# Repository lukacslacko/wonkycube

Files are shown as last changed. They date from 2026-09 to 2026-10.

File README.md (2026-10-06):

# Wonkycube

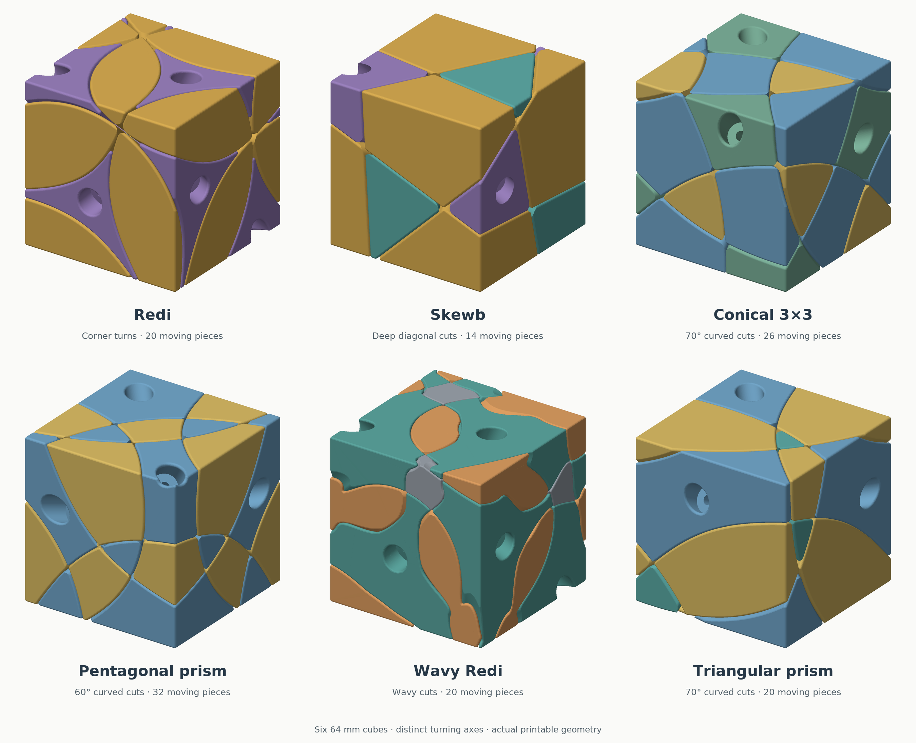
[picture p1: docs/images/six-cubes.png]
Redi, Skewb, conical 3×3, pentagonal prism, Wavy Redi and triangular prism: six 64 mm cube shape mods rendered from the printable models


Six 3D-printable twisty puzzles with **64 mm cube exteriors**, rotated away from their turning axes. Redi, Skewb, conical 3×3, pentagonal-prism, Wavy Redi and triangular-prism designs produce different patterns of cuts and change shape when scrambled. Solve the shape; no stickers are needed.

## Cube shape mods

| Puzzle | What makes it different | Download | Build guide |
|---|---|---|---|
| **Redi** | Eight corner axes; twelve movable edges with distinct outside shapes | [STLs, plates and source](https://github.com/lukacslacko/wonkycube/releases/tag/v4.3) | [Printing and assembly](designs/redi-v4.3/ASSEMBLY.md) · [Piece map](designs/redi-v4.3/NEIGHBORS.md) |
| **Skewb** | Deep planar cuts and diagonal turns; fourteen moving pieces | [STLs, plates and source](https://github.com/lukacslacko/wonkycube/releases/tag/skewb-v1.1) | [Printing and assembly](designs/skewb-v1.1/ASSEMBLY.md) · [Piece map](designs/skewb-v1.1/NEIGHBORS.md) |
| **Conical 3×3** | Six face axes and 70° conical cuts; curved edges and twenty-six moving pieces | [STLs, plates and source](https://github.com/lukacslacko/wonkycube/releases/tag/conical-3x3-v1.1) | [Printing and assembly](designs/conical-3x3-v1.1/README.md) · [Piece map](designs/conical-3x3-v1.1/NEIGHBORS.md) |
| **Pentagonal prism** | Seven axes and 60° conical cuts; 180° side turns, 72° polar turns and thirty-two moving pieces | [STLs, plates and source](https://github.com/lukacslacko/wonkycube/releases/tag/pentagonal-prism-v1) | [Printing and assembly](designs/pentagonal-prism-v1/README.md) · [Piece map](designs/pentagonal-prism-v1/NEIGHBORS.md) |
| **Wavy Redi** | Eight corner axes, twelve broad petals and six exposed patches of the fixed core | [STLs, plates and source](https://github.com/lukacslacko/wonkycube/releases/tag/wavy-redi-v1.1) | [Printing](designs/wavy-redi-v1.1/README.md) · [Assembly and piece map](designs/wavy-redi-v1.1/ASSEMBLY.md) |
| **Triangular prism** | Five axes and 70° conical cuts; 180° side turns, 120° polar turns and twenty moving pieces | [STLs, plates and source](https://github.com/lukacslacko/wonkycube/releases/tag/triangular-prism-v1) | [Printing and assembly](designs/triangular-prism-v1/README.md) · [Piece map](designs/triangular-prism-v1/NEIGHBORS.md) |

All six cube shape mods have been printed by the designer. The 64 mm non-wavy triangular prism printed, assembled and turns well. The Wavy Redi built very well and turns great; its published v1.1 makes two small refinements to nut fit and four exterior tips, checked in CAD and awaiting a reprint. Colors in the render distinguish piece families for illustration; the files can be printed in any colors.

## Vertex-turning rhombic dodecahedron

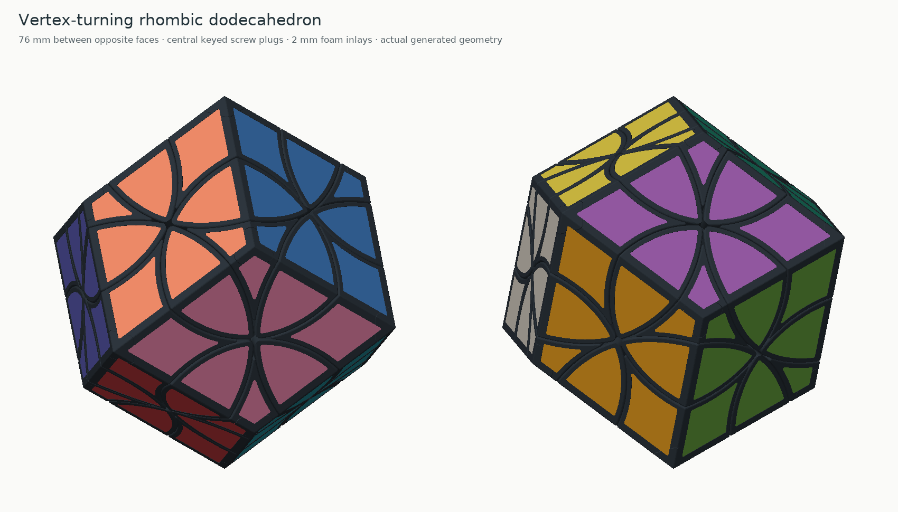
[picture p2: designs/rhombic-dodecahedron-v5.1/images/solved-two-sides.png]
Vertex-turning rhombic dodecahedron with colored inlays, rendered from the printable models


A naturally aligned **rhombic dodecahedron, 76 mm between opposite faces**, with eight threefold centers, six fourfold centers and twenty-four interchangeable petals. The projecting vertices give a grip around every turn axis: 120° at threefold vertices and 90° at fourfold vertices. Concentric spherical-shell shoulders retain the petals.

**Printed, built very well and turns smoothly.** Its twelve rhombic faces take **96 flat 2 mm inlays**, either cut from foam or printed in plastic. Small keyed plugs cover the screws and complete the face dividers. The rigid inlays use exact pocket contours for the snug nominal-size fit demonstrated by the owner; print with **0.00 mm XY contour compensation**.

[Download the complete puzzle](https://github.com/lukacslacko/wonkycube/releases/tag/rhombic-dodecahedron-v5.1) · [Build guide](designs/rhombic-dodecahedron-v5.1/README.md) · [Printable inlays](designs/rhombic-dodecahedron-v5.1/inlays/printable/README.md) · [Piece map](designs/rhombic-dodecahedron-v5.1/NEIGHBORS.md) · [Build feedback](designs/rhombic-dodecahedron-v5.1/physical-feedback.json)

## Curvy Copter cuboctahedron

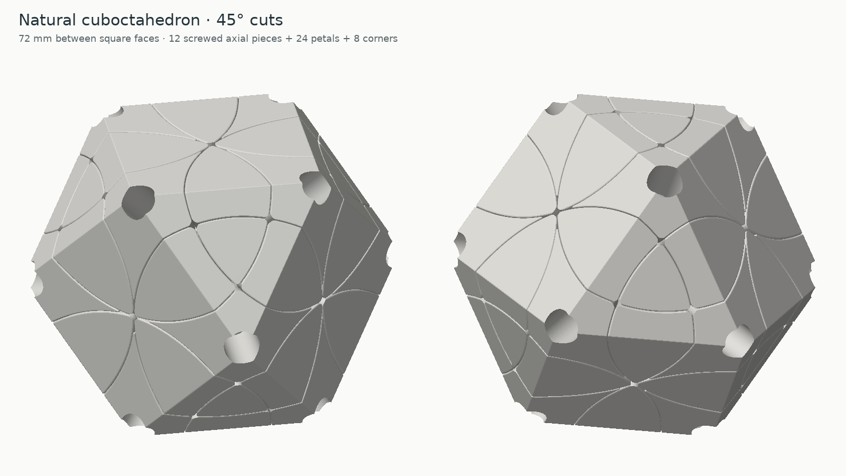
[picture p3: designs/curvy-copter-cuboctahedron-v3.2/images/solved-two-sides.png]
Natural vertex-turning cuboctahedron with Curvy Copter cuts


A naturally aligned **72 mm vertex-turning cuboctahedron** with twelve screwed centers, twenty-four petals and eight floating corners. It has 45° conical cuts, ordinary 180° turns and jumbling moves at suitable partial alignments. Paint the exterior faces with colors or symbols for solving.

**Printed and built very well.** Spherical-shell shoulders retain petals under the screwed centers and corners under the petals. The published v3.2 includes wider petal grooves, tip rounding through the exterior surface and R1.2 rounding of the center-flange outline while preserving its bearing faces. The original vertex-turning cuboctahedron core can be reused.

[Download STLs, plates and source](https://github.com/lukacslacko/wonkycube/releases/tag/curvy-copter-cuboctahedron-v3.2) · [Build guide](designs/curvy-copter-cuboctahedron-v3.2/README.md) · [Piece map](designs/curvy-copter-cuboctahedron-v3.2/NEIGHBORS.md) · [Build feedback](designs/curvy-copter-cuboctahedron-v3.2/physical-feedback.json)

## Double Ivy

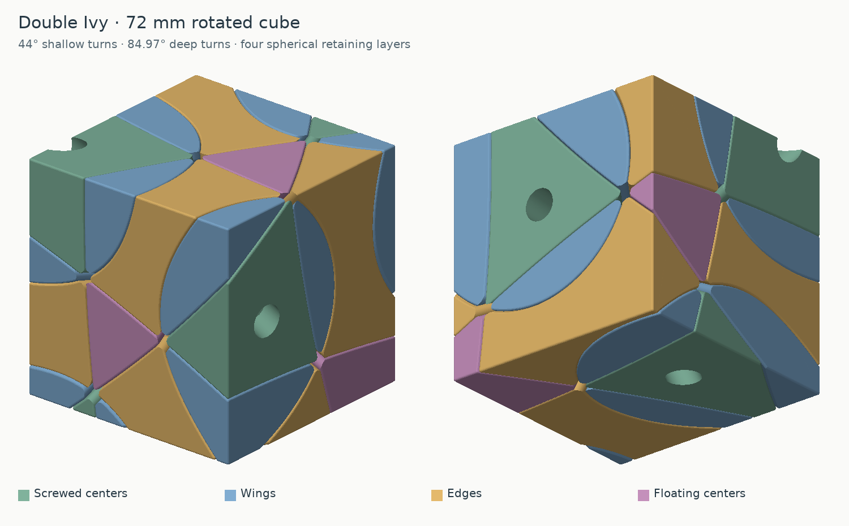
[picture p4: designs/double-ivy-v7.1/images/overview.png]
Double Ivy: a rotated cube with shallow and deep corner turns


A **72 mm rotated cube** with four tetrahedral axes, shallow 44° and deep 84.97° cuts, and twenty-six moving pieces. Four spherical retaining layers hold floating centers under edges, edges under wings, and wings under screwed centers.

**Printed, assembled and turns quite well after working it in.** Two deep turns initially bound and improved with repeated turning. The supplied v7.1 adds a checked outer-ridge rounding correction, which has not yet been reprinted. It includes the compatible tighter nut-seat core for new builds.

[Download STLs, plates and source](https://github.com/lukacslacko/wonkycube/releases/tag/double-ivy-v7.1) · [Build guide](designs/double-ivy-v7.1/README.md) · [Assembly and neighbors](designs/double-ivy-v7.1/ASSEMBLY.md) · [Build feedback](designs/double-ivy-v7.1/physical-feedback.json)

## Make one

Each puzzle uses a printed core, integral retaining feet, **DIN912 M3 × 20 screws** and **DIN985 M3 locknuts**. The six 64 mm cube shape mods, Double Ivy and Curvy Copter cuboctahedron use **9 × 1 mm washers**; the rhombic dodecahedron uses **7 × 0.5 mm washers**, all with M3 clearance holes. The turning mechanisms need no glue or separate hidden printed carriers. Glue is optional for the rhombic dodecahedron’s decorative inlays.

| Puzzle | Printed puzzle parts, including core | Screws / washers / nuts |
|---|---:|---:|
| Redi | 21 | 8 of each |
| Skewb | 15 | 4 of each |
| Conical 3×3 | 27 | 6 of each |
| Pentagonal prism | 33 | 7 of each |
| Wavy Redi | 21 | 8 of each |
| Triangular prism | 21 | 5 of each |
| Rhombic dodecahedron | 53, plus 96 optional printed inlays | 14 of each; **7 × 0.5 mm washers** |
| Curvy Copter cuboctahedron | 45 | 12 of each; **9 × 1 mm washers** |
| Double Ivy | 27 | 4 of each; **9 × 1 mm washers** |

Development used a **Bambu Lab P1S, 0.4 mm nozzle and PLA**. Print at **100% scale** in millimetres. Each build guide covers orientations, supports, nut-fit coupons and assembly guidance. The 3MF plates contain geometry, not a printer profile or G-code. Parts belong to their own mechanism and are not interchangeable between the puzzles.

**Captive nut design:** use the self-contained [DIN985 M3 nut-slot specification](docs/design.md#captive-din985-m3-nut-slot-specification) when designing a part: **5.25 mm terminal seat / 5.85 mm entrance**. The guide defines the taper, axial capture, print orientation and installation-torque fit check. The supplied Redi v4.3 core can let some nuts spin during installation; consult its fit dimensions before printing it.

## Design and modify

Concentric spherical-shell retaining shoulders are the default for new designs: their broad holding faces oppose radial withdrawal. Wider tracks and continuous rounded ridges help pieces pass one another. Screw adjustment controls bearing pressure separately from track clearance.

The [mechanism design guide](docs/mechanism-principles.md) explains these choices, including nut retention, printable flange tips, assembly paths and strong connections around washer wells.

| Design | Mechanism | CAD and regeneration | Checks |
|---|---|---|---|
| Redi | [Design](docs/design.md) | [Source](designs/redi-v4.3/source/README.md) | [Validation](designs/redi-v4.3/VALIDATION.md) |
| Skewb | [Design](designs/skewb-v1.1/DESIGN.md) | [Source](designs/skewb-v1.1/source/README.md) | [Validation](designs/skewb-v1.1/VALIDATION.md) |
| Conical 3×3 | [Design](designs/conical-3x3-v1.1/DESIGN.md) | [Source](designs/conical-3x3-v1.1/source/README.md) | [Validation](designs/conical-3x3-v1.1/VALIDATION.md) |
| Pentagonal prism | [Design](designs/pentagonal-prism-v1/README.md#mechanism) | [Source](designs/pentagonal-prism-v1/source/BUILD.md) | [Validation](designs/pentagonal-prism-v1/VALIDATION.md) |
| Wavy Redi | [Design](designs/wavy-redi-v1.1/README.md#mechanism-choices) | [Source](designs/wavy-redi-v1.1/source/README.md) | [Validation](designs/wavy-redi-v1.1/VALIDATION.md) |
| Triangular prism | [Design](designs/triangular-prism-v1/README.md#retention-and-fit) | [Source](designs/triangular-prism-v1/source/BUILD.md) | [Validation](designs/triangular-prism-v1/VALIDATION.md) |
| Rhombic dodecahedron | [Design](designs/rhombic-dodecahedron-v5.1/README.md#mechanism-and-validation) | [Source](designs/rhombic-dodecahedron-v5.1/source/BUILD.md) | [Validation and build feedback](designs/rhombic-dodecahedron-v5.1/VALIDATION.md) |
| Curvy Copter cuboctahedron | [Design](designs/curvy-copter-cuboctahedron-v3.2/README.md#mechanism) | [Source](designs/curvy-copter-cuboctahedron-v3.2/source/BUILD.md) | [Validation and build feedback](designs/curvy-copter-cuboctahedron-v3.2/VALIDATION.md) |
| Double Ivy | [Design](designs/double-ivy-v7.1/DESIGN-NOTES.md) | [Source](designs/double-ivy-v7.1/BUILD.md) | [Validation and feedback](designs/double-ivy-v7.1/VALIDATION.md) |

Designed and physically iterated by **László Lukács**, with CAD, optimization and documentation developed with **OpenAI Codex**. Source, documentation and original generated models are available under the [MIT license](LICENSE).

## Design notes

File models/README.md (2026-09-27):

# Model versions

Downloads and build guides for all six 64 mm cube designs are listed in the [project overview](../README.md#choose-a-cube), including the [non-wavy triangular prism](../designs/triangular-prism-v1). These are separate mechanisms; their parts do not interchange.

The directory named `current` is retained from the first publication and contains
the **80 mm v4.2.1** files. It is kept intact so earlier hashes and reproduction
scripts remain valid. It is not the latest compact set, and its parts and hardware
do not interchange with v4.3.

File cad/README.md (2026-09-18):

# CAD and reproduction — 80 mm v4.2.1

This directory and the root `scripts/reproduce.py` reproduce the older 80 mm
version. For compact v4.3 use [its source and build instructions](../designs/redi-v4.3/source/README.md).
For the trimmed Skewb v1.1 use [the Skewb source and build instructions](../designs/skewb-v1.1/source/README.md).

Python 3.11 was used for the publication export. Dependencies are pinned in [requirements.txt](../requirements.txt). No OpenSCAD or proprietary CAD runtime is required.

From the repository root:

```sh
python3.11 -m venv .venv
.venv/bin/python -m pip install -r requirements.txt
.venv/bin/python scripts/reproduce.py --out build/reproduced
```

On Windows, use `.venv\Scripts\python.exe`. The reproduction script builds into a new directory and runs the mechanism, revision, radius and shape checks. It stops on any failure and will not overwrite an existing output directory. Computation can take several minutes. Exact STL byte ordering can depend on library/platform details; the geometric checks are the acceptance criteria. Released file hashes identify the specific checked export.

## Source map

| File | Role |
|---|---|
| `mechanism.py` | Shared geometry, axes, transforms and original prototype primitives |
| `poc_mechanism.py` | Direct-to-plastic screw core and early flat-foot prototype |
| `mechanism_v3.py` | 80 mm stepped-rail geometry, proper feet, exterior rounding and hardware envelopes |
| `exact_assembly_sweep.py` | Nonconvex axial insertion envelope |
| `mechanism_v4.py` | Unrounded flange sweep, wider tracks and internal rounding |
| `mechanism_v4p1.py` | Earlier 2 mm ridge fillets with an inner blend |
| `mechanism_v4p2.py` | Constant 3 mm transverse ridge fillets following the inner track |
| `build_v4p2.py` | Current export, using the fixed v4.1 baseline |
| `v3_io.py` | Closed STL export and geometry-only 3MF writer |
| `verify_v3.py` | General saved-mesh, motion, hardware and assembly verifier (name retained) |
| `verify_v4p2.py` | Revision locality, mixed old/new motion, retention and misalignment probe |
| `verify_radii_v4p2.py` | Section fits on the actual print STLs |
| `check_edge_shapes_v3.py` | All 66 edge-exterior pair comparisons |
| `optimize_rotation.py` | Original exterior-orientation search |
| `draw_v4p2.py`, `mesh_render.py` | Actual mesh-section diagrams and software-rendered previews |

## Changing the design

The fast current build starts from [baseline](baseline), not from a single fully parametric solid. That is intentional: the latest revision removes only ridge material while preserving printed interfaces. Adjust `RADIAL_RIDGE_ROUND` in `mechanism_v4p2.py` to experiment with that cut, then update the radius verifier's explicit target and rerun all relevant checks. A bigger radius can remove retention material and is not automatically safe.

To change the exterior, hardware, core or original rail, rebuild the chain from its source. Run these from the repository root, using fresh output paths:

```sh
.venv/bin/python cad/build_v3.py --out build/v3p1
.venv/bin/python cad/build_v4.py --base build/v3p1 --out build/v4
.venv/bin/python cad/build_v4p1.py --base build/v4 --out build/v4p1
.venv/bin/python cad/build_v4p2.py --base build/v4p1 --out build/new-design
```

These earlier generators are preserved for design work. The publication check starts at the supplied baseline; a complete fresh upstream rebuild is not claimed byte-identical to historical archives. Rounding is expensive, and parameter changes can produce thin/disconnected geometry that requires redesign rather than export repair. Validate each stage before relying on the next. Any source constants used by verification must agree with the generated geometry.

The original optimization uses a 100 mm cube for scoring. Uniform exterior size changes scale those scores, not the selected orientation. Its `rotation.json` output is an exploration result; the retained `chosen_rotation.json` also includes an equivalent symmetry relabeling. Do not automatically replace the chosen rotation when reproducing the released shape.

For individual current checks:

```sh
.venv/bin/python cad/verify_v3.py --out models/current
.venv/bin/python cad/verify_v4p2.py --base cad/baseline --out models/current
.venv/bin/python cad/verify_radii_v4p2.py --out models/current
.venv/bin/python cad/check_edge_shapes_v3.py --out models/current
```

These commands rewrite their JSON reports. Use a copied output folder when preserving a published checksum manifest.

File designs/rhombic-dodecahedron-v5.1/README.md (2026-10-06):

# Vertex-turning rhombic dodecahedron — spherical retention and 2 mm inlays

The generated puzzle, with example foam colors

A fourteen-axis puzzle with **8 threefold centers, 6 fourfold centers and 24 floating petals**. Threefold vertices turn 120°; fourfold vertices turn 90°. Each turning axis has a projecting vertex to grasp. Its twelve rhombic faces carry **96 flat 2 mm inlays**, either cut from foam or printed in plastic.

**76 mm between opposite faces, 107.48 mm between the longest opposing vertices, and 93.08 mm between opposite threefold vertices.** Print at 100% scale: the hardware, clearances and foam thickness are fixed dimensions.

Each screwed center keeps its **complete outer rim, most of the foam-pocket floors and the divider walls away from the screw**. A small central plug closes the screw well and completes the inner three- or four-way divider pattern. Its rounded triangular or square section locates it at the appropriate 120° or 90° orientations.

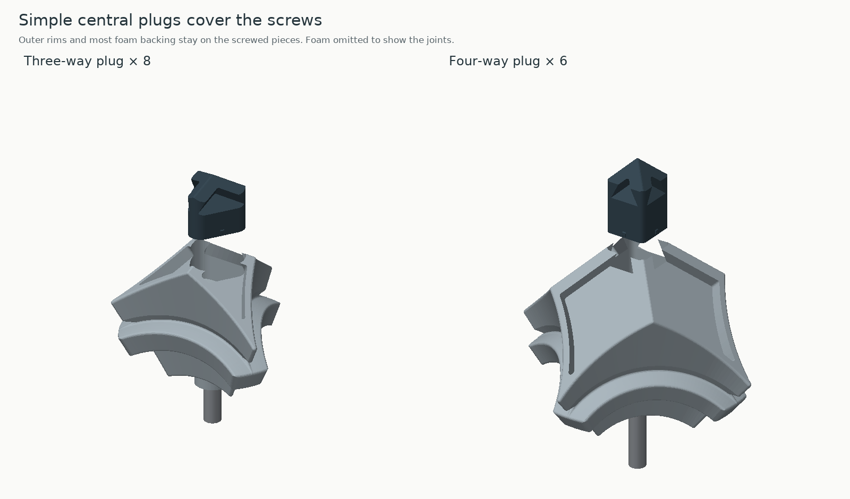
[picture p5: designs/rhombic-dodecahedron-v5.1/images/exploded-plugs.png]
Central plugs lifted from the screwed pieces


The **foam spans the joint between the main piece and the plug**. Fit and adjust the puzzle first, then glue the foam over both as desired. To service a screw later, remove the affected center's foam, pull the plug, and replace the foam after adjustment. The cutting sheets are provided for that purpose; the design does not depend on preserving the foam during disassembly.

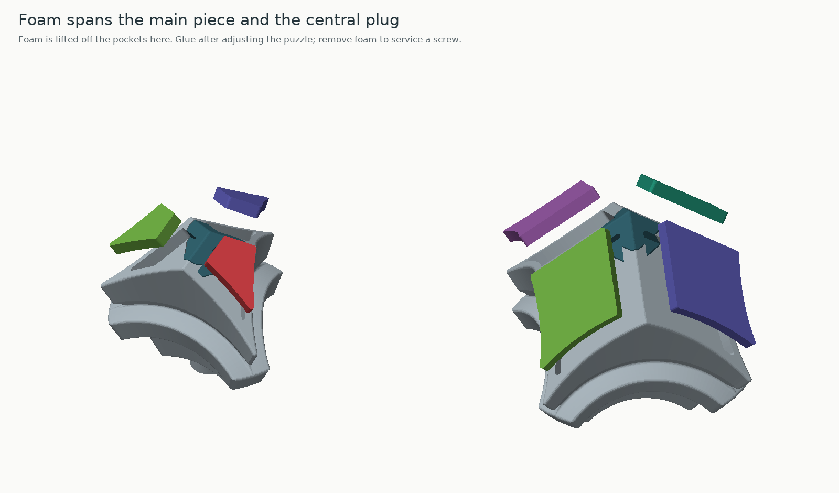
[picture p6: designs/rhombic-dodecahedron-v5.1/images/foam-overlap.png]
Foam lifted to show the shared pocket floors


Threefold-center inlay panels are approximately **54.49 mm² each**, and fourfold-center panels **194.49 mm² each**. Use the complete set of screwed bases, petals, plugs and cutting sheets together. The retaining interfaces and foam recesses match this set; do not mix surface pieces from the stepped-retention or 3 mm-foam sets. Only the central screw region is split; the outer rim has no cap joint or pry notches.

The **face-turning cuboctahedron v1 core is directly reusable**, with its nuts left in place. The supplied core has the identical SHA-256 `2424250181e27338f25ef90b7bbe66e7d5ba9beca6b5c5e347a9555a172ab8cc`. This means the fourteen-axis face-turning puzzle's core. The twelve-axis curvy-copter core does not fit. All surface parts and cutting sheets in this package match the 76 mm exterior and should be used together.

**Printed and built very well, and turns smoothly**, as reported by the owner. The nominal-size rigid inlays fit nicely snugly. See [physical feedback](physical-feedback.json) and the [validation summary](VALIDATION.md) for the supplied geometry, exact inlay fit evidence and scope of the CAD checks.

## Print list

| File in `stl/puzzle/` | Copies | Role |
|---|---:|---|
| `threefold-center-print-8.stl` | 8 | T01–T08 screwed bases |
| `threefold-plug-print-8.stl` | 8 | Central threefold plugs for T01–T08 |
| `fourfold-center-print-6.stl` | 6 | S01–S06 screwed bases |
| `fourfold-plug-print-6.stl` | 6 | Central fourfold plugs for S01–S06 |
| `petal-print-24.stl` | 24 | P01–P24 floating petals |
| `core.stl` | 1, or reuse | Fourteen captive nuts |

There are **53 printed puzzle parts including the core**, forming 38 moving units. Every copy within a family is identical. The three geometry-only 3MF plates in `plates/` contain the required quantities, with SVG placement maps. The center/core plate includes a core: delete it in the slicer if reusing yours. Use either the plates or the STL quantities, not both. Files under `reference/` show the assembled puzzle and are not print plates.

Additional files:

- `stl/fit-coupons/cap-key-fit-tests.3mf`: two socket/peg pairs; also supplied as four separate STLs.
- `stl/fit-coupons/foam-pocket-test.stl`: tests actual foam thickness and cutting fit.
- `stl/fit-coupons/nut-fit-5.25.stl`: useful if printing a new core.
- `stl/optional/assembly-stand.stl`: optional temporary assembly tool.

Suggested P1S / PLA / 0.4 mm nozzle settings: 0.16 mm layers, five walls, five top/bottom layers, and 25–30% infill for the moving parts. Use six walls and 40% infill for a new core. For the main pieces and petals, start with automatic tree supports on the build plate only and a 5–6 mm brim. Inspect support under the retaining shoulders. The compact plugs stand on flat key bottoms and can be printed without supports; use five top/bottom layers and inspect the small friction ribs in the slicer. The key fit samples also print without support.

The STL orientations put the inward radial direction down and the foam pockets upward. Avoid shaving the small key ribs during cleanup. Remove any elephant's foot at a key's entry. Plate spacing allows the suggested brims; the 3MF files contain geometry rather than printer/material presets. Layer-connectivity checks pass at both 0.16 and 0.20 mm layers; these are geometric extrusion-width checks, not actual Bambu toolpaths.

## Plug fit and removal

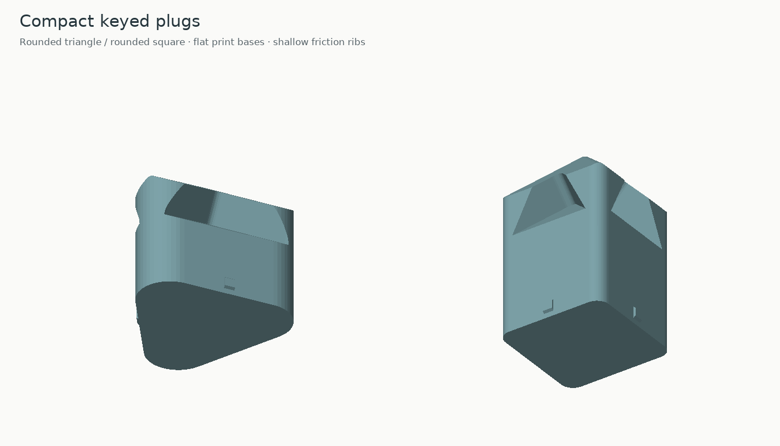
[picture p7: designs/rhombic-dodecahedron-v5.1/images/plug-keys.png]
Compact plugs and their locating keys


The whole plug is a rounded triangular or rounded square key; there is no large removable foam carrier. It has a flat bottom, a pocketed top matching the exterior, and small tapered ribs on its sides for light friction. The main piece retains the surrounding divider walls and pocket floors.

| Feature | Dimension |
|---|---:|
| Female key across flats | 8.00 mm |
| Socket corner rounding, triangular / square | R2.25 / R1.00 mm |
| Rigid male-key clearance | 0.12 mm per side |
| Small tapered friction ribs | 0.04 mm beyond the socket flat |
| Threefold plug clearance above seated screw head | 1.10 mm |
| Fourfold plug clearance above seated screw head | 9.20 mm |

The ribs provide localized friction while the rest of the key has clearance. Print the key samples at the final layer height. Push the ribbed end of each tall peg into its matching shallow socket. It should seat with modest hand pressure, stay in when inverted and remain removable. If tight, scrape only the ribs lightly. If loose, adjust the rib fit rather than scaling the entire part. A full pair is the final fit test.

Test the plugs before fitting any foam. Press them down until their outer surfaces and divider walls align with the main piece. To remove a plug, first remove that center's foam, then grip the central divider with fingers or protected pliers, or lift gently at the exposed plug joint. Pull along the screw axis; the key prevents free twisting. Do not glue the key into its socket. Gluing the foam across the top joint is intentional and acceptable.

## Hardware

- 14 × DIN912 M3×20 socket-head screws.
- 14 × M3 washers, **7 mm outside diameter × 0.5 mm thick**.
- 14 × DIN985 M3 nylon locknuts.
- A 2.5 mm hex key; a blunt metal rod for seating nuts in a new core.

No extra screws, magnets or fasteners are required for the plugs. The wells are Ø7.6 mm and the rotating screw bores Ø3.6 mm. Washer seats lie 32.0 mm along T axes and 27.3 mm along S axes. The plug sockets pass the washers and driver when the plugs are removed.

The nut pocket has a **5.25 mm terminal across-flats size**, a 5.85 mm entrance, a 3 mm tapered transition and a 3 mm tight run to the seated nut. Pocket height is 4.25 mm, with a 1.95 mm roof. Press each nut firmly home with its metal entry face outward and nylon ring inward. Confirm resistance to the nylon ring's installation torque before building around the core.

## Assembly

1. Seat and torque-check the nuts if using a new core. Leave the plugs and foam off.
2. Assemble a **loose, interlocked shell** around the core, keeping all fourteen centers unscrewed. Add petals between their T and S neighbors, engaging their inner feet beneath the spherical flanges. Use `NEIGHBORS.md` and temporary masking tape to support the loose pieces. Keep the whole shell somewhat expanded while adding parts; do not fasten one side tightly first.
3. If using the optional stand to support the core initially, remove it **while the shell is still loose**, then add S01. It is not intended to reserve a final straight-in slot after tightening the rest.
4. Gradually close the shell, easing neighboring centers and petals inward together. Fit washers and start screws once the pieces are seated. Tighten all fourteen progressively and evenly. The full shoulders mean a final center cannot simply be pushed straight into already fixed petals.
5. Adjust until the petals are supported without binding. M3 coarse pitch is 0.5 mm per revolution; one fifth of a turn changes head position by 0.10 mm. Judge tension by movement, separately from the nut's nylon-ring resistance.
6. Test all turns with the plugs seated and without glued foam. Remove plugs for any further screw adjustment.
7. Once satisfied, fit and glue the foam one numbered face at a time. Center foam may be glued over both the main piece and its plug. Petal foam is glued to its petal. Keep glue out of moving seams and allow it to cure before turning.

The CAD assembly check constructs a loose state with centers 12 mm outward and petals 11.4 mm outward from their seated positions. Each part has a clear radial entry into that state. A coordinated contraction, with petals moving 0.95 mm per 1 mm of center travel, then reaches the seated shell without collision. These are coordinates of a verified construction, not distances you need to measure by hand. Several pieces must remain movable together; this is not a last-piece snap-fit. The owner has also successfully assembled the complete physical puzzle; the CAD path is one construction, not a measurement of the exact hand assembly sequence used.

## Foam and cutting files

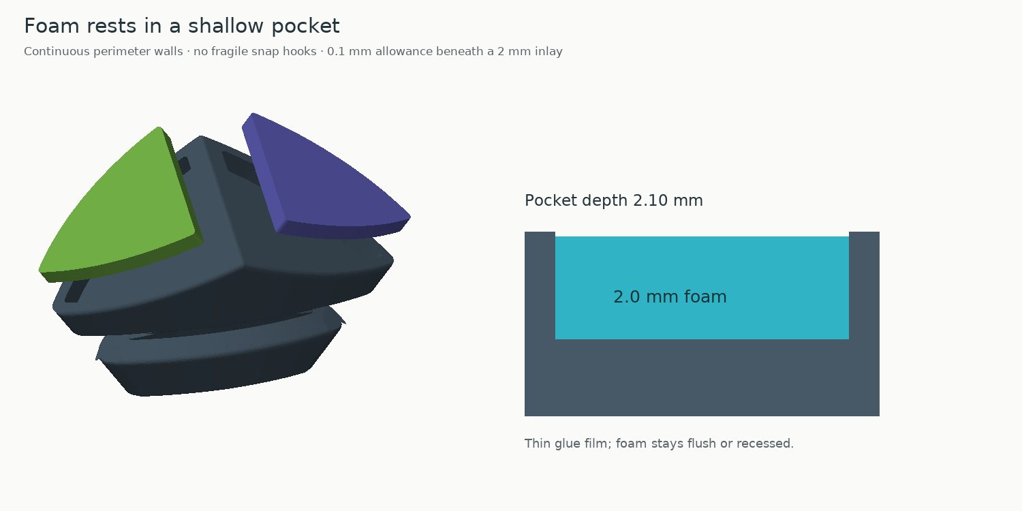
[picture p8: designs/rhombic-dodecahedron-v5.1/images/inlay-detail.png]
Foam pocket relationship


There are **96 inlays: eight per rhombic face**. Each assembled T center has three, each S center four, and each petal two. Recesses are **2.10 mm deep for 2.00 mm foam**. Without glue the foam lies 0.10 mm below the plastic; a thin glue film can bring it flush. Do not allow foam or adhesive to protrude into the moving seams.

Continuous pocket walls grip the foam by slight compression; there is no overhanging snap hook. The nominal outer border is 1.0 mm, widened where needed. Adjacent-face recesses leave at least **1.6 mm of plastic between their full-depth voids**. The generated pockets preserve a 1.2 mm underlying floor envelope and 0.775 mm lateral web before the central plug is separated. The assembled pocket floor is checked to remain supported everywhere except the narrow plug-fit joint. Foam bridges that joint.

The Cameo files contain **closed outline cuts only**, without text, borders, registration marks or duplicate outlines. Each F01–F12 file contains the eight inlays for one face. Cut each face once, one color per face; with fewer colors, add markings to distinguish the faces. No mirroring is needed with the foam's colored side upward.

Use the **DXF** files for Silhouette Studio Basic. SVG import requires Designer Edition or above. Genuine DWG is supplied as the requested CAD format, but Silhouette's listed import formats do not include DWG. See the official [file-format guide](https://silhouetteamerica.freshdesk.com/support/solutions/articles/35000282776-file-types-and-features) and [DXF guidance](https://silhouetteamerica.freshdesk.com/support/solutions/articles/35000276938-importing-and-exporting-troubleshooting).

DXFs are R13 ASCII with closed 2D POLYLINEs. SVGs have explicit millimetre dimensions. DWGs are AutoCAD 2000 / AC1015, encoded with ODA and independently read back with LibreDWG; each resulting contour is compared with its source. Curve simplification tolerance is 0.008 mm.

### Select the foam fit before cutting the full set

1. Import `inlays/fit-test/calibration-20mm.dxf`. Verify a **20.00 × 20.00 mm** selection and measure the cut sample. DXF import settings can affect scale.
2. Print the pocket sample and cut `inlays/fit-test/foam-size-options.dxf` in the actual foam. Left to right: easy, standard, firm. Choose the smallest that stays flat and grips as desired.
3. Use **one complete cutting set** below. Select blade/pass settings for your Cameo model and actual foam; no untested machine preset is supplied.

| Set | Folder | Offset from pocket outline |
|---|---|---|
| Easy | `inlays/fit-variants/easy/` | −0.04 mm per side |
| Standard | `inlays/faces/` | +0.04 mm per side |
| Firm | `inlays/fit-variants/firm/` | +0.12 mm per side |

These are contour offsets, not uniform scale factors. All variants match the same printed pockets. Check the selected outlines rather than the 82 mm SVG page. Exact selection bounds for each face and fit variant are in `reports/cutting-files.json`; use the supplied 20 mm calibration square to confirm import scale.

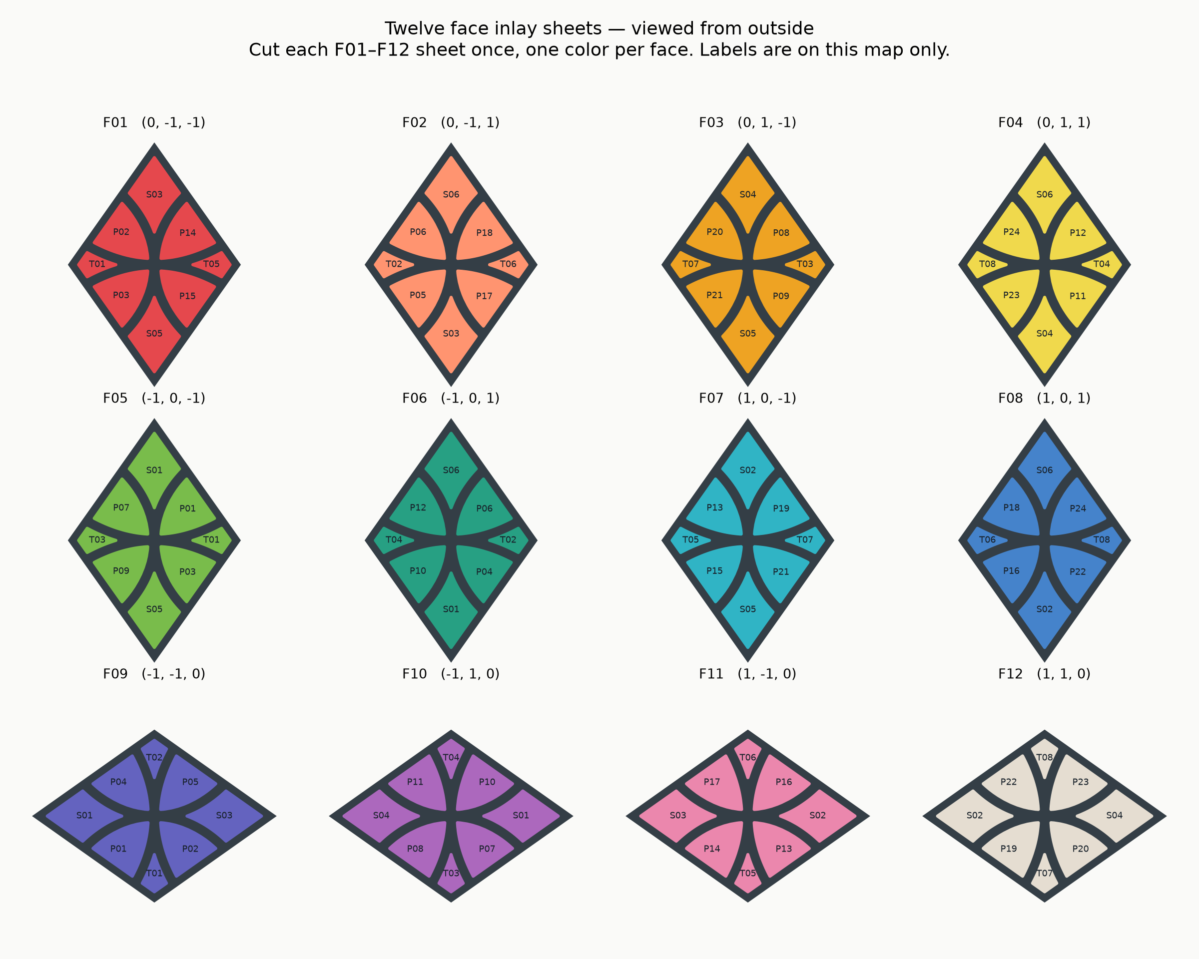
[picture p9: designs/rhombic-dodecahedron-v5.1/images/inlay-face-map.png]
Face-by-face cutting and placement map


The map is viewed from outside in the same orientation as each cutting sheet. Keep a face's eight cut pieces together. The T and S labels identify the assembled screwed centers; P labels identify petals. Use only the cutting sheets supplied with these 76 mm parts.

## 3D-printed inlays

You can mix **2 mm printed plastic inlays** with foam on any faces. The existing puzzle parts and 2.1 mm pockets accommodate both. Use `inlays/printable/faces/F01.3mf` through `F12.3mf`, or their matching STLs, to print the eight separate inserts for a selected color/face. Individual replacements are under `inlays/printable/individual/Fxx/`. Print each selected face once, using either its STL or its 3MF.

The rigid inserts **exactly match the pocket contours**, with **zero designed clearance**. Use **0.00 mm XY contour compensation**: do not apply an additional +0.15 mm correction. Nominal-size inlays were reported to fit nicely snugly; a thin glue layer is optional. Keep their tops flush or slightly recessed. Print flat as supplied, visible side upward, at 100% scale; 0.20 mm layers, at least five top/bottom layers, no supports or brim. Print one face first to check physical fit. The face plate contains eight disconnected pieces, with no backing sheet joining moving puzzle parts.

See `inlays/printable/README.md` and its placement map. On screwed centers these inserts still bridge the base/plug joint; finish adjustment before gluing and expect to remove the affected inlays for screw access. The original SVG/DXF/DWG files remain the foam cutting options.

## Mechanism and validation

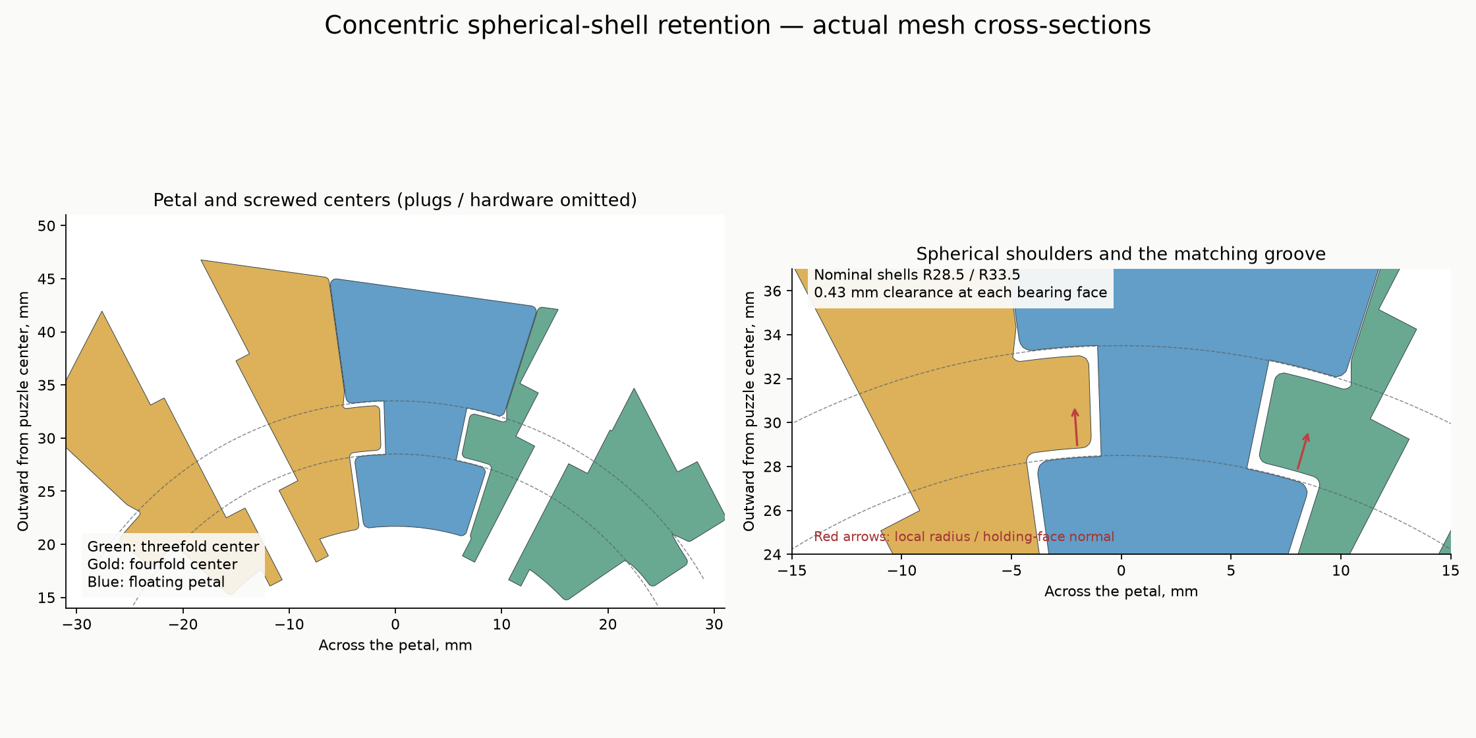
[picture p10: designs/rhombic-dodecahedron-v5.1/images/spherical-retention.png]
Actual spherical retaining shoulders in section


The core anchors the fourteen adjustable centers. The floating petals have inner feet captured below **concentric spherical-shell flanges** on both center families. The nominal shell radii are 28.5 and 33.5 mm, centered at the puzzle origin. Their broad holding faces have normals along the local radius; the small edge transitions are rounded. The center flanges are approximately 4.20 mm thick radially and run in 5.06 mm radial grooves, leaving **0.43 mm at each spherical bearing face**. The inner feet are checked against the screwed centers alone, without crediting contact with neighboring floating bodies. Threefold centers have continuous screw stems; petal tracks clear the stems' full sweep. Exterior cone half-angles are 35.264389683° at the threefold axes and 45° at the fourfold axes.

| Feature | Dimension |
|---|---:|
| Main conical-face gap, total | 0.06 mm |
| Additional track-cutter expansion | 0.37 mm |
| Spherical shoulder / outer return radii, nominal | R28.5 / R33.5 mm |
| Spherical bearing gap, per face / total groove slack | 0.43 / 0.86 mm |
| Hidden neck half-angle, threefold / fourfold | 29.2644° / 39° |
| Center flange-end outline rounding, radial sweep | R1.2 mm |
| Petal radial-ridge rounding, through the tracks | R2 mm |
| Other edge rounding, petal / center | R0.55 / R0.45 mm |
| Core sphere / moving inner cavity | R21.2 / R21.7 mm |
| Core bearing pad / center foot plane | 19.6 / 19.7 mm along axis |
| Foot / rotating bore diameter | 6.2 / 3.6 mm |

Validation reloads the delivered STLs and checks connected watertight parts, washer-root and bore walls, ordinary turns about all fourteen axes at 3° intervals with hardware present, destination fit, sampled petal retention and rocking, inner-foot capture by centers alone with 0.15 mm center lift, coordinated assembly, nut insertion, stand removal, and layer connectivity at 0.16 and 0.20 mm layers. Spherical bearing faces are measured on the exported meshes. Installed foam is checked at flush height during turns and assembly. Plug checks cover extraction after foam removal, screw clearance, shared foam backing, correct key symmetry, unintended rotation and bounded intentional rib interference.

These finite rigid-geometry checks do not establish real press-fit force, fatigue, support quality, foam grip or every possible elastic escape path. Inspect slicer previews and test a pair before committing to all copies. Source and generated design are MIT licensed. `source/BUILD.md` explains regeneration; `reference/design-parameters.json` records dimensions and key profiles; `manifest.json` records quantities, transforms and STL hashes.

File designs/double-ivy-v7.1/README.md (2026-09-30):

# Double Ivy · 72 mm · spherical retainers

Double Ivy rotated cube

A rotated-cube shape mod with **four tetrahedral axes and two 120° turns per axis**: shallow 44° cones and deep 84.96955° cones. It has four screwed centers, twelve wings, six edges and four floating centers. Solve it by restoring the cube shape; the illustration colors identify piece families.

**Printed, assembled and now turns quite well after working it in**, reported by the owner on 2026-09-30. The shallow turns were smooth immediately; two deep turns initially bound strongly and improved with repeated movement. The exact cause was not established. The published v7.1 includes a small **outer-ridge rounding correction that has been checked in CAD but not yet reprinted**. [Physical feedback](physical-feedback.json) · [Validation](VALIDATION.md).

The spherical retaining layers run outward as **floating-center feet → edge feet → wing feet → screwed-center flanges**. A compatible one-piece nut core supports the assembly, with integral E/W bearing webs limiting inward rocking.

## Size and layers

The solved cube measures **72 mm**. Its exterior room keeps assembly clearances beneath the skin while preserving usable retaining shoulders.

| Part family | Hidden layer begins at radius | Nominal retaining-foot limit / collar end | Held by |
|---|---:|---:|---|
| F01–F04 floating centers | 19.5 mm | 22.4 mm | Edges |
| E01–E06 edges | 22.6 mm | 25.55 mm | Wings |
| W01–W12 wings | 25.6 mm | 28.8 mm | Screwed centers |
| C01–C04 screwed centers | 29.0 mm | 31.2 mm | Screws into the old core |

Radii are measured from the puzzle center. The table describes the hidden feet/collars, not the entire visible piece; every part also has a stem/body reaching the outer cube. Profile offsets and rounding move local boundaries slightly. The C bearing stems reach inward to the unchanged core pads; their flanges remain at the outermost retaining level. Integral bearing webs under E and W also reach inward to the spherical core. These webs provide inward support, without adding retaining lips or changing the four flange levels.

The nominal internal profiles are: low deep-cut band R22.4–25.3 at 78°; middle shallow-cut band R25.55–28.45 at 49°; high deep-cut band R28.8–31.2 at 81°. The outer surfaces return to the original 44° / 84.96955° cones.

## What to print

Print **27 puzzle pieces**: C01–C04, W01–W12, E01–E06, F01–F04 and one core, from `stl/puzzle`. The five full-set geometry-only 3MF plates in `plates/` contain exactly these parts. Print in millimetres at **100% scale**. Keep the IDs for [assembly and the complete neighbor map](ASSEMBLY.md).

Use **four DIN912 M3×20 screws, four DIN985 M3 nuts and four 9 mm OD × 1 mm washers**, with M3 clearance. No glue, magnets, split core or separate hidden carriers are needed.

The default core has **5.25 mm final nut seats and 5.85 mm loading entrances**. A 5.20 mm alternative and fit coupons are included; see [CORE.md](CORE.md). The original compatible one-piece double-Ivy core can also be reused, keeping its nuts installed. The grooved/split cores are not substitutes. `reference/reused-core/core.stl` is the archived 5.40 mm-seat core, not the new-build default.

For an existing v7 build, only the eight C/F pieces have changed; the wings and edges are unchanged. The core update is optional for a core whose nuts already hold securely.

## Clearances, rounding and hardware

- 0.30 mm nominal track gap, measured surface-to-surface in the meridian profile; not 0.30 mm removed from each side.
- 0.05 mm main exterior conical-face gap.
- R19.5 floating-center cavity around the original R19.2 core.
- E/W bearing webs have an R19.4 spherical inner surface: 0.20 mm nominal radial clearance to the old core. The webs are clipped to the legal turn cells, with 0.25 mm edge rounding. They need no grooves or changes to the core.
- 2 mm radial-ridge rounding. The C/F exterior correction completes both sides of the arc, blending from ridge station 32.2 to 33.4 mm while preserving the retaining region. About 0.30 mm small internal rounding and 0.60 mm exposed-edge softening remain.
- Original washer seat at 27.3 mm along each screw axis, 9.6 mm access well and 3.6 mm screw bore.
- The higher C flange connects through a thicker, integral stem. Its upper outside diameter is 12.8 mm, giving a nominal 1.6 mm wall around the access well above the washer seat. It tapers back to the original bearing foot.

The broad retaining faces are spherical, centered on the puzzle center. They directly oppose outward lift. Higher grooves in E and F are **passage clearances for other turning flanges**, not extra load-bearing layers. Removing the unused upper E shoulder keeps the intended F–E–W–C order.

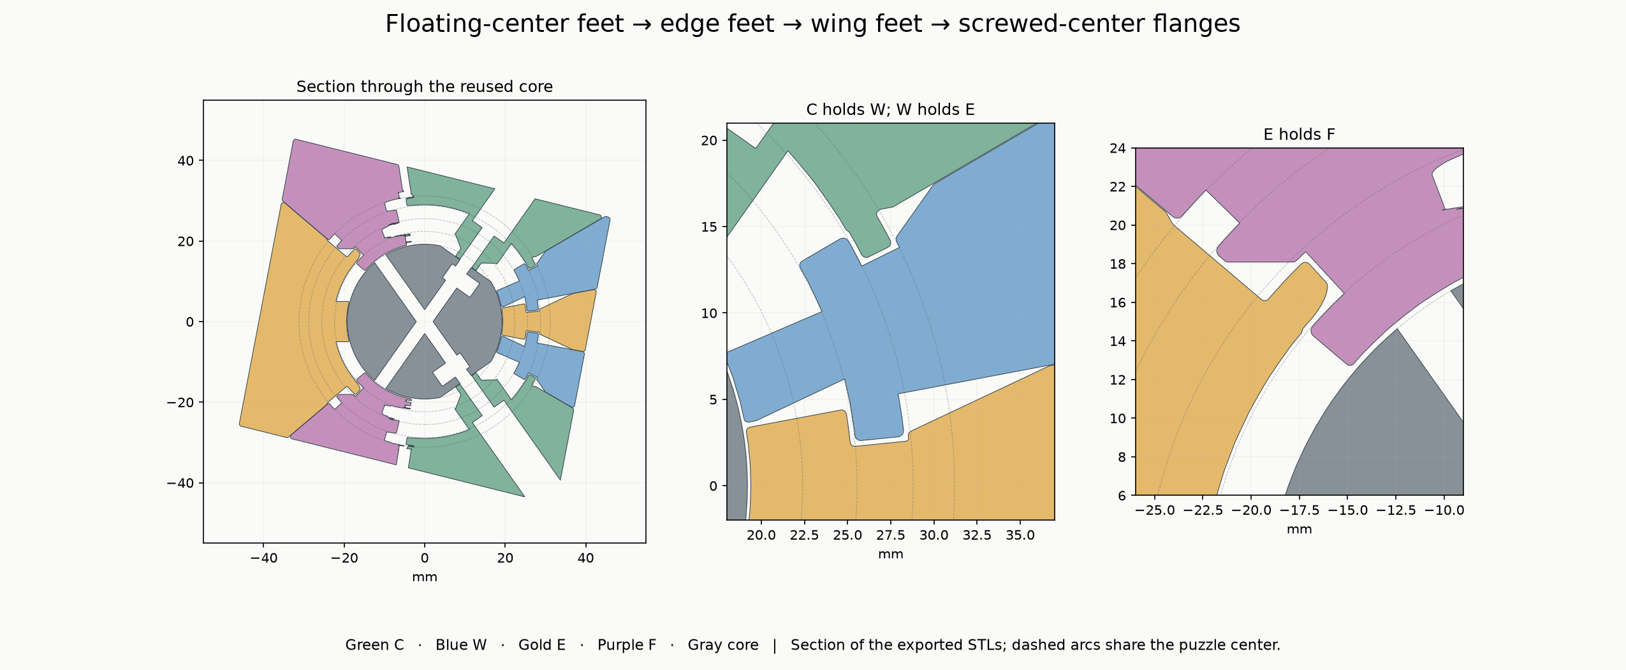
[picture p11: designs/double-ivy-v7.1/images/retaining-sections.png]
Retaining sections


## Printing

Use the proven P1S / 0.4 mm nozzle / PLA process. A starting point is 0.20 mm layers, 4 walls and 15–20% infill. Auto tree supports on the build plate are suitable for an initial slice; inspect the undersides of the collars and add a local support if needed. These geometry-only 3MFs contain names and placements, not filament or support presets.

C pieces rest on a large exterior flat face. W/E/F are oriented with the vector toward the puzzle center pointing down. A brim is helpful on the smaller inward contact patches; inspect the slice to ensure the E/W bearing webs have support where needed. Remove support residue carefully from the sliding surfaces, without shaving away the broad spherical shoulders. Mark the full ID inside each piece before removing it from its plate. The image colors distinguish families only; the puzzle can be printed in one color and solved by shape.

[Assembly sequence and complete neighbor list](ASSEMBLY.md) · [Validation and limits](VALIDATION.md) · [Design notes](DESIGN-NOTES.md) · [Plate maps](plate-maps.html)

Parameterized source, reports and exact print transforms are included under the MIT license.

## Rounding correction

Some symmetric C/F ridges retained a sharp half-rounded shoulder because the tangent detection selected only one side. v7.1 completes the R2 outer arc without changing the internal holding geometry. This removes a confirmed defect; it is not claimed to be the proven cause or cure of the initial binding.

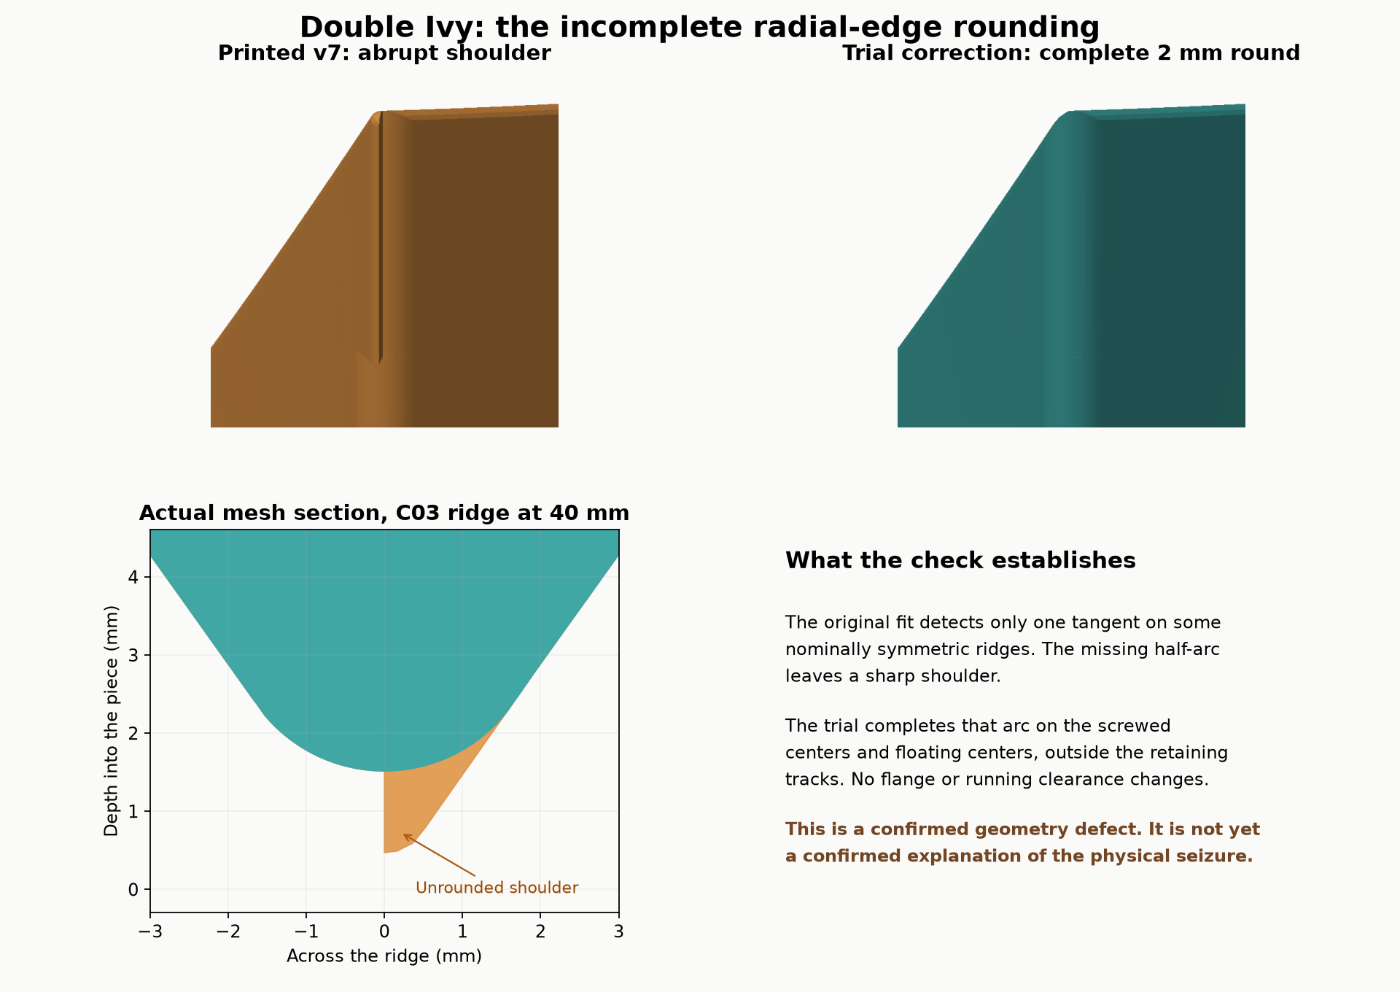
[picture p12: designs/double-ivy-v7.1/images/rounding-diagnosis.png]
Rounding correction


[Source and rebuilding](BUILD.md) · [Design notes](DESIGN-NOTES.md). MIT licensed.

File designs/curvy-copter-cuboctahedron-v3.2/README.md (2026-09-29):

# Curvy Copter cuboctahedron · spherical v3.2

Natural cuboctahedron with 45° conical cuts

A **vertex-turning cuboctahedron** with Curvy Copter mechanics: twelve screwed axial pieces, twenty-four petals, eight floating corners and a one-piece core. It measures **72 mm between opposite square faces**, uses 45° exterior conical cuts, and permits ordinary 180° turns plus jumbling moves at suitable partial alignments. Paint the exterior faces with colors or symbols; the natural alignment does not distinguish every piece by shape alone.

**Printed and built very well**, reported by the owner on 2026-09-29. The supplied spherical-v3.2 print geometry is unchanged. [Build feedback](physical-feedback.json) · [Validation](VALIDATION.md).

## Print the puzzle

| File in `stl/puzzle/` | Quantity |
|---|---:|
| `axial-center-print-12.stl` | 12 |
| `petal-print-24.stl` | 24 |
| `corner-print-8.stl` | 8 |
| `core.stl` | 1 |

There are **45 printed puzzle parts**. Alternatively use the three full-set 3MF plates in `plates/`; together they contain the entire puzzle, including the core. Every copy in one family is identical. Geometry-only 3MF files include positions and names, without printer/material/support presets. Files marked `DO-NOT-PRINT` are reference assemblies.

Hardware: **12 DIN912 M3×20 screws, 12 DIN985 M3 locknuts and 12 washers with 9 mm outside diameter and 1 mm thickness**, with M3 clearance holes. Fit coupons and optional core nut-seat widths are supplied.

The original **64 mm vertex-turning cuboctahedron core is compatible**: its mounting geometry was preserved as the exterior grew to 72 mm. Existing embedded nuts can stay installed. The face-turning cuboctahedron is a separate mechanism with different hardware; its core is not the intended substitute. Do not mix floating pieces from the earlier cylindrical-retention version.

Use the supplied orientations at **100% scale in millimetres**. Development used a P1S, 0.4 mm nozzle, PLA and 0.20 mm layers. Four walls and about 25% infill are starting settings, not a record of the final successful slice. Petals point inward toward the bed; centers and corners rest on an exterior face. Inspect support coverage under retaining shoulders. Build-plate-only tree support works where it reaches the ledges; add support where it otherwise leaves an unsupported surface. Remove support nubs carefully from the tracks.

## Mechanism

The retaining shoulders are cut from **concentric spherical shells**, with nominal radii **28.5 and 33.5 mm**. The bearing faces directly oppose radial withdrawal. Screwed centers retain the petals; petals retain the floating corners. The shell profile transitions through a 40° internal neck to the 45° exterior cuts.

The center flange ends have **R1.2 rounding in their outline viewed radially**, extending through the flange thickness. This preserves the broad spherical bearing lands. Petal R2 radial fillets continue all the way through the exterior face, including the two tips beside each floating corner.

| Working dimension | Value |
|---|---:|
| Nominal center flange radial thickness | 4.42 mm |
| Nominal petal groove radial width | 5.28 mm |
| Gap at each center–petal spherical face | 0.43 mm |
| Total radial groove/flange clearance | 0.86 mm |
| Corner–petal bearing gap | 0.33 mm |
| Main conical body gap | 0.08 mm |
| Radial body/petal fillets | R2 mm |
| Center flange outline corners | R1.2 mm |

The petal groove has 0.20 mm more total width than the original spherical version, split equally between its two bearing walls, to accommodate supported-surface roughness. Keep body clearance separate from this track allowance. Extra clearance cannot compensate for an attached support nub.

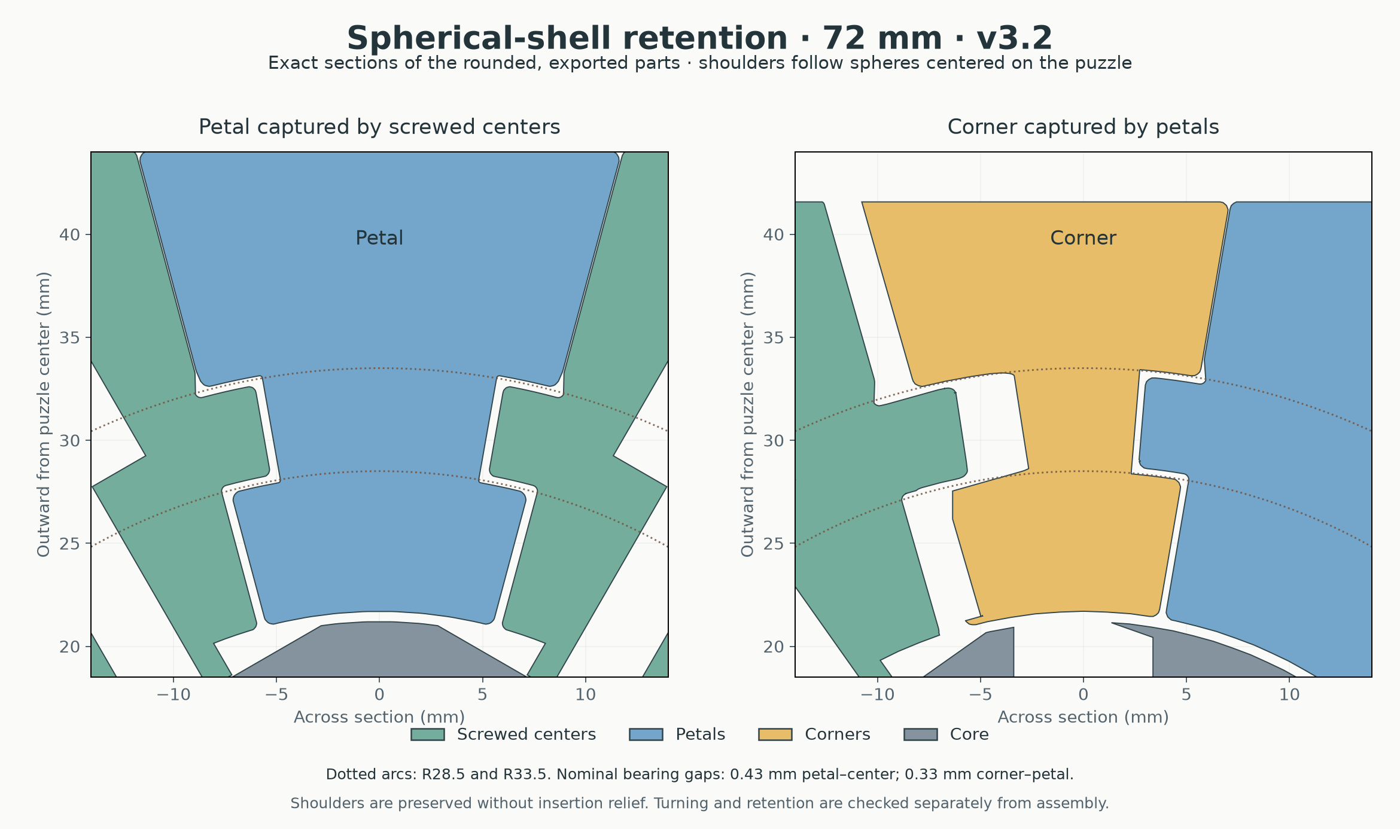
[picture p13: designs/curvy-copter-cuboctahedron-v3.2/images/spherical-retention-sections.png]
Spherical retaining shoulders


## Assembly and painting

Install the locknuts in the core first. Interlock the floating corners, petals and screwed centers around it, keeping centers absent or loose while manipulating the floating shell. Add screws and washers progressively; leave the final centers out until neighboring floating pieces are seated. Seat gently, then loosen only enough for motion. No assembly relief, split core, glue or extra hidden carriers are required by the supplied design.

The owner successfully assembled the full puzzle. A detailed reproducible insertion sequence has not been recorded or proven in CAD, so this remains a hands-on interlocking assembly rather than a prescribed straight-in sequence. Use [NEIGHBORS.md](NEIGHBORS.md), the [painting map](images/painting-map.png) and the solved reference 3MF to locate parts. Keep paint off sliding surfaces.

For an optional small retention trial, [start-here/README.md](start-here/README.md) describes a seven-piece patch using the actual puzzle pieces. The patch checks retention; it is not a complete turning puzzle. Its parts count toward the full build, so avoid printing duplicates from the full-set plates.

## Reusing earlier spherical parts

Core and floating-corner STLs are unchanged from spherical v3. Petals are unchanged from v3.1, which added the wider grooves and full-depth surface-tip rounding. v3.2 changes the screwed centers: it restores the spherical bearing rims and rounds the flange outline in the radial view. Center-only test and full replacement plates are included in `start-here/`.

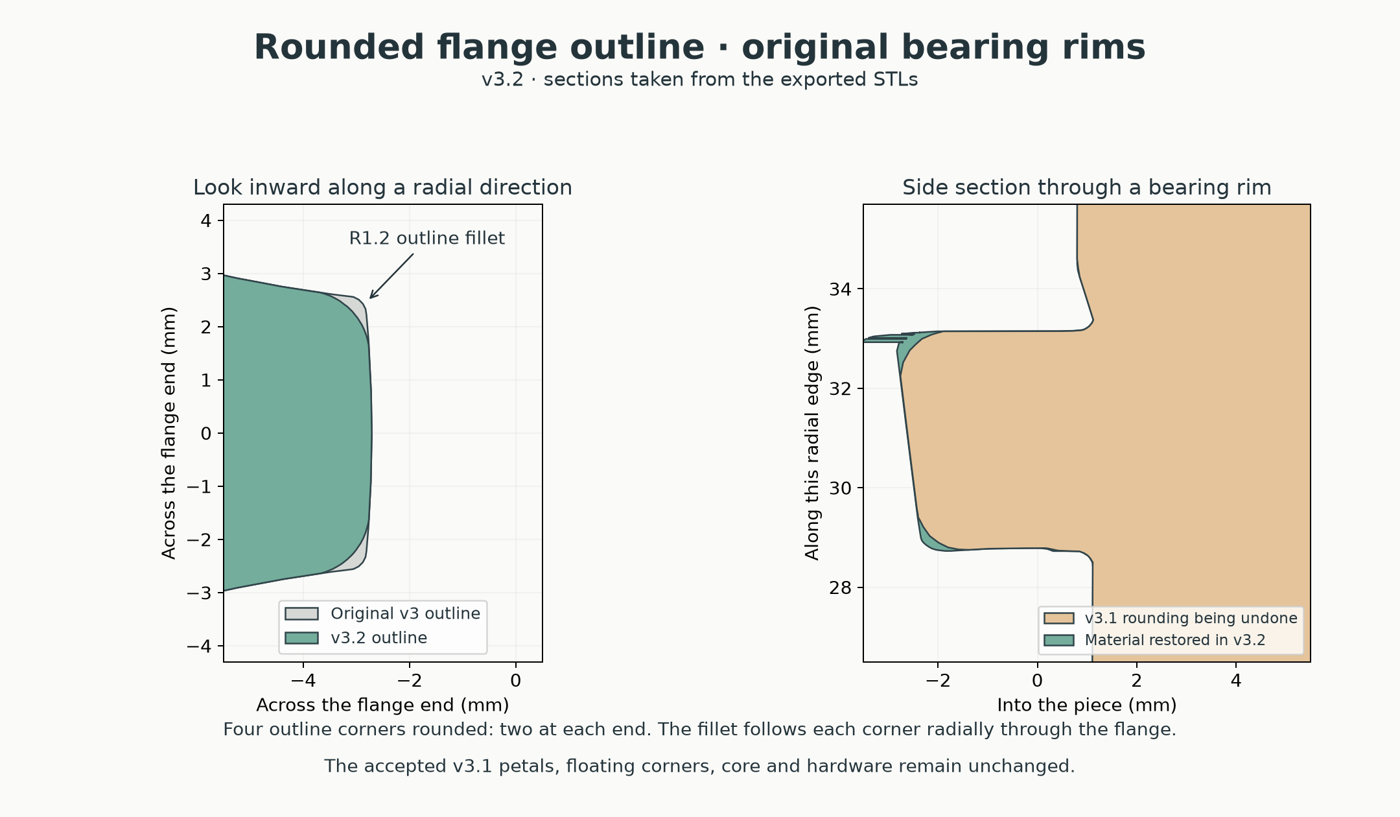
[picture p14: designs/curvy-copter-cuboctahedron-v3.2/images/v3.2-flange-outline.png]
Flange outline rounding


[Design notes](DESIGN-NOTES.md) · [Validation and physical feedback](VALIDATION.md) · [Regenerate from source](source/BUILD.md). Source, documentation and generated models are MIT licensed.

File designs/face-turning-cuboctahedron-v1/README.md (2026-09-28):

# Face-turning cuboctahedron · single cut

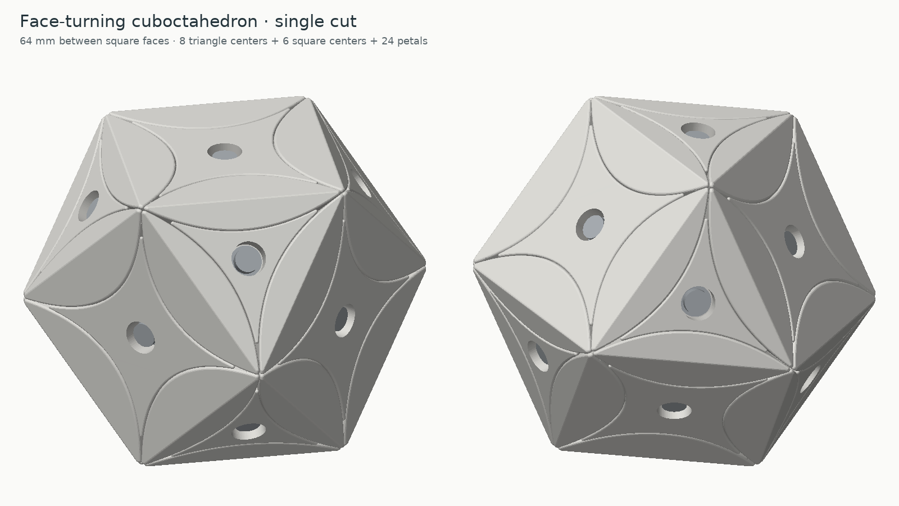
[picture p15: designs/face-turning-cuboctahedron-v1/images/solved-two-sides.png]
The supplied printable geometry


A naturally aligned face-turning cuboctahedron with **eight triangle centers, six square centers and twenty-four floating petals** around a one-piece core. Triangle faces turn 120°; square faces turn 90°. All twenty-four petals can exchange positions through ordinary turns. The exterior uses 35.264389683° triangle-axis cones and 45° square-axis cones, with the two families separately tangent.

The solved body is **64 mm between opposite square faces**, with 45.25 mm polyhedron edges and 90.51 mm between opposite vertices. This is the single-cut 38-piece surface design; it is a different mechanism from the twelve-axis vertex-turning cuboctahedron.

**Printed and assembled successfully.** The owner reports that the supplied v1 design printed and built well, but **the square faces are not very easy to turn**. See [physical feedback and supplied-file hashes](physical-feedback.json).

A possible future shape is the dual body: a **vertex-turning rhombic dodecahedron**, with a projecting vertex around each turning axis to grasp. It may offer better purchase than the flat square faces here. This is a proposed ergonomic improvement, not a designed or tested replacement; the print files in this release keep the successfully built cuboctahedron unchanged.

## What to print

| STL in `stl/puzzle/` | Copies |
| --- | ---: |
| `triangle-center-print-8.stl` | 8 |
| `square-center-print-6.stl` | 6 |
| `petal-print-24.stl` | 24 |
| `core.stl` | 1 |

That is **39 printed puzzle parts**. Each family repeats exactly; no individually shaped part files are required. The `plates/` folder contains named copies packed into geometry-only 3MF plates, plus SVG plate maps. Choose the individual STL quantities or the supplied complete plates, not both. The reference solved 3MF is for viewing only.

Use millimetres, 100% scale, PLA and your Bambu P1S 0.4 mm profile. Suggested starting settings are 0.16 mm layers, five walls and five top/bottom layers, with 25–30% infill for the moving pieces. Use six walls and 40% infill for the core. The relatively narrow triangular roots should have continuous wall paths; check them in the slicer rather than relying on infill alone.

The petal STL has its **inward radial direction pointing down**, following the orientation that worked well on your other prints. Centers rest on their flat exterior faces. The core rests on an actual bearing pad; all other intended spherical areas remain spherical. Tree supports, automatic, build plate only are a reasonable starting point. Inspect support access under the retaining feet and inside the downward-facing screw wells. A 5–6 mm brim fits the petal plate spacing.

The layer-connectivity report checks both 0.16 mm / 0.42 mm width and 0.20 mm / 0.45 mm width. It is a geometric extrusion-width model, not a saved Bambu Studio toolpath. Remove support scars and first-layer lips from the moving surfaces without sanding away the retaining shoulders.

## Hardware

- **14 × DIN912 M3×20 mm socket-head screws**.
- **14 × 7 mm outside diameter × 0.5 mm thick M3 washers**.
- **14 × DIN985 M3 nylon-insert locknuts**, nominal 5.5 mm across flats and 4 mm high.
- A 2.5 mm hex key and a blunt rod for seating the nuts.

Use the 7×0.5 mm washers for every center. The 9×1 mm washers do not fit these wells. There are no separate sleeves, inserts, magnets, springs, glued joints or hidden retaining pieces.

The default nut seat is **5.25 mm across flats**, with a **5.85 mm loading mouth**, a 3 mm taper and a final 3 mm tight section. The pocket is 4.25 mm high. This preserves the easy insertion approach and makes only the terminal section an interference fit. The default is the small increase requested after the slightly tight wavy-core fit.

Print the 5.20/5.25/5.30 mm fit coupons first if the fit is uncertain. Check a real locknut by driving a screw through the nylon ring and reversing it. Optional 5.20 and 5.30 mm cores are supplied; print one core only. Differently angled pockets can behave differently, so check all fourteen seats in the actual core before assembly.

The rotating bores are Ø3.6 mm. The washer/driver wells are Ø7.6 mm. Triangle washer seats are 32.0 mm along their axes; square seats are 27.3 mm. Screw heads remain below the exterior. At nominal geometry, triangle screws project 1.15 mm beyond the nut and square screws 5.85 mm. The different seat depths use the same screws and washers.

## Assembly

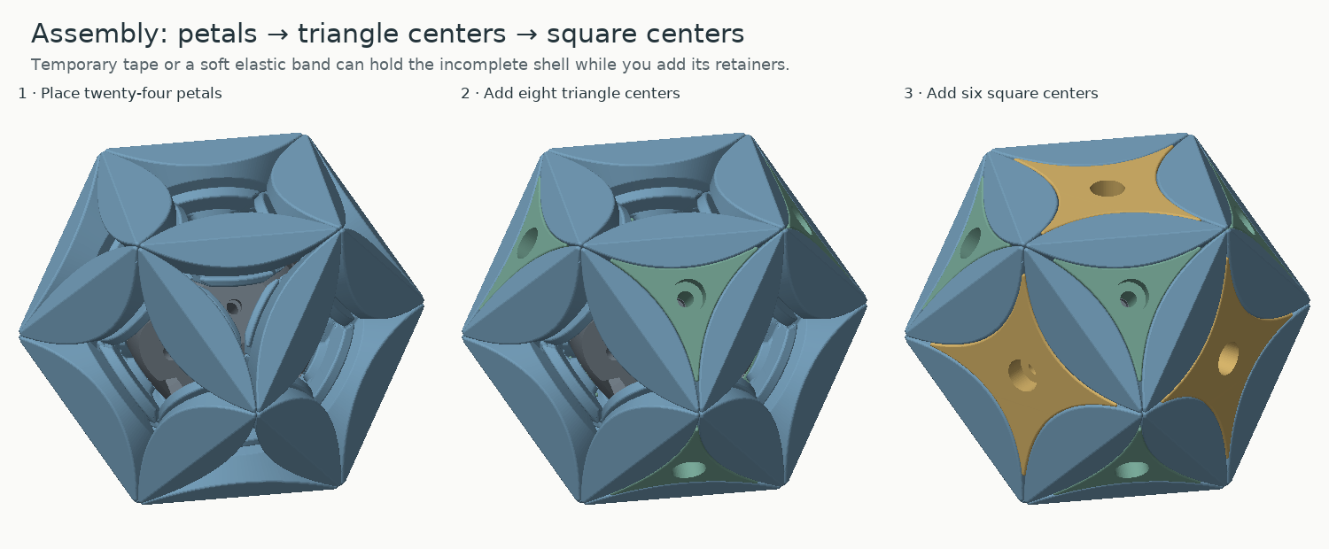
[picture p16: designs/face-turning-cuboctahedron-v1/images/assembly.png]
Assembly sequence using the actual parts


1. Press all fourteen nuts into the bare core, with the metal entry faces outward and the nylon rings inward. Check that the nuts withstand screw installation torque without spinning.
2. Optionally attach the printed assembly stand at **S01**, using one of the puzzle's screws and washers. The stand replaces this square center temporarily; it is not an extra puzzle part.
3. Place all twenty-four petals around the core. Each bridges one square exterior face and one triangular exterior face. Slide it inward along its radial direction in the solved orientation. Temporary masking tape or a soft elastic band can support the incomplete shell.
4. Add the eight triangular centers and six square centers, sliding each inward along its screw axis. These centers can be fitted in either order. Insert a washer and screw through each well, initially leaving the adjustment loose. Leave S01 until last when using the stand.
5. Support the shell, remove the stand screw and washer, withdraw the stand along its axis, and install S01 with the same hardware.
6. Adjust the centers evenly until they support the shell without binding. M3 coarse pitch is 0.5 mm per revolution: a fifth of a turn changes the screw-head position by 0.10 mm. The retention checks include 0.10 mm outward center movement. Avoid using excess looseness to compensate for support scars or misalignment.

Nylon-ring resistance at the driver is separate from bearing pressure; judge adjustment by the puzzle's movement. Do not force a center against an obstructing piece. The supplied assembly paths do not require snapping or bending a flange into place.

`NEIGHBORS.md`, the painting map and `reference/DO-NOT-PRINT-solved.3mf` show the solved relationships. All T copies are interchangeable, all S copies are interchangeable, and all P copies are interchangeable. Marking labels inside with a Sharpie can still help when comparing a partial assembly with the map.

## Painting

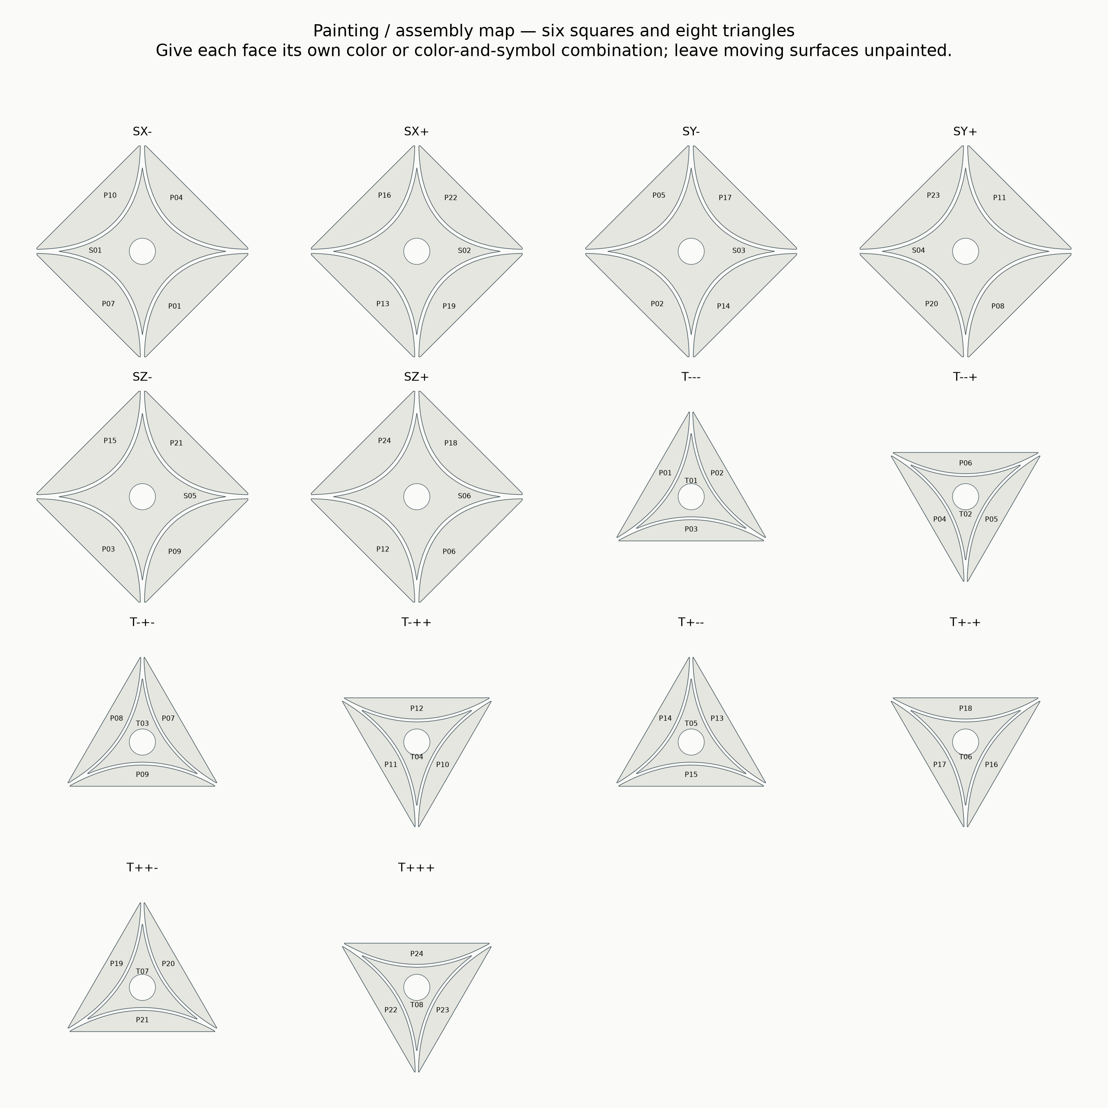
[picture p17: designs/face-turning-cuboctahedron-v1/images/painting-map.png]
Fourteen painting facets


Assemble and adjust the puzzle first, then paint the six squares and eight triangles. Use fourteen distinct colors, or distinct color-and-symbol combinations if needed. The map names every exterior face and labels the neighboring pieces.

Keep paint on the exterior flats. Leave sliding faces, retaining feet, tracks, screw bores and washer seats bare. Avoid carrying paint around an edge into a mating surface; let it dry fully before scrambling.

## Mechanism

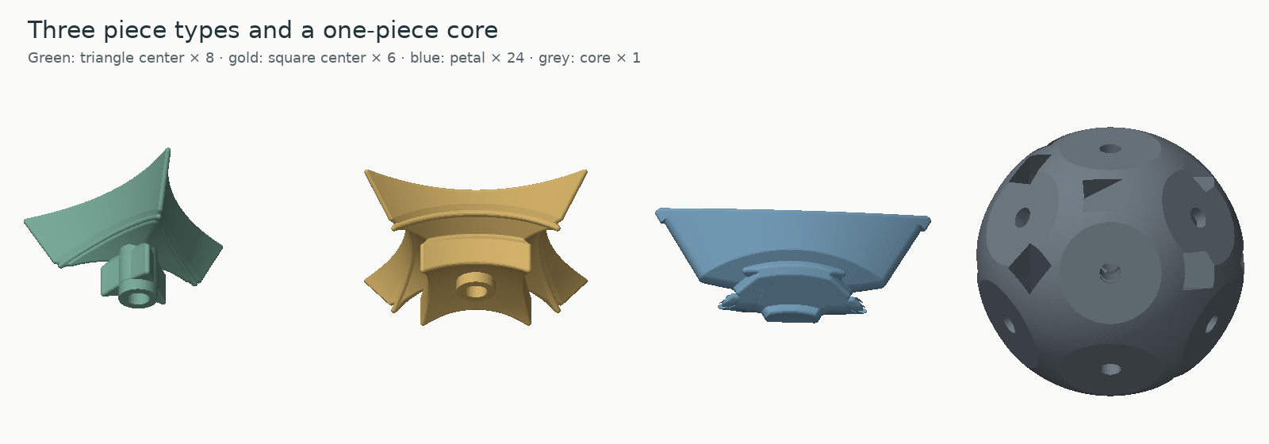
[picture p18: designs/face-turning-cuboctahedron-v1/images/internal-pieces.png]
Centers, petal and core


The core anchors fourteen adjustable centers. Each petal is retained beneath its two neighboring centers by stepped rotational profiles. Assembly relief makes the centers insertable after the petals. The shoulders are sized and checked after rounding and relief, including intermediate turns with slightly lifted centers.

Each triangular center has an integral continuous stem around its screw bore, with a nominal 1.3 mm minimum wall. The petal has clearance for the full rotational sweep of that stem about a square axis, so the reinforcement clears intermediate turns as well as the aligned positions. This clearance is cut before edge rounding. The washer-seat root and the entire deeper bore wall are checked separately.

The two internal profiles are different because the triangle and square axes have different cone angles. They provide wider shoulders below the outer shell, then return to the chosen exterior cones below the nearest outer face. This preserves the surface pattern while giving the feet useful material. These internal shoulders need not remain inside the exterior cone's angular envelope; normal-turn clearance follows their own rotational sweep and is checked on the exported meshes.

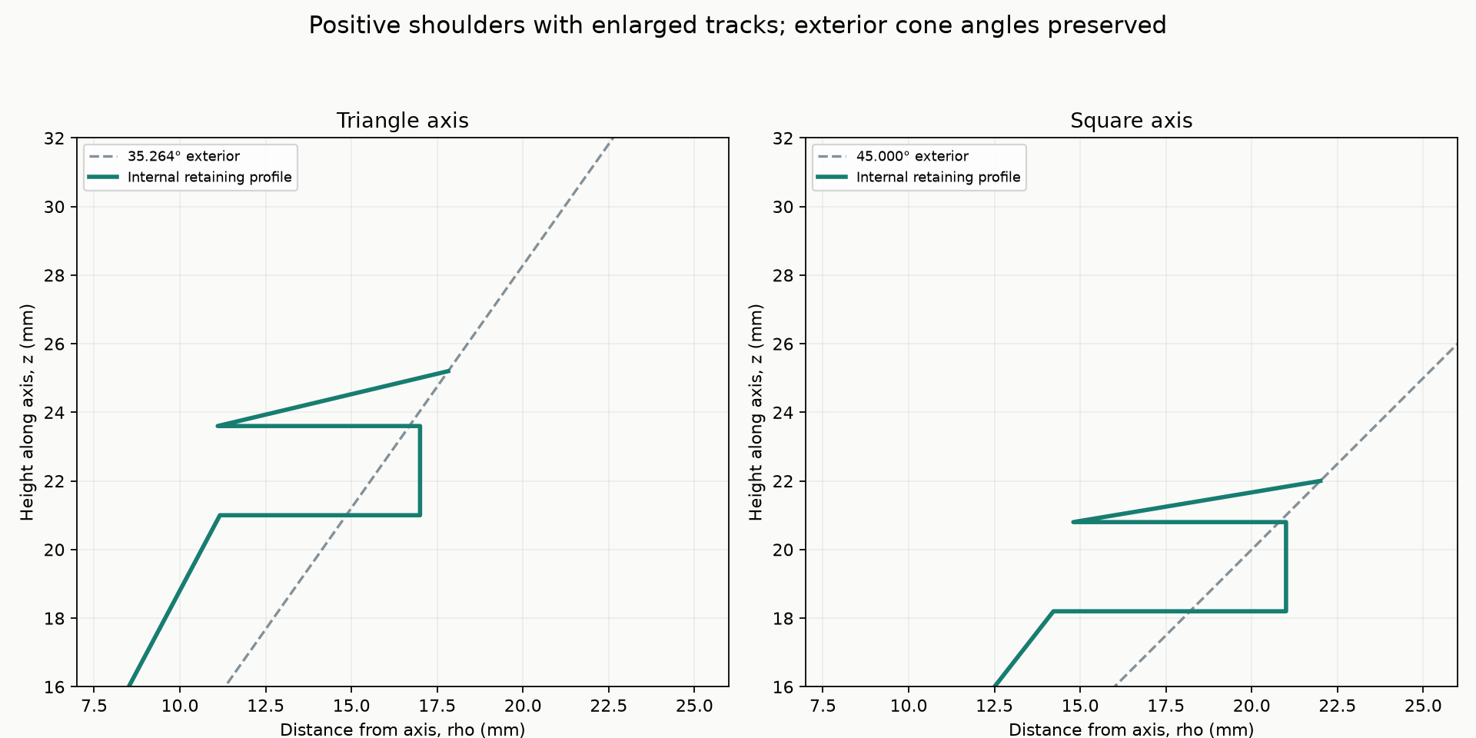
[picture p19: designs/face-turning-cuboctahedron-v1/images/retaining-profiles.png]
The two retaining profiles


| Feature | Dimension |
| --- | ---: |
| Main conical-face gap, total | 0.06 mm |
| Additional track-cutter expansion | 0.40 mm |
| Long petal radial ridges, including tracks | R2 |
| Other edge opening: petals / centers | R0.55 / R0.45 |
| Core sphere / moving inner cavity | R21.2 / R21.7 mm |
| Core bearing pad / foot plane | 19.6 / 19.7 mm along axis |
| Bearing foot / rotating bore | Ø6.2 / Ø3.6 mm |
| Nut roof thickness | 1.95 mm |

Track clearance is computed from the unrounded profile separately from the printed part's softening. R2 radial fillets continue through the tracks. Disconnected, nonfunctional tip remnants produced by rounding are removed and logged; the layer checks use the final supplied parts.

## Validation and limits

See `reports/` for the numerical results. Checks reload the actual STL exports and cover closed single-component meshes, assembly, all fourteen turn axes with hardware present, intermediate petal retention, tilted extraction probes, ordinary-turn destination fit, nut loading, hardware-to-hardware clearance, washer-root webs, the removable stand, and fixed-linewidth layer connectivity.

These are finite rigid-geometry checks. They do not measure friction, PLA flex, holding force, fatigue or every possible escape trajectory. Actual print finish and screw tension remain important. Ordinary turns are 120° about triangle axes and 90° about square axes.

The source and generated design are MIT licensed. Regeneration instructions are in `source/BUILD.md`; dimensions and print transforms are recorded in `reference/design-parameters.json` and `manifest.json`.

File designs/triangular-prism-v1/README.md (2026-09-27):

# Wonky triangular prism · 70° · 64 mm

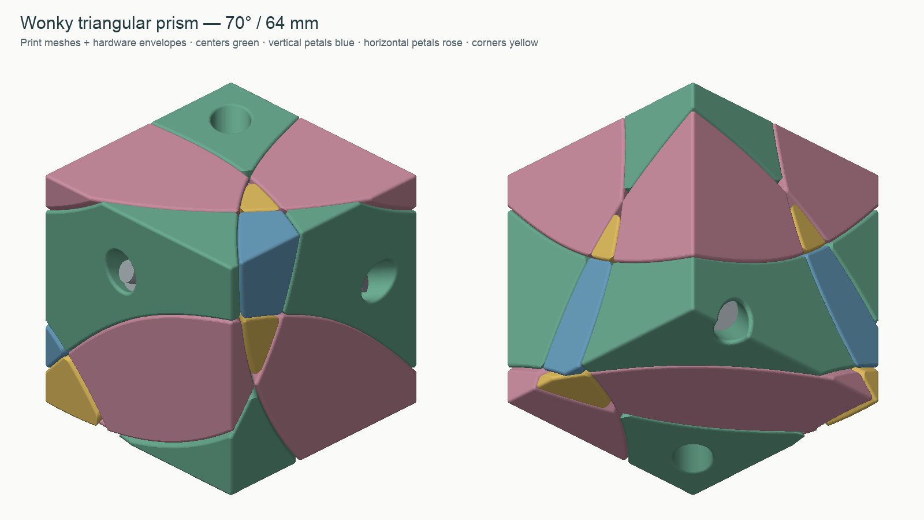
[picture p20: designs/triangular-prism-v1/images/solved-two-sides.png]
Both sides of the delivered meshes


A non-wavy, face-turning triangular-prism puzzle inside a rotated 64 mm cube. C01–C03 are the three equatorial axes: each turns 180°. C04 and C05 are the opposing poles: each turns 120°. The solved shape, including center orientation, replaces stickers.

This is a complete new puzzle. Its parts do not fit the 48 mm wavy version. It uses the successful 64 mm pentagonal prism's retention and hardware layout, adapted to five axes. The cone half-angle is 70°: triangular-prism corners first appear at about 63.435°, so copying the pentagonal prism's 60° angle would not produce this set of pieces. These are straight conical generating profiles; their intersections with flat cube faces are curved.

## Print

Print one of every STL in `stl/puzzle/`: **5 screwed centers, 3 vertical petals, 6 horizontal petals, 6 floating corners, and 1 core — 21 parts total.** The main plates are `centers-corners-core-01.3mf` and `petals-01.3mf` in `plates/`. Their objects retain the part IDs. They are geometry-only 3MFs: apply your printer and support settings. Alternate orientations, optional cores, fit coupons and the assembly stand are additional choices, not more required puzzle pieces.

For the P1S / 0.4 mm nozzle, use PLA at 100% scale, millimetres. Start with 0.16 mm layers, four walls, five top/bottom layers and 25–30% gyroid infill. Use six walls and 40% gyroid on the core, matching the successful pentagonal print. Automatic tree support on the build plate only is a suitable starting point; inspect the actual Bambu slice around every foot and retaining shoulder. Remove support and seam burrs carefully without sanding away the flat retaining lands. A brim up to 8 mm fits the supplied plate spacing. Parts with a small first-layer footprint need one.

V/H petals are oriented with their inward radial direction down, following the established print preference. Centers and corners use a broad exterior face down. The core rests on a real axle pad. `print-options/` contains individual alternative orientations if desired. `reference/DO-NOT-PRINT-solved.3mf` is an assembly reference only.

## Hardware

- **5 × DIN912 M3×20** socket-head screws, nominal head Ø5.5 × 3 mm.
- **5 × Ø9 × 1 mm washers**, with M3 clearance holes. Use the familiar 9 mm washers for this build; the stack is not set for the 7 × 0.5 mm washers.
- **5 × DIN985 M3 nuts**, nominal 5.5 mm across flats and 4 mm tall.
- A 2.5 mm hex key, blunt metal rod for seating nuts, and a marker for part IDs.

The core uses the well-tuned pentagonal pocket: 5.20 mm terminal width across flats, 5.85 mm entrance, 3 mm tight loading region and 3 mm taper, with 4.25 mm pocket height. Try `stl/fit-coupons/nut-fit-5.20.stl` with your actual nut first. If necessary, test 5.30 / 5.40 and choose the corresponding optional core; print only one core. Print angle and nut variation can affect this interference fit. Seat nuts fully, with their nylon rings toward the puzzle center, before assembly.

The screw bore is Ø3.6 mm and the washer well Ø9.6 mm. The spherical core radius is 21.2 mm; flat pads are at 19.6 mm and bearing feet at 19.7 mm. Washer seats are at 30.1 mm, 1.2 mm inward from the pentagonal version to contain the C03 screw head. With a 1 mm washer, the nominal M3×20 screw ends at 11.1 mm, 2.55 mm beyond the nut's inward face. No magnets, glue, hidden loose retainers, core tracks or split core are required.

## Assemble

Mark IDs inside every piece. Use `NEIGHBORS.md`, `images/assembly-map.png`, and the inside-facing `catalog-*.png` images to identify them. The render colors distinguish piece families; they are not required filament colors.

1. Clean supports and seat all five nuts in the core.
2. Optionally use `stl/optional/assembly-stand.stl` in place of C01, held with one of the five screws and washers. It holds the core while assembling; no extra permanent hardware is needed.
3. Place K01–K06 against the core in their solved positions. Hold this incomplete shell with your fingers or temporary tape.
4. Place V01–V03 and H01–H06 between them. Their internal shoulders overlap the corners' feet. The checked insertion path is straight inward along each part's radial direction, with the other petals already in their solved positions.
5. Insert C02–C05 and start their screws into the nuts. Keep the shell aligned and leave a little freedom while closing it.
6. Support the shell, withdraw the optional stand along C01's axis, and replace it with C01, reusing its screw and washer. Without a stand, install C01 last.
7. Adjust all five screws gradually and evenly. M3 coarse pitch is 0.5 mm/revolution: one fifth of a turn changes the setting by 0.10 mm. Aim for free movement with minimal play; the nylon nut's turning resistance is not a measure of bearing preload. Check full 180° side and 120° pole turns from correctly aligned positions.

No part needs to snap past a finished retaining lip. Assembly checks include the core, neighboring installed pieces, hardware, stand and its withdrawal. They establish sampled collision-free paths, not that an unfinished shell stands up unaided.

## Retention and fit

The previous small wavy triangle assembled, but its floating corners popped, including after enlargement. A blocked single rigid pull in CAD did not predict that physical behavior. This design therefore replaces that mechanism rather than scaling its STLs.

The internal cut uses a **closed stepped shoulder and neck**, following the pentagonal construction. Its flat land runs outward from transverse radius 7.2·tan(70°) = 19.78 mm to 26.5 mm at axial height 7.2 mm. The cylindrical wall rises to 9.0 mm, then returns to the cone at 9·tan(70°) = 24.73 mm. That gives 1.77 mm nominal undercut projection before clearances and rounding. The shoulder is enclosed within radius 28 mm, inside the 32 mm cube insphere. Screwed centers capture petals; petals capture corners.

Main conical faces use 0.03 mm total nominal separation. Hidden track cutters have an additional 0.40 mm expansion, tapering back to the body gap toward the exterior. Printed flanges and cutter clearances are separate. Internal convex edges use 0.60 mm easing on floating pieces / 0.45 mm on centers; radial dihedral ridges use R2 transverse circular fillets through the track region; exterior edges use 0.8 mm easing. Washer lands and flat bearing pads remain flat. Nearly no material is removed for the sampled assembly path; the useful shoulders are preserved.

The corners' three tiny terminal regions are explicitly trimmed after rounding, removing about 11.57 mm³ per corner. This eliminates thin webs that could otherwise slice into separate scraps. The broad retaining lobes remain, and capture is checked on the trimmed exports. The trim stays inside a 31 mm sphere and does not alter the visible cube surface; exact clipping planes are in `finish_conical.py` and `reports/terminal-trimming.json`.

On **2026-09-27**, the owner reported that this **64 mm non-wavy triangular prism printed, assembled and turns well**. The [physical feedback record](physical-feedback.json) identifies the associated supplied STL files. Exact slicer settings and the chosen optional core were not restated; no endurance or holding-force measurement was reported. CAD motion and capture checks are separate evidence; `VALIDATION.md` states their coverage and limits.

## Contents

`manifest.json` records hashes and print-to-mechanism transforms. `images/` shows the actual delivered meshes. `reports/` contains measurements tied to the manifest hash. `source/BUILD.md` describes regeneration. Source and generated design files are MIT licensed.

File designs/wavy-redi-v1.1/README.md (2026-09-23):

# Wavy Redi · 64 mm · v1.1

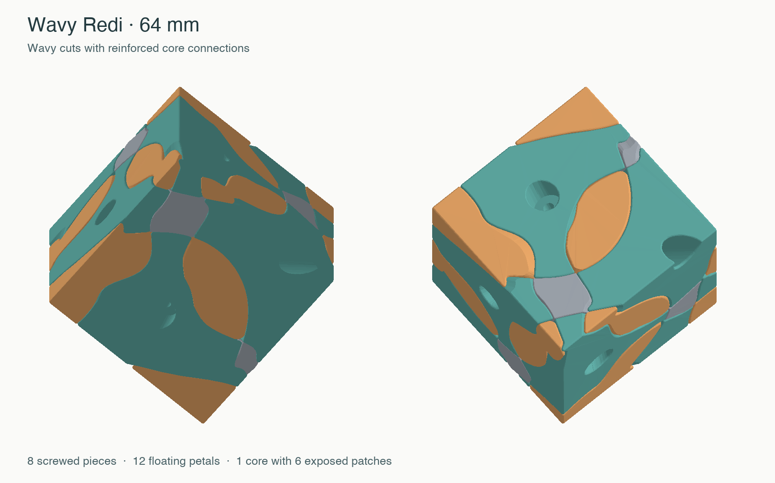
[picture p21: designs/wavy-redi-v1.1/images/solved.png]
Solved views


A Redi-equivalent shape puzzle with eight screwed axial pieces, twelve
floating petals and one stationary core. Six patches of the core appear on
the outside. Each move turns one axial piece and its three neighboring
petals through 120 degrees. There are 21 printed puzzle parts.

This is the printable interpretation of selection **wavy-90d18b40**.
The exact original selection is retained in `source/selection.json`.
The internal fold is replaced by an axially open retaining profile. The
user-approved strengthening widens the six core connections; a fine
surface-grid comparison found a maximum nearby seam shift of 0.92 mm.
The selected wave resumes unchanged outside that small region, apart from
manufacturing gaps and edge rounding. The solved cube remains 64 mm.

**Read [ASSEMBLY.md](ASSEMBLY.md) before printing.** These pieces assemble
in groups; the ordinary Redi's “all petals, then all screwed pieces” order
does not work with this exterior wave.

## Printed result and small refinements

The owner reports that **v1 built very well and turns great**. Its nut seats
were just slightly too tight, and four outside petal tips were unintentionally
clipped. The [physical feedback record](physical-feedback.json) identifies
the supplied v1 files; exact slicer settings for that print were not recorded.

This v1.1 revision widens only the nut seat from **5.20 to 5.25 mm across
flats** and restores the cube-corner tips of **E02, E04, E09 and E11**. The
entrance remains 5.85 mm, and the functional tracks, clearances and R2
rounding are unchanged. The restored tips retain gentle R0.65 exterior
rounding. Only the **core and those four petals** need replacing; the other
sixteen moving-piece STLs are preserved byte for byte in the published
release. Regenerated meshes may differ. The refinements pass the included
CAD checks but have not yet been physically printed.

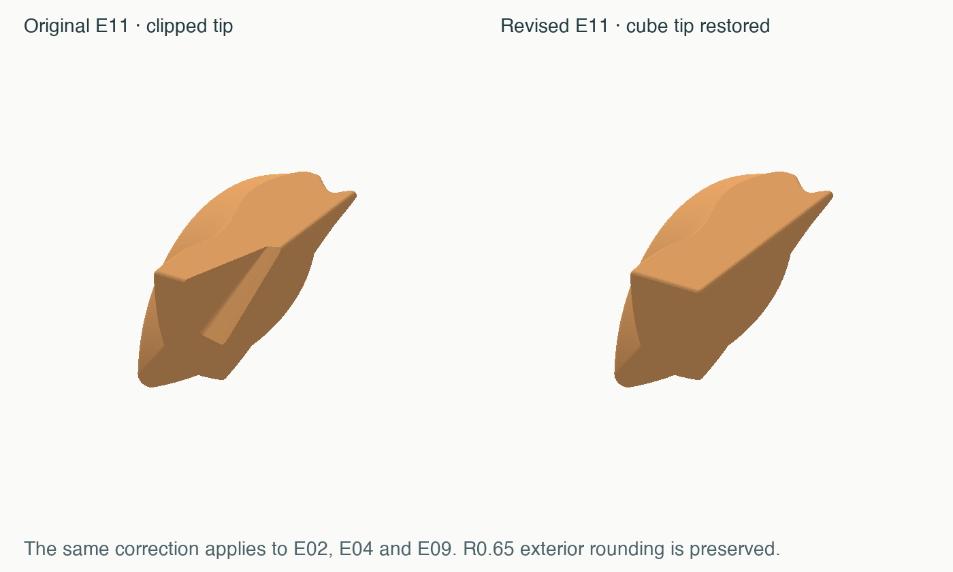
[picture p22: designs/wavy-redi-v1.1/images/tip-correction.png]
E11 tip correction


## Files

- `stl/puzzle/`: print each of the 21 files once. Orientations are already set.
- `plates/core-and-axles-01.3mf`: core and eight axial pieces, if packed on one plate.
- `plates/petals-01.3mf`: twelve petals. See `plate-maps.html` for the actual plate inventory.
- `stl/fit-coupons/nut-fit-5.25.stl`: optional check of the slightly relaxed nut fit.
- `reference/DO-NOT-PRINT-assembled-cube.3mf`: assembled reference in cube coordinates.
- `source/`: parameterized CAD, exporter, render and validation scripts.
- `reports/`: checks on the exported/reloaded STLs; read `VALIDATION.md`.

The 3MF plates contain geometry and placement, not a configured printer job.
They do not select a printer, material or support profile.

## Hardware

Eight each of DIN912 M3 × 20 screws, 9 mm OD × 1 mm washers and DIN985 M3
nyloc nuts. The Ø9.6 mm access wells accommodate the washer and socket head;
use a 2.5 mm hex driver. The rotating bores are Ø3.6 mm. Screw tips extend
3.35 mm beyond the nominal nuts in the modeled stack. No glue, magnets,
additional hidden pieces or core joining screw are needed.

Nut channels start at 5.85 mm across and taper into a 5.25 mm terminal seat.
A nominal 5.5 mm nut deliberately has 0.125 mm interference per side in the
final seat. The 0.05 mm total increase responds to the slightly tight fit
of v1; print the coupon first when changing hardware or print settings.
Insert the nylon end toward the middle of the core. Support the central
hub while pressing; do not use an exposed core arm as a lever.

## Printing on a P1S, PLA, 0.4 mm nozzle

Start with 0.16 mm layers, 4 walls, 5 top/bottom layers and 25% gyroid for
the moving pieces. Use 6 walls and 40% gyroid for the core. The narrow roots
then fill with perimeters. Use automatic tree supports, build plate only,
and inspect the preview around the inner shoulders and overhanging lobes.
The pentagonal-prism build used a 30° support threshold and 0.20 mm top
contact gap; these are a starting point, not settings confirmed for the
wavy print or a sliced preset in this package.

Petals are oriented with their inward direction pointing down, as requested
for the earlier puzzles. A 0.24 mm trim of each hidden inner tip creates a
small bed flat without changing the exterior. The axial pieces and core sit on their largest
available exterior flat. Keep those orientations. Add a brim where the
initial petal footprint is small. Remove supports carefully from the tracks
and core branches. The fixed arms are substantially stronger than the
literal selected geometry, and the original wavy print assembled and turned well.

Mark **C01–C08** and **E01–E12** inside the pieces before mixing them up.
The recessed dot count on each core bearing pad identifies its C number.

## Mechanism choices

- An unbroken central hub carries all eight screw bearings. Six integral
  arms connect its exposed patches; they are not separate floating centers.
- Each petal is captured by two neighboring axial pieces. The shoulders
  open along an axis, permitting group insertion, but oppose an individual
  petal's outward motion. Rounded lead-ins ease realignment.
- Main-body separation is 0.08 mm total. Inner tracks receive an additional
  0.40 mm cutter expansion. Track relief is generated from the unrounded
  profile; rounding the printed foot does not narrow the channel.
- R2 mm circular rounding follows the actual curved dihedral edges over
  their full length, including the inner track region. Inner foot/body
  lead-ins are approximately R0.5/R0.4; exposed moving-piece rims are R0.65.
- The washer bears on a flat annular seat at 27.3 mm. A separate flat foot
  sits 0.10 mm above the core pad in the nominal CAD position. Adjust screw
  tension gently after assembly; 72° of an M3 screw is 0.10 mm of travel.

The CAD checks establish the documented geometric behavior at the sampled
positions and the constructive loading sequence. They are not a strength,
wear or friction certification. Physical feedback supports the original
v1 mechanism; it does not yet validate the revised v1.1 fit.

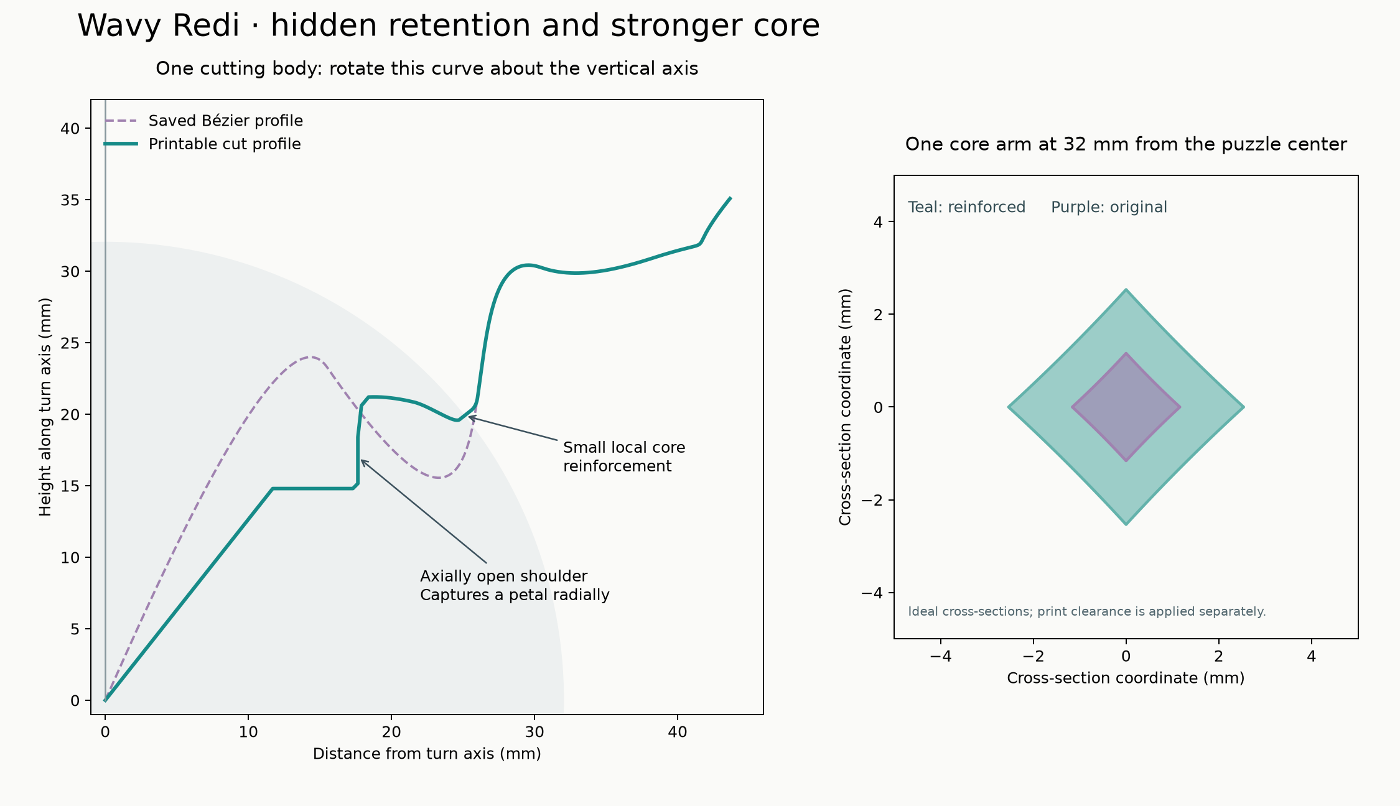
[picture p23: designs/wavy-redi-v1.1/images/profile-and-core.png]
Profile and core


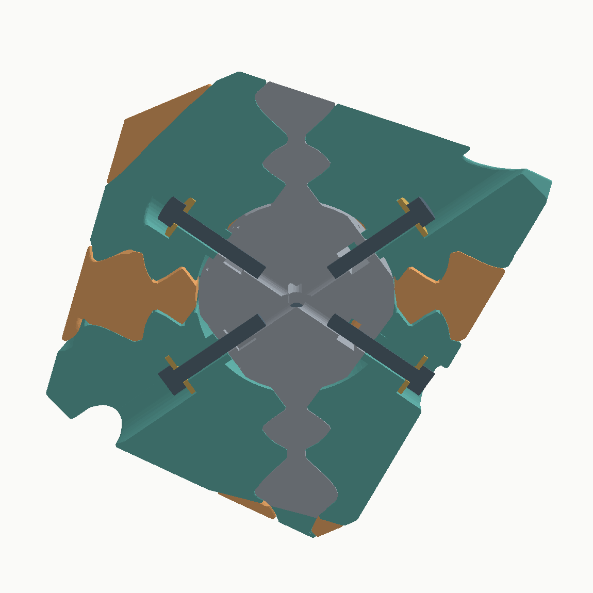
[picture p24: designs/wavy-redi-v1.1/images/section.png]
Internal section


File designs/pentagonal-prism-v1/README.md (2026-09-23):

# Wonky pentagonal prism · 60° · 64 mm

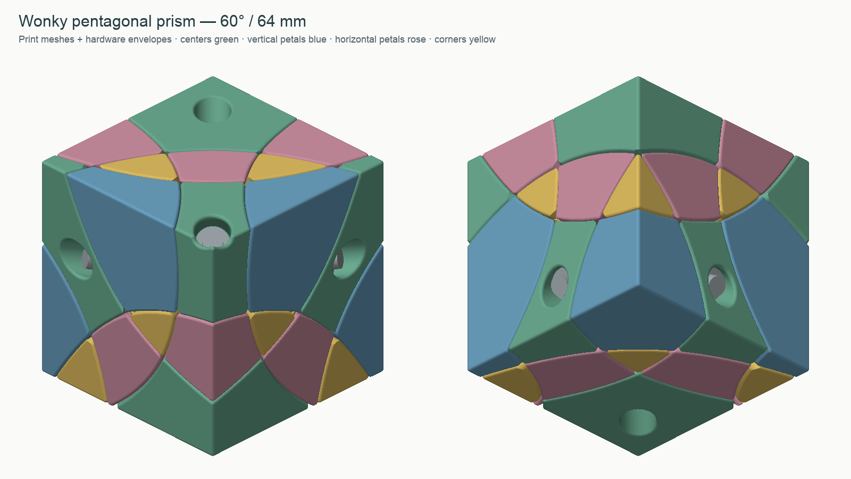
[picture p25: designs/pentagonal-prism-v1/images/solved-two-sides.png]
Opposite views


A face-turning pentagonal-prism equivalent with conical cuts, presented as an uncolored cube shape mod. Five equatorial axes turn **180°**; the two polar axes turn **72°**. Solve the shape, including center orientation. C01–C05 run in cyclic order around the equator; C06 and C07 are the opposite poles.

The exterior is oriented so **C05, C06 and C07 lie in the cube plane x+y=0**, a diagonal mirror plane. This is a 5.67233332° adjustment from the shared starting cube orientation. The cone half-angle remains 60°. The complete rotation matrix is in `source/chosen_rotation.json`.

On **2026-09-23**, the owner reported that this puzzle **built together very well** and that the **nut-slot sizing is well tuned**. The printed core used the default **5.20 mm terminal seat**. The [physical feedback record](physical-feedback.json) includes the supplied part hashes and the Bambu P1S/PLA settings used. Turning smoothness and long-term wear were not separately assessed in that report.

## What to print

Print **one of every file in `stl/puzzle/`**: 7 screwed centers C01–C07, 5 vertical petals V01–V05, 10 horizontal petals H01–H10, 10 floating corners K01–K10, and one core. Total: **33 puzzle parts**. “Vertical/horizontal” refers to the prism's axes, not the rotated cube or print bed.

Use the named geometry-only 3MF plates in `plates/`, or import the individual STLs at **100% scale, millimetres**. The plates contain no printer presets. The solved assembly in `reference/DO-NOT-PRINT-solved.3mf` is an identification reference, not a print plate. Alternative orientations and alternate cores are duplicates: do not print them as extra puzzle parts.

For the Bambu P1S, start with the familiar PLA, 0.4 mm nozzle and 0.16 mm layers, 4 walls, 5 top/bottom layers and about 25–30% gyroid infill. Use more walls or high infill for the core and the optional stand. V and H STLs have their inward radial direction pointing straight down. C and K use a large exterior flat face down; optional orientations are supplied. Inspect the actual Bambu preview for each part: enable build-plate supports where the feet and undercuts need them, then remove supports and seam burrs completely from the sliding surfaces. Use a brim for small first-layer footprints if needed. Do not resize the models or globally offset every surface to adjust fit.

## Recorded successful build

All **33 puzzle parts fit on one P1S plate**, with blue PLA for the core, screwed centers and floating corners, and yellow PLA for both petal families. The default 5.20 mm nut-seat core was printed. Parts retained their supplied orientations; packing used only translations and rotations about the bed's vertical axis.

The job used a **0.4 mm nozzle, 0.16 mm layers, 4 walls, 5 top/bottom layers and 25% gyroid infill**. The core used **6 walls and 40% gyroid**. Supports were **automatic tree, default style, build plate only**, with a 30° threshold and 0.20 mm top gap. The textured PEI plate and automatic bed leveling were used. Bambu estimated 16 h 22 min and 320.33 g including supports, flushing and the prime tower; these are slicer estimates, not measured totals.

These settings record one successful build. Use the nut coupons when changing material, printer calibration or hardware. The geometry-only plates below remain independent of a particular printer profile.

## Hardware and nut fit

- **7 × DIN912 M3×20 socket-head machine screws**; nominal head envelope Ø5.5 × 3 mm.
- **7 × washers Ø9 × 1 mm**, with an M3 clearance hole.
- **7 × DIN985 M3 locknuts**, nominal 5.5 mm across flats and 4 mm high.
- A 2.5 mm hex key, and a blunt metal rod to seat the nuts.

The default core has **5.20 mm terminal nut seats**, with a **5.85 mm loading entrance** and a tapered transition. The tight loading-channel region extends 3.0 mm from the bore center, followed by a 3.0 mm taper to the entrance; the slot is 4.25 mm high. This default fit was reported well tuned in the assembled PLA build. Print the small `nut-fit-5.20` coupon first and test your real nut. If insertion requires excessive force or splits the coupon, test 5.30 and then 5.40; the matching alternate cores are in `stl/optional/`. Choose the tightest coupon that seats fully without damage and prevents the nut rotating. These intentionally undersized seats depend on printer calibration and nut dimensions. The coupon includes the same slot and roof geometry as the core. `rotor-fit` tests the washer well and screw passage.

Push each nut sideways to the center of its slot, **nylon ring toward the puzzle center**. Screws then enter through the metal-threaded face first and engage the nylon before reaching their tips. Keep glue out of the threads and bearings; the design does not require glue.

The Ø3.6 screw passage clears the shaft; the Ø9.6 well clears the washer. Flat bearing feet at radius 19.70 mm run over flat core pads at 19.60 mm. Washer seats are at 31.30 mm. A fully seated nominal screw extends 1.35 mm beyond a nominal nut. The core sphere is Ø42.4 mm, sized to support the screw stack. The overall cube stays 64 mm.

## Assembly

Use `images/assembly-map.png`, the inside-facing catalogs, and `NEIGHBORS.md`. Mark IDs inside with a fine permanent marker before mixing loose parts. The face map shows the flat surface areas; its white bands include the rounded edges. The colors in the drawings identify families only; colored filament is not required.

1. Test the nut fit and remove supports/burrs. Press all seven nuts fully into the core before adding the outer pieces.
2. Optionally mount the core on `assembly-stand` at C01, using one of the seven screws and washers. The stand temporarily replaces C01 and is reusable. It needs no extra permanent hardware.
3. Place the ten K corners against the core in their solved positions. Use gentle temporary tape or support from your fingers to hold this incomplete shell; it is not captive yet.
4. Insert the five V petals and ten H petals between them. Their shoulders overlap the K feet. V and H pieces can be inserted after the corners; the provided assembly tests include the other petals already in place. Keep the shell aligned as you close it.
5. Add and screw down C02–C07. Their shoulders retain the petals. Start every screw gently in its nut, and leave slight axial freedom while aligning the shell.
6. Support the puzzle, remove the stand and its screw/washer, then insert C01 and install that same screw/washer. Without the stand, install C01 last after the other centers.
7. Adjust all seven screws in small equal increments. A standard M3 coarse thread advances 0.5 mm per revolution: one fifth turn changes the axial setting by 0.10 mm. Aim for free turns with little play, not maximum screw torque. The nylon nuts resist screw rotation but do not replace careful adjustment. Begin with correctly aligned, slow full 180° side turns and 72° pole turns.

Assembly checks test radial insertion with already installed parts, the core, neighboring hardware and the optional stand. They establish a collision-free sampled route, not a claim that a partly assembled shell supports itself without your hands.

## Mechanism

Each cone cut becomes a stepped surface of revolution inside the cube. A flat shoulder provides positive capture: the screwed centers hold the petals, and the petals hold the corners. The shoulder is at transverse radius 26.5 mm, with local axial levels 12.6 and 14.4 mm; it rejoins the 60° cone at radius 14.4·tan(60°) ≈ 24.94 mm. The nominal shoulder overhang is therefore about 1.56 mm before clearances and rounding. It remains inside the cube's 32 mm insphere. There is no core-track retention layer.

The main conical body gap is **0.03 mm total**. Track cutters are expanded by **0.40 mm** in the mechanism, tapering back to the body gap outside it. Printed lips have their own rounding; tracks are not derived from the already rounded feet. Small convex internal edges use 0.60 mm rounding on floating parts and 0.45 mm on centers. Long radial ridges use a **2 mm transverse circle radius through the track region**, and exposed outer edges use **0.8 mm** rounding. The flat bearing interface has 0.10 mm initial axial clearance. These dimensions distinguish running clearance from retention overlap.

Only the interference volume needed by the specified insertion route is removed for assembly. Radial fillet fitting starts outside the hollow core and extends inward, so it follows the actual dihedral instead of mistakenly rounding the spherical cavity wall. The washer landing is protected during exterior rounding to keep it flat. The final CAD checks cover collisions, retention probes, hardware access, washer lands, nut loading, stalk continuity, watertight exports and fixed-linewidth layer connectivity. Read `VALIDATION.md` for exact coverage and limitations.

## Files and regeneration

- `images/`: actual mesh renders, six-face assembly map and inside-facing catalogs.
- `NEIGHBORS.md`: neighbors and parent turn axes for every exterior piece.
- `reports/`: numerical checks tied to the delivery manifest hash.
- `source/`: Python CAD, mesh export, rendering and validation scripts.
- `manifest.json`: quantities, hashes, dimensions and explicit assembly/print transforms.

See `source/BUILD.md` for regeneration. Source and generated design files are provided under the included MIT license.

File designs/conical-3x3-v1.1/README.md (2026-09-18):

# Wonky conical 3×3 — 70°, 64 mm, v1.1

A complete printable design using six face-direction axes and the saved exterior
rotation of the successful 64 mm Wonky Redi and Skewb. Its 70° conical cuts give
six screwed centers, twelve edges and eight floating corners. The intended moves
are 90° face turns. The surface outline is the selected 70° gallery shape, with
working gaps and rounded edges added.

**Owner-printed:** the owner reported that the reinforced v1.1 printed very well. These STL hashes match the supplied set associated with that report.
See [the physical feedback record](physical-feedback.json) for the report and
its scope. Exact slicer settings were not restated; strength and endurance
have not been measured.

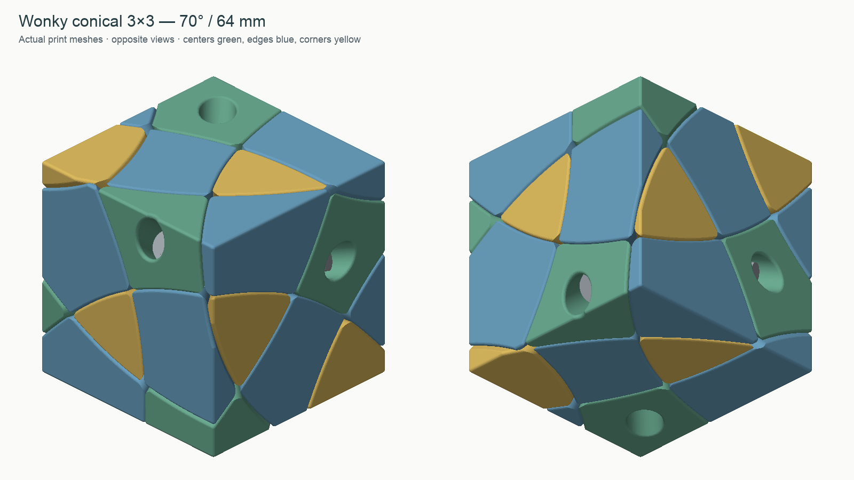
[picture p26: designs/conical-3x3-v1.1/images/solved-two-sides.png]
Delivered geometry


## Revision 1.1 — reinforced screwed centers

A slicer review exposed a thin connection between each center's stalk and body.
The original mesh was connected, but the shortest measured web between the wide
washer well and the outside root was only about **0.65 mm**. Connectivity and
collision checks did not establish sufficient strength at that junction.

The washer seat is now **1.5 mm farther outward**, shortening the wide well and
increasing that local web to about **2.04 mm**. The Ø3.6 mm through passage,
bearing foot, exterior and retaining surfaces keep their working dimensions.
The M3 × 20 screw still passes through the entire locknut, projecting about
**1.85 mm** beyond it. The head remains inside the solved cube.

Only the six **C01–C06** puzzle STLs change. The **core, twelve E edges and eight
K corners are byte-for-byte identical to v1** in this compatible release.
Keep any of those already printed. The optional rotor-fit coupon and reference
assembly are also updated; the assembly stand and nut coupons remain unchanged.

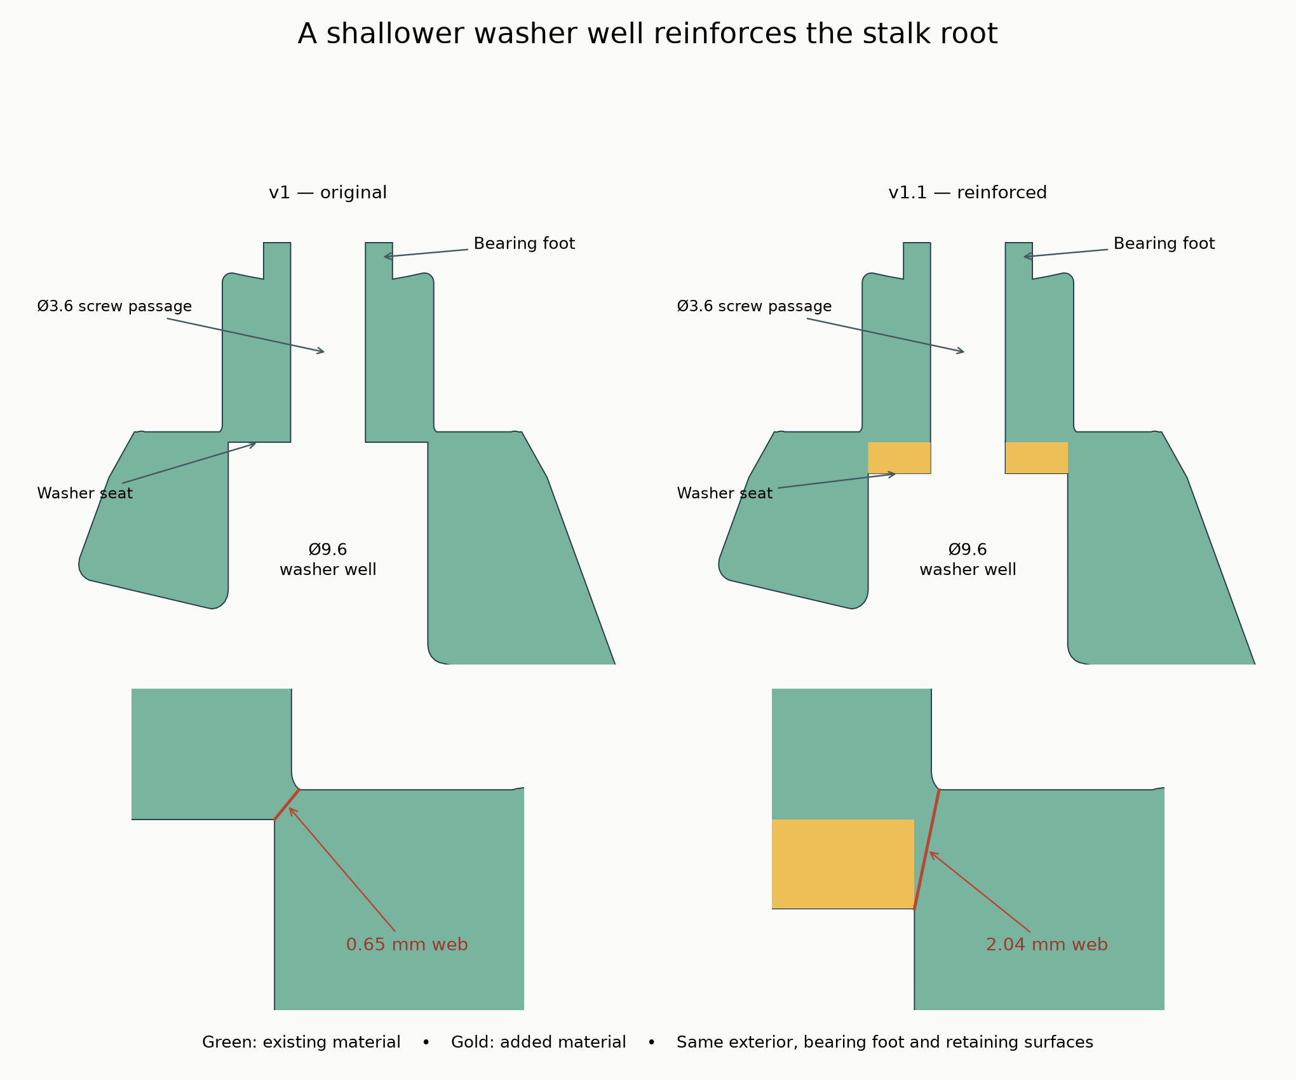
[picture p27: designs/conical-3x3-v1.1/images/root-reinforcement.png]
Stalk-root reinforcement


This is a geometric reinforcement, not a measured strength or endurance rating.
For the revised centers, retain the recommended walls and solid layers around
the washer seat; sparse infill alone is not a substitute for that load path.

## What to print

Print exactly one of each of the **27 files in `stl/puzzle/`**:

- `core.stl`: default 5.40 mm terminal nut seats.
- `C01`–`C06`: six screwed centers.
- `E01`–`E12`: twelve floating edges.
- `K01`–`K08`: eight floating corners.

The STLs are already on the bed, in millimetres. Use **100% scale**. E pieces have their inward radial vector pointing down, as preferred on the
previous prints. K corners and C centers use a broad exterior face down;
the K pieces otherwise have almost point-sized initial bed contact. The core
uses an axle flat down. Geometry-only 3MF plates preserve those poses and the object names.
They do not silently install a printer or filament profile.

The `E-face-down` / `K-radial-down` plates and individual `print-options/` files
are **alternate orientations of the same pieces**, not extra parts to print.
Do not print both sets. Keep the default radial-down pose for the edges to continue the approach
that worked on the Redi. The optional radial-down corner pose requires supports
under the tiny initial tips; the default broad-face-down corners have much
more bed contact.

Print the nut coupons first. `core-seat-5.30` and `core-seat-5.50` are optional
replacement cores with tighter/looser final seats; choose only one core.
The loading mouth is 5.85 mm in all variants. Test the actual DIN985 nut by
fully driving a screw through its nylon ring, not just by checking whether the
nut stays in place. The optional stand supports the core during assembly and
is removed before the last center is fitted.

## Hardware

- **6 × DIN912 M3 × 20 mm screws**.
- **6 × washers, 9 mm outside diameter × 1 mm thick**, with M3 clearance holes.
- **6 × DIN985 M3 nylon-insert locknuts**, nominal 5.5 mm across flats × 4 mm high.
- A matching hex key; a blunt approximately 3 mm rod to seat the nuts.

Besides the core, there are no separate hidden printed parts. The core,
26 visible pieces and six hardware stacks are the whole mechanism; assembly
uses no sleeves, inserts, springs, magnets or glued joints. The optional stand is an assembly tool only.

## Printing on the P1S

Use the 0.4 mm nozzle and PLA for the first trial, so that the material stays
consistent with the successful earlier builds. A practical starting point is
0.16 mm layers, 4 walls and 20–25% infill; use more walls/infill for the core if
desired. These are suggested starting settings; the successful-print report
did not restate the exact slicer settings used. Use a brim on the small radial-down footprints and removable
supports for the flange undersides. Inspect support placement before slicing;
keep the screw bores and nut-loading channels accessible. Small channel roofs
can be bridged; avoid packing inaccessible support inside a nut seat.

Remove support residue and raised seams from the sliding surfaces, especially
under the retaining lands. Do not sand away the lands or enlarge the main cone
gaps as a first step. The broad track clearance and close main faces have
different jobs. Any elephant foot on a radial-down retaining end needs removal.

The delivered meshes were checked for a connected printable layer graph at
0.16/0.42 mm and 0.20/0.45 mm layer-height/line-width combinations. This is a
geometric check, not Bambu Studio toolpaths or a physical strength test.

## Assembly

1. Mark every piece on its inside using [the ID map and neighbor table](NEIGHBORS.md).
   Open `reference/DO-NOT-PRINT-solved.3mf` to inspect the named solved assembly.
2. Load all six locknuts into the bare core through their side channels. Orient
   each nut with its nylon ring **toward the core's center**, so the screw enters
   the metal threads first. Press the nut into the tighter final seat with a
   blunt rod. Check all six seats against installation torque before covering them.
3. Optionally attach the assembly stand in the **C01** position, using the same
   screw and washer that will later hold C01. It leaves the other insertion paths
   open. Temporary tape or elastic bands around the outside can help hold loose
   pieces while the retainers are still absent.
4. Place **all eight K corners first**, then **all twelve E edges**, matching the
   outside shape and IDs. Each has a straight inward radial insertion path at
   this stage. No flange must be forced through another flange.
5. Fit C02–C06 over their corresponding core flats. Drop a washer down each
   access well and install its screw into the locknut. Start loose enough to
   permit small alignment adjustments. The centers retain the edges, which
   in turn retain the corners.
6. Support the assembly, remove the stand's screw and washer, and withdraw the
   stand straight along the C01 axis. Install C01 with that screw and washer.
   If no stand was used, simply install C01 last.
7. Adjust the six centers evenly. Tighten until the assembly just becomes firm,
   then back off slightly until it turns without force. M3 coarse pitch is
   0.5 mm, so **one fifth of a turn corresponds to 0.10 mm** of axial adjustment.
   Locknut drag is not the same as bearing clamp load: judge by the puzzle's feel.
   Remove any temporary tape/bands before turning.

Keep the screw adjustment small. The tests include modest center lift, but
excess lift can increase rocking and eventually allow popping. Do not force
a turn through support scars, a badly misaligned layer, or a tight nut seat.

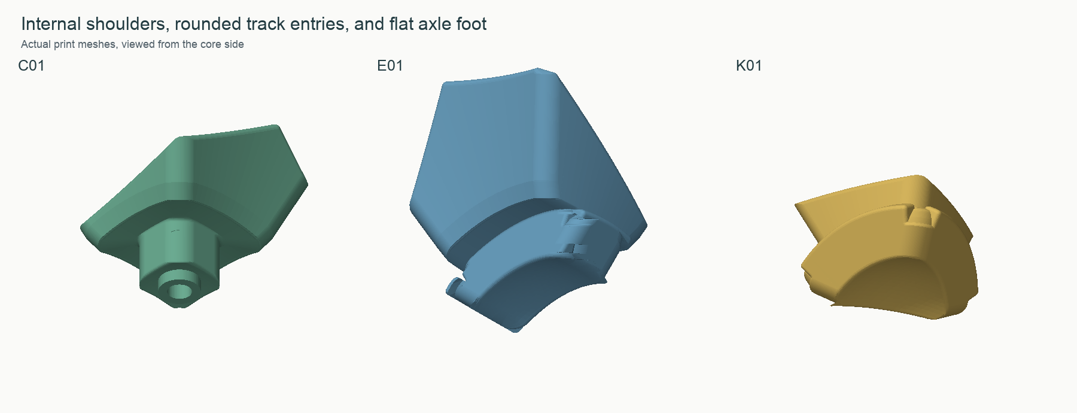
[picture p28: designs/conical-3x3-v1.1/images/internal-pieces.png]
Mechanism pieces


## Design details and evidence

See [DESIGN.md](DESIGN.md), [NEIGHBORS.md](NEIGHBORS.md), and the JSON files in
`reports/`. Those reports check the **reloaded delivered STLs**, not only the
pre-export CAD. They include turns, scrambled positions, insertion and stand
withdrawal, hardware access, sampled extraction paths, fillet sections,
printable connectivity, and plate placement.

Full regeneration source is in `source/`; `manifest.json` records part hashes,
dimensions, volumes and the rigid print-to-assembly correspondence. The solved
reference is for inspection only. MIT license covers the source and generated
design. No print has been sent to a printer by this package.

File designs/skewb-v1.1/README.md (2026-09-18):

# Wonky Skewb — 64 mm v1.1

A Skewb shape mod adapted from the successful compact Wonky Redi v4.3: the same
64 mm outer cube, exterior rotation, M3 hardware stack, close main faces, generous
internal track allowance and rounded radial ridges.

**Owner-tested v1.1:** on 2026-09-18 the owner reported that the trimmed Skewb printed very well and turns very nicely. The STL hashes match the delivered revision associated with that report. See [physical-feedback.json](physical-feedback.json) for the
report, its scope and the supplied file hashes. This is qualitative owner feedback;
holding force, turn torque and long-term wear were not measured.

Solved and exploded

There are **14 shell pieces and one core**: four screwed corners C01–C04, six
floating face pieces F01–F06 and four floating corners K01–K04. The core has four
axes in a tetrahedral arrangement. A 120° turn carries one screwed corner, three
F pieces and three K pieces. The other three screwed corners remain on the core.
The outside cuts are central planes, so their intersections with the cube are
straight. Only the hidden retaining regions depart from those planes.

## v1.1: floating-corner flange tips removed

K01–K04 have the three thin, perforated flange corners explicitly trimmed away.
The broad retaining lobes remain. The v1 slicer issue arose because the nominally
connected tips had webs too thin to form extrusion paths. This revision removes
them from the CAD, instead of relying on slicer repair or adding supports to waste
material on isolated fragments.

Only the four K parts need replacing. All other STL files match v1 byte for byte.
The outside shape, part IDs, assembly order, hardware and main running clearances
are retained. See [TIP-REVISION.md](TIP-REVISION.md) for the change and its checks.

Floating-corner revision

## What is retained from your last print

| Feature | Skewb v1.1 |
|---|---|
| Nominal cube side | 64 mm |
| Exterior rotation | Same orientation as the compact Redi; not reoptimized |
| Main planar-face gap | 0.03 mm total |
| Extra internal track allowance | 0.40 mm on the receiving side of the rotational profile |
| Radial dihedral rounding | Nominal R3 transverse circles, continuing through the tracks |
| Other inner lead-ins | 0.60 mm on the positive cut profile; 0.45 mm on its receiver |
| Exterior edge softening | 0.80 mm |
| Spherical core radius | 19.20 mm; bearing flats at 17.60 mm |
| Rotating screw bore | Ø3.6 mm |
| Washer/access well | Ø9.6 mm |
| Washer seat | 27.30 mm from the center along each screw axis |
| Corner bearing foot | Flat annulus, Ø6.2 mm outside, starting at radius 17.70 mm |

The retaining geometry is new for the Skewb. F pieces hook under the screwed
corners; K pieces hook under the F pieces. The side-loading reliefs allow assembly
in that same order reversed: **K → F → C**. All retaining feet are integral with
the shell pieces. There are no glued caps or separate hidden plastic carriers.

## Hardware and improved nut pockets

Use **four each** of your DIN912 M3 × 20 screws, M3 washers of **9 mm OD × 1 mm**,
and DIN985 M3 locknuts. A bare 2.5 mm hex key reaches the screw heads. Your 20 mm
screws fit: their tips reach radius 8.30 mm, 3.35 mm beyond the nut's nominal inner
face, and the four screws clear one another.

The core implements the requested narrowed nut seat. The loading mouth stays
**5.85 mm wide**, with a taper to a **5.40 mm final seat across flats** around the
bore. A nominal 5.5 mm nut therefore has 0.10 mm total interference at the seat.
A blunt Ø3 mm rod has a checked sideways pressing path. The slot roof captures
the nut axially; the close parallel flats and back of the hex seat resist rotation.

Check the press fit with your actual nuts and print. Three
fit coupons and matching 5.30 / 5.40 / 5.50 mm core seats are included. The default
`core.stl` is 5.40 mm. **Drive a screw through the nylon ring in the coupon:** an
insertion fit alone does not establish resistance to installation torque. Test
all four seats in the actual core before assembling the puzzle.

Hardware and nut pocket

## Files and first print

1. Print the nut-fit coupons and rotor from `plates/fit-coupons-01.3mf`.
2. Choose one core matching the tightest coupon that seats without cracking and
   holds the nut under screw torque. Print C01–C04, F01–F06 and K01–K04 once each.
3. Follow [ASSEMBLY.md](ASSEMBLY.md), marking IDs using [NEIGHBORS.md](NEIGHBORS.md).

The STLs in `stl/puzzle` have F/K pieces pointing inward toward the print bed,
following your successful Redi orientation. Skewb tips are much smaller, so they
need support and careful bed adhesion in this orientation. **Face-down 3MF
alternatives** are supplied in `print-options` and the two `*-face-down` plates;
these have a broad exterior face on the bed and use exactly the same geometry.
Choose one orientation per piece, not both. The face-down files are a useful
starting option for a first Skewb build, especially K01–K04. The owner did not
restate the chosen orientation or detailed slicer settings in the success report.

All 3MFs are geometry only, without printer settings. Print at 100% scale; inspect
support placement in the slicer. The named reference `DO-NOT-PRINT-solved.3mf`
shows the solved assembly; it is not a print-in-place model. Plate maps and
identification images are included.

The optional assembly stand uses one of the four screws temporarily. The parts
are not interchangeable with the Redi or the 65° prototype, despite the shared
size and hardware. The Redi source and release are unchanged.

Read [DESIGN.md](DESIGN.md) for the mechanism, [VALIDATION.md](VALIDATION.md) for
checks and limits, and [source/README.md](source/README.md) to regenerate it.
MIT license covers the models, documentation and code; see [LICENSE](LICENSE).

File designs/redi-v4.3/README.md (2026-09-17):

# Compact Wonky Redi — 64 mm v4.3

The **20-piece Redi-equivalent puzzle**, regenerated from the v4.2 construction
with a smaller mechanism, captive DIN985 nuts, 9 × 1 mm washers, and closer
conical faces. This is separate from the 65° puzzle: it has **eight C pieces,
twelve E pieces, and one core**, with no petals or dual centers.

The owner has printed and assembled this compact revision and reports that the
mechanism feels very nice, apart from the nut-seat issue below. This release
preserves the supplied radial-down print geometry without rebuilding its meshes.
The exported meshes also have computational checks; see [VALIDATION.md](VALIDATION.md).

Solved compact cube

## Changes from v4.2

| Feature | This revision |
|---|---|
| Solved cube | 64 mm, down from 80 mm |
| Exterior orientation | Original optimized wonky orientation retained |
| Conical half-angle | 54.7356103°, the original Redi cut family |
| Main-face nominal gap | 0.03 mm total, down from 0.20 mm |
| Rail dimensions | Regenerated at 80% of the original linear dimensions |
| Flange-track allowance | 0.40 mm expansion of the **unrounded** flange sweep; not scaled down |
| Edge radial ridges | Constant 3 mm transverse rounding through the track region |
| Other inner lead-ins | 0.60 mm on edges; 0.45 mm on corners |
| Outer edge softening | 0.80 mm, applied before the R3 ridge cut, as in the v4.2 sequence |
| Screws | 8 × DIN912 M3 × 20, flat underside, 2.5 mm hex key |
| Washers | 8 × 9 mm OD × 1 mm thick, with M3 clearance hole |
| Nuts | 8 × DIN985 M3, nominal 5.5 mm across flats × 4 mm high |
| Rotating shank hole | Ø3.6 mm |
| Washer/access well | Ø9.6 mm |
| Core screw passage | Ø3.4 mm, through the core along each pair of opposite axes |

**Your 20 mm screws fit; shorter screws are not needed.** Their tips stop at an
8.30 mm radius from the puzzle center. The nominal nut's inner face is at
11.65 mm, so the screw extends 3.35 mm beyond it. The eight screw envelopes clear
one another and the printed core. That extra screw length occupies already
available space inside the core.

The core's rounded portions are spherical (radius 19.20 mm). Its eight bearing
flats are 17.60 mm from the center; one of these existing flats is the print bed
face. Side-loading nut pockets have a 1.95 mm retaining roof and small grip ribs,
using the same capture method as the 65° core. No inserts, glued caps, or separate
hidden retainers are used.

## Known core issue: nuts can spin

In the owner's build, about half of the nut seats are loose enough for a nut to
rotate while the screw is driven through its nylon locking ring. The retaining
roof captures the nut axially, but the current seat does not reliably react the
installation torque. The small grip ribs are not a proven torque lock.

The next change should affect **only the core**: retain the easy-loading slot
entrance, then narrow the final seating region around the screw bore, with a
short lead-in so a nut can be pushed firmly home using a blunt metal rod.
Preserve the nut depth, roof, screw alignment, core bearing flats and outer
envelope so the existing C and E pieces remain compatible. The final interference
must be selected by printing a coupon and driving a screw through the actual
locknut; insertion feel alone is insufficient.

**This is a pending improvement, not a change in these STL files.** The existing
5.50/5.60/5.70 mm core variants change the pocket width; they do not implement a
separately narrowed terminal seat and are not claimed to solve the reported issue.

## Size

At 64 mm, the bounding volume is 51.2% of the 80 mm cube's. Actual filament and
print time depend on walls, infill, orientation, and support. The size was chosen
to retain useful flange and bearing material while preserving the 3 mm rounding.
This is a checked compact size, not a claim of the smallest theoretically possible
mechanism.

Hardware section

## Print orientation update

The twelve edge STLs and their print plate now have the inward radial direction
pointing down (−Z), with their lowest point on the bed. This is an orientation-only
update: piece shapes and dimensions are retained. All other STLs are unchanged.

## Files to use

- `stl/puzzle`: print C01–C08, E01–E12, and one core.
- `plates`: geometry-only 3MF print plates, with named objects; use
  [plate maps](plate-maps.html) to retain the IDs. Choose slicer settings yourself.
- `stl/fit-coupons`: three nut fits (5.50, 5.60, 5.70 mm) and a rotor for your
  actual screw/washer combination. Default `core.stl` uses the 5.60 mm pocket.
- `stl/optional`: alternate cores matching the other coupons, plus a removable
  screw-mounted assembly stand. Print only one core for the puzzle.
- `reference/DO-NOT-PRINT-assembled-cube.3mf`: named solved geometry for orientation.
- [NEIGHBORS.md](NEIGHBORS.md): the Redi part IDs and solved seam neighbors.
- [ASSEMBLY.md](ASSEMBLY.md): print, nut-loading, assembly, and adjustment guide.
- [VALIDATION.md](VALIDATION.md): checks performed and their limits.
- `source`: MIT-licensed CAD, canonical masters, and regeneration scripts.

The compact pieces **do not interchange with the 80 mm v4.2 parts or the 65°
prototype**. The C/E IDs retain their v4.2 Redi positions; the 65° list uses a
different edge ordering, so use this package's neighbor sheet.

## Adjustment

The bearing foot sits nominally 0.10 mm above its core flat. Tightening the screw
brings the foot toward the flat; backing off an M3 screw by one fifth turn (72°)
moves its head outward by 0.10 mm. Adjust gently by feel, rather than applying a
metal-fastener torque to plastic.

The close main faces reduce geometric slack. The intentionally wider tracks
still allow some edge movement, so screw tightening does not independently remove
all flange clearance. The checks measure geometry, not the exact hand feel or a
guaranteed “bind then release by 0.10 mm” setting. The 0.03 mm gap is below typical
FDM dimensional variation; remove support scars and burrs before forcing a turn.

MIT license, including models and CAD; see [LICENSE](LICENSE).

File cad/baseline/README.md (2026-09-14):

# Frozen v4.1 baseline

This is the numerical starting point for the v4.2.1 publication export.

- `reference/assembly_meshes.npz`: named vertex and triangle arrays in mechanism coordinates, including the earlier edge shapes.
- `reference/design.json`: the matching dimensions and print transforms.
- `parts/`: unchanged core and eight corner print STLs, copied byte-for-byte by the builder.
- `calibration/`: seven baseline fixture/jig STLs; the three moving edge segments are regenerated.

The baseline avoids rebuilding expensive earlier rounding operations and preserves the exact earlier shape and print frames. It is original project geometry covered by the root MIT license. The source for the preceding operations is retained one directory above. Historical full release bundles contain the earlier complete builds.

Changing an upstream constant does not retroactively change these frozen meshes. Rebuild the upstream stages explicitly when changing the core, rail, exterior or track design; do not expect the latest subtract-only edge builder to resize them.

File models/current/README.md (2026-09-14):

# Current printable set — v4.2.1

Use [the printing and assembly guide](../../docs/printing-and-assembly.md).

- `parts/`: core, C01–C08 and E01–E12, one each (21 puzzle STLs).
- `plates/`: two edge plates, two corner plates, a core plate, and an optional E12 comparison plate. Geometry only, in millimetres; use 100% scale.
- `calibration/`: assembly stand, fit coupon and the optional five-part single-axis fixture.
- `reference/`: assembled inspection model, mechanism-space arrays, dimensions, section drawings and four verification reports.
- `SHA256SUMS.txt`: checksums for the exact checked files in this folder.

The assembled 3MF is for inspection, not printing as a fused object. File IDs identify solved positions; keep those IDs associated with your printouts.

This publication export continues the 3 mm radial rounding through the inner track. It reuses the core and eight corners byte-for-byte from the earlier set. The owner reported a successful v4.2 print; this fresh v4.2.1 export has digital checks and has not separately been reported printed. See [validation](../../docs/validation.md).

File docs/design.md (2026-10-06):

# Redi design reference

For **new designs and retention revisions**, use concentric spherical-shell retaining shoulders centered on the puzzle origin, so the broad holding faces are orthogonal to the local radius. Preserve angular overlap, round flange ends in radial outline, and allow sliding-track clearance separately from main-body clearance. Flat washer seats and matching axle pads are separate interfaces. See [mechanism principles](mechanism-principles.md#default-for-new-designs). The dimensions below describe the specific Redi geometry.

For reusable hardware geometry, see the self-contained [captive DIN985 M3 nut-slot specification](#captive-din985-m3-nut-slot-specification): **5.25 mm terminal seat and 5.85 mm entrance**. It includes exact CAD construction and fit checks for another project.

For the newer, owner-tested Skewb with trimmed flange tips, see its [design reference](../designs/skewb-v1.1/DESIGN.md) and [print files](../designs/skewb-v1.1). This page records the separate Redi design.

The current **v4.3** design is a 64 mm Redi-equivalent puzzle: eight screw-mounted
C pieces and twelve movable E pieces around one core. Each 120° turn rotates one
C piece and cycles its three neighboring edges. It has the original Redi cut
family, not the later experimental 65°/petal topology.

The owner has built the compact version and reports that everything except the
nut retention feels very nice. The release preserves that geometry and records
the remaining core issue below. See the [complete compact description](../designs/redi-v4.3/README.md),
[assembly guide](../designs/redi-v4.3/ASSEMBLY.md) and
[validation/provenance](../designs/redi-v4.3/VALIDATION.md).

## Coordinates and exterior orientation

The mechanism center is the origin. Its eight turn axes are
`(±1, ±1, ±1) / sqrt(3)`, ordered from C01 `(−,−,−)` to C08 `(+,+,+)`.
Each edge joins two axes whose dot product is `1/3`.

The cube-to-mechanism rotation is unchanged from v4.2:

`R = Rz(−13.232962300°) · Ry(26.192857308°) · Rx(32.391706195°)`.

These are fixed-axis rotations applied X, then Y, then Z to column vectors.
The full precision matrix is in [cube-to-mechanism.json](../designs/redi-v4.3/reference/cube-to-mechanism.json).
The original search maximized the minimum sampled radial-profile difference
between pairs of edge exteriors under their two compatible proper mounting
orientations; mirror images count as different. It is a best-found numerical
orientation, not a proof of a global or perceptual optimum. The compact revision
retains it and rechecks all 66 pairs on the exported meshes; the weakest sampled
pair has an RMS exterior difference of 3.024 mm.

Edge attachments intentionally interchange so the puzzle can scramble. Their
different exteriors distinguish solved positions; the parts are not mechanically
keyed to a single slot. Use the compact [neighbor sheet](../designs/redi-v4.3/NEIGHBORS.md).

## Dimensions and compatibility

All lengths are millimetres. Clearance values below describe different interfaces;
they are not interchangeable tolerances.

| Feature | Compact v4.3 | Previous 80 mm v4.2.1 |
|---|---|---|
| Solved exterior | 64 | 80 |
| Cone half-angle | 54.7356103° | Same |
| Core spherical radius | 19.20 | 24 |
| Core bearing-flat distance from center | 17.60 | 22 |
| Main conical-face gap, total | 0.03 | 0.20 |
| Track cutter expansion from unrounded flange sweep | 0.40 | 0.40 |
| Radial ridge transverse radius, including inner tracks | 3.00 | 3.00 |
| Internal edge / corner lead-in rounding | 0.60 / 0.45 | Same |
| General exterior softening | 0.80 | 1.00 |
| Rotating screw bore | Ø3.60 | Ø3.30 |
| Washer outside diameter × thickness | 9 × 1 | 13 × 0.55 |
| Washer/access well diameter | 9.60 | 13.80 |
| Screw | DIN912 M3 × 20, 2.5 mm hex key | M3 × 20, flat head underside |
| Thread anchorage | Captive DIN985 M3 nut | Ø2.60 direct-to-plastic pilot |

The compact rail dimensions are regenerated at 80% of the old size, while the
track allowance and R3 ridge rounding remain unscaled. The smaller washer well
allows the surrounding structure to shrink. Uniformly scaling the old STL would
also shrink hardware holes and working clearances, and would not produce this design.
The compact and 80 mm parts **do not interchange**. The older
[design reference](design-v4.2.1.md), [files](../models/current) and
[release](https://github.com/lukacslacko/wonkycube/releases/tag/v4.2.1) remain available.

## Retention, motion and bearings

Stepped surfaces of revolution provide flat retaining shoulders. Their remaining
overlap obstructs outward edge movement. Neighboring passages are derived from
the swept **unrounded** flanges, expanded by 0.40 mm; the printed flange receives
its small rounding separately. The long radial ridges use a constant 3 mm radius
in transverse sections, continuing through the inner track region. These features
provide entry relief while preserving capture material.

Reducing the main-face gap to 0.03 mm addresses one source of slack while keeping
the established track allowance. It does not eliminate every degree of freedom:
the retained track geometry still has measured radial travel before obstruction.
The numerical checks and physical feedback are detailed in
[VALIDATION.md](../designs/redi-v4.3/VALIDATION.md).

The core remains spherical between its eight intentional bearing flats and prints
on one of those flats. Each C piece has a matching flat annular foot, radius 3.20,
at axial coordinate 17.70, nominally 0.10 above the core flat. The stationary
screw clears the rotating Ø3.60 bore; the washer limits axial movement. The washer
seat is at 27.30, its top at 28.30, and the 20 mm screw tip at 8.30. The nominal
nut occupies axial coordinates 11.65–15.65, leaving 3.35 mm of screw past its inner
face. The eight screw envelopes clear each other, so shorter screws are not needed.

The nut loads sideways beneath a 1.95 mm roof, metal face toward the screw and
nylon end toward the center. The reusable specification below defines the
recommended pocket for new CAD. The [Redi source](../designs/redi-v4.3/source/README.md)
records the geometry of its supplied print files.

Compact hardware dimensions

## Captive DIN985 M3 nut-slot specification

### Recommended dimensions

For a side-loaded **DIN985 M3 nylon locknut in an FDM PLA part**, start with a
**5.25 mm across-flats terminal seat and a 5.85 mm wide loading entrance**.
Keep the entrance wide: only the short region next to the screw axis should
grip the nut tightly.

This recipe assumes a nominal **5.50 mm across-flats, 4.00 mm high nut**. Measure
the actual hardware before adapting it to another nut type or size. All values
below are **CAD dimensions in millimetres**, not measured printed dimensions.

| Parameter | Value | Meaning |
|---|---:|---|
| `seat_af` | **5.25** | Recommended size, across opposite flats of the final hex seat |
| `entry_width` | **5.85** | Width of the accessible side-loading passage |
| `tight_run` | **3.00** | Distance from the screw-axis center to the start of the widening taper |
| `taper_run` | **3.00** | Length of the taper along the insertion path |
| `slot_height` | **4.25** | Cavity height along the screw axis for the nominal 4.00-high nut |
| `bore_diameter` | **3.40** | Clearance hole through the stationary host, coaxial with the nut |
| Screw-side retaining roof | **About 2.00** | Solid material above the nut cavity; 1.95 is the reference geometry |

At `seat_af = 5.25`, a nominal 5.50 mm nut has **0.25 mm total interference**,
or **0.125 mm per opposing flat**. This deliberately tight fit depends on the
printed plastic yielding locally. Do not add a normal sliding-fit clearance
to the terminal seat.

**5.25 mm is the owner-confirmed good seat size.** Use it as the nominal CAD
value when transferring this pocket to another project. The reference printer
setup is a Bambu Lab P1S, 0.4 mm nozzle and PLA. Validate the pocket in its actual
print orientation; this empirical fit does not imply a measured torque rating.

### Exact pocket construction for a CAD agent

Use a local coordinate system with the **screw axis along Z** and the **loading
opening toward +X**. The nut slides from the opening toward the origin, in the
**-X direction**. Its final threaded-hole center is at `x = y = 0`.

1. Make a regular hexagon centered on the origin in XY. Put vertices on the
   +X and -X directions, so two opposing flats lie at `y = +/- seat_af/2`.
   Its **circumradius is `seat_af / sqrt(3)`**, not `seat_af/2`.
2. Union that hexagon with the channel polygon below. Its width is `seat_af`
   from **x = 0 to 3**, increases linearly to `entry_width` from **x = 3 to 6**,
   and stays at `entry_width` from **x = 6 to the outside of the host part**.
   The 3 mm tight run is measured from the screw axis, not from the mouth or
   from the edge of the hexagon.
3. Extrude this union by `slot_height` along Z. Subtract it from the host so
   that a solid roof remains on the screw-entry side. Subtract a coaxial
   `bore_diameter` hole through the required screw path.
4. Keep the pocket's sidewalls continuously connected to substantial host
   material. The roof carries axial load; the tight flats and their supporting
   walls react installation torque. Small handling ribs are optional and do
   not establish torque capacity. About 2 mm of roof is a starting geometry,
   not a universal strength limit; check the load path and layer orientation.
5. Provide a straight, accessible pushing path through the loading mouth for
   a blunt tool, approximately 3 mm in diameter. The final seat must be reachable
   without using the screw to force a misaligned nut into position.

```text
h = seat_af / 2
e = entry_width / 2
L = a distance beyond the outer surface, with L > 6

hex_vertices[k] = (seat_af / sqrt(3)) * (cos(k*pi/3), sin(k*pi/3))
                 for k = 0, 1, 2, 3, 4, 5

channel = [(0,-h), (3,-h), (6,-e), (L,-e),
           (L, e), (6, e), (3, h), (0, h)]

pocket = extrude(union(hexagon(hex_vertices), polygon(channel)), 4.25)
```

Choose the pocket's axial position from the new project's screw stack. The
nut's **metal face points toward the screw entry and retaining roof**; its
**nylon locking end points away from the screw entry**. Verify that the chosen
screw reaches through the nylon locking section without bottoming out or
colliding with other screws. For a rotating part, provide separate clearance
around the screw shank; **3.60 mm** is the reference rotating bore. Keep hardware
holes and interference dimensions independent of the overall model scale.
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

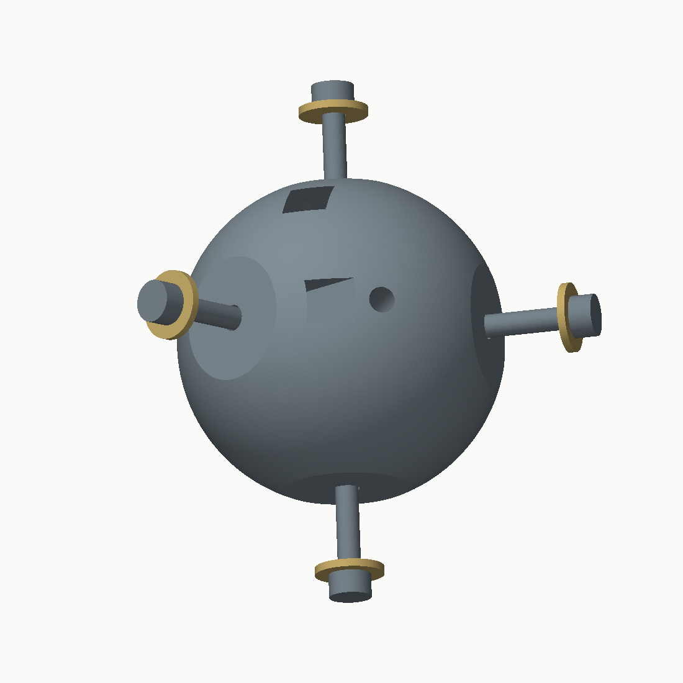
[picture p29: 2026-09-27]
designs/triangular-prism-v1/images/core-and-hardware.png

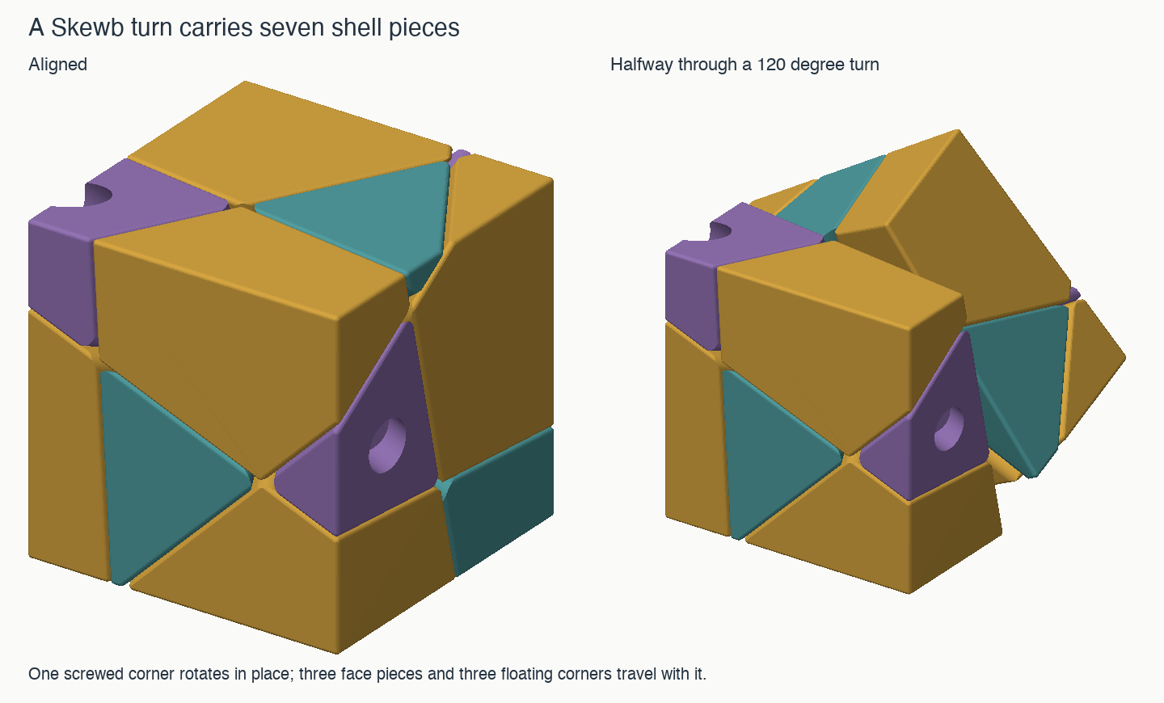
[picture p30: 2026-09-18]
designs/skewb-v1.1/images/turn.png

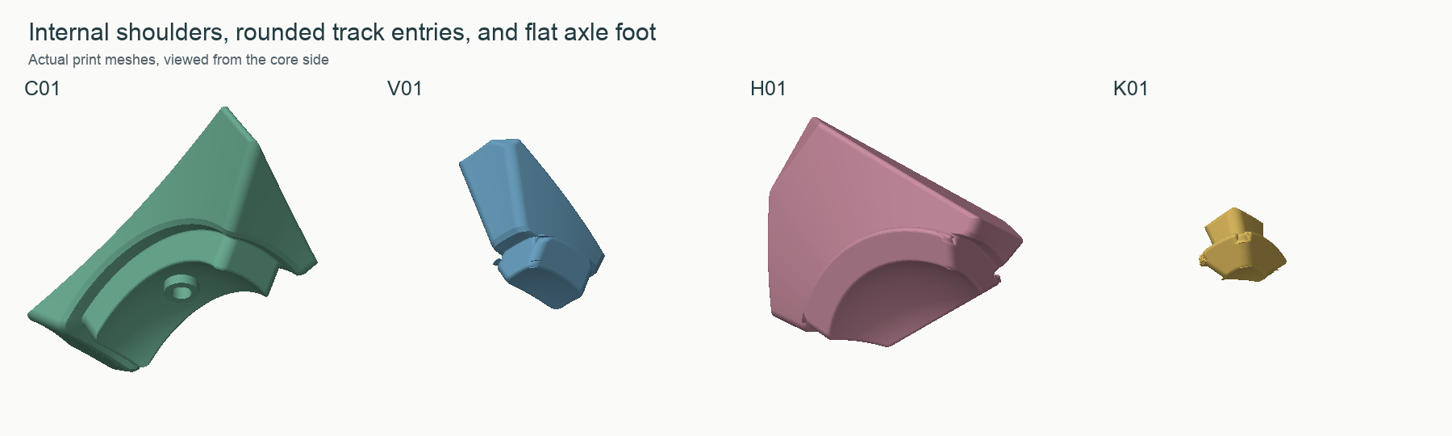
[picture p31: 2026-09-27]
designs/triangular-prism-v1/images/internal-pieces.png

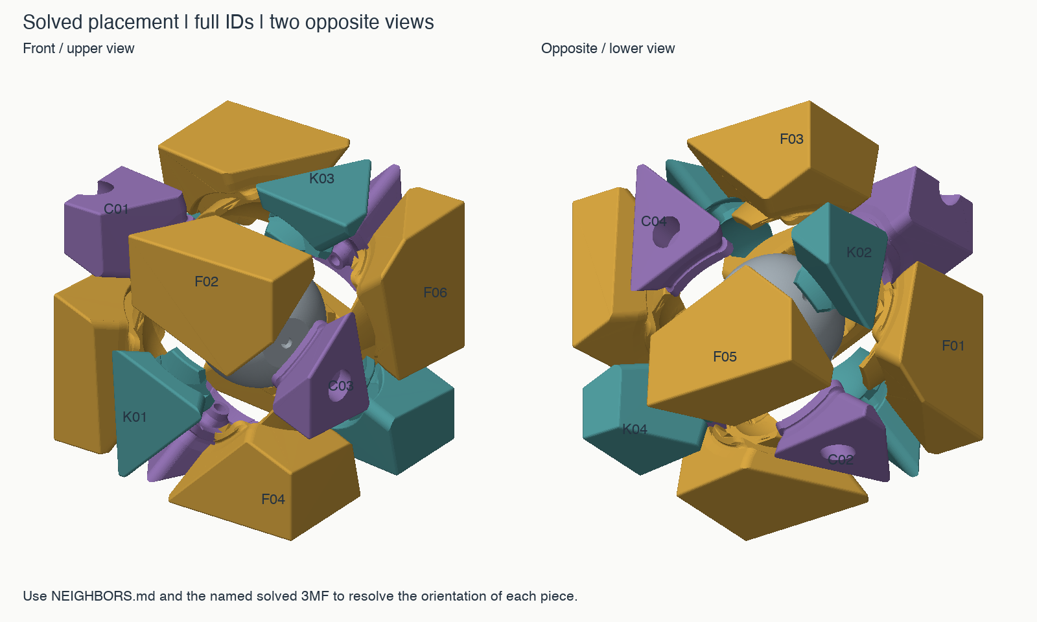
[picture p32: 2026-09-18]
designs/skewb-v1.1/images/piece-identification.png

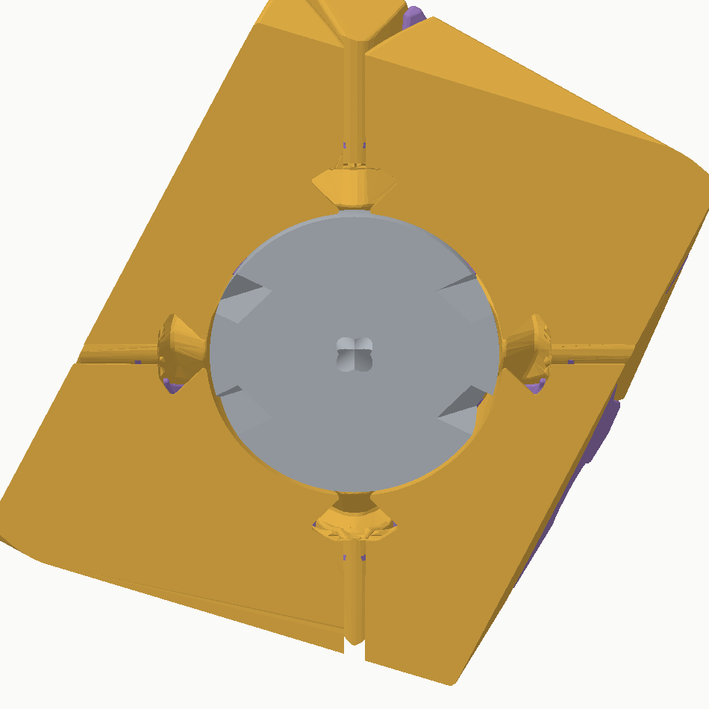
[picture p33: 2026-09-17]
designs/redi-v4.3/images/mechanism-section.png

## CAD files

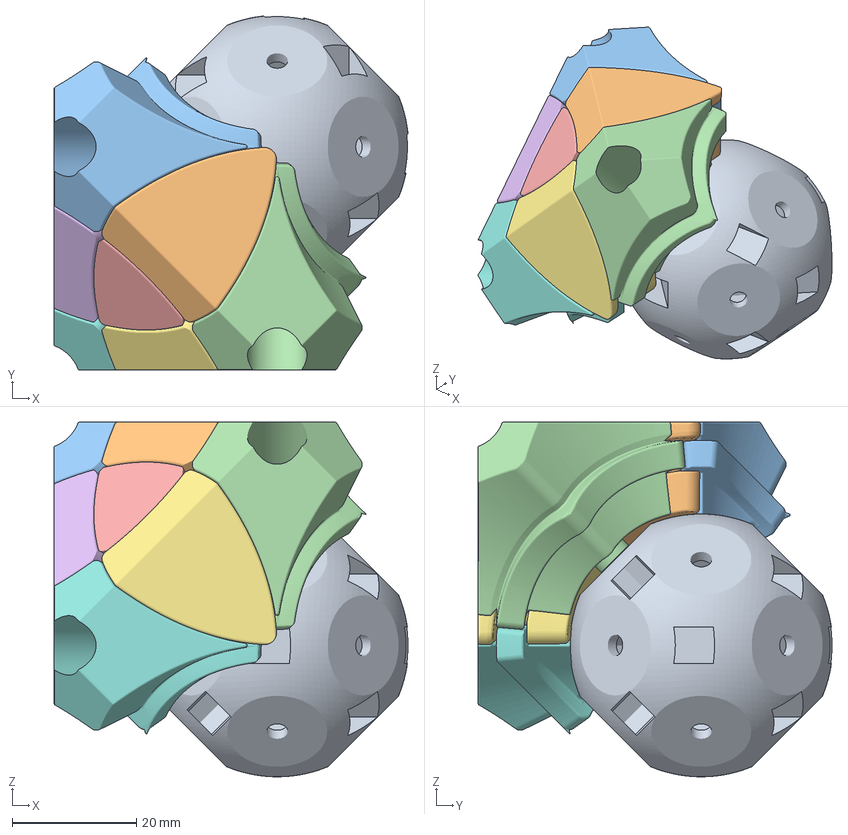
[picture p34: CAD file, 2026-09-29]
designs/curvy-copter-cuboctahedron-v3.2/start-here/DO-NOT-PRINT-test-assembly.3mf
57.1 x 57.1 x 57.2 mm
core
P01
C01
C02
K01
P05
P06
C05

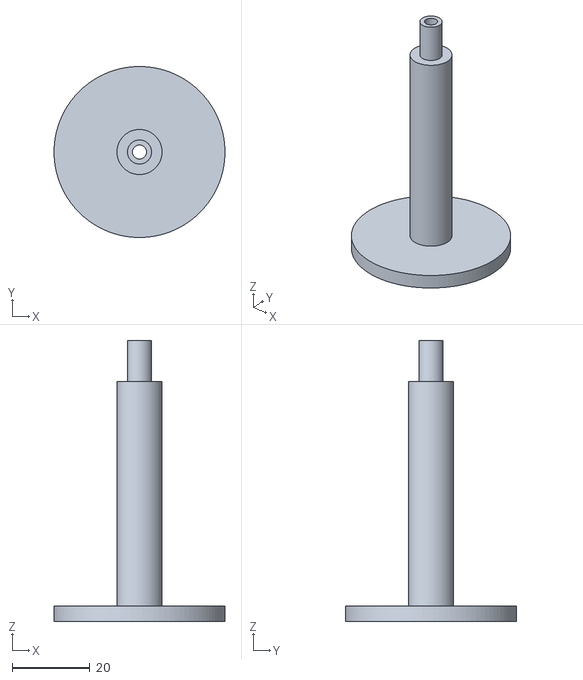
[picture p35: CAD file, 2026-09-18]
designs/double-ivy-v7.1/reference/optional/assembly-stand.stl
44.0 x 44.0 x 72.3

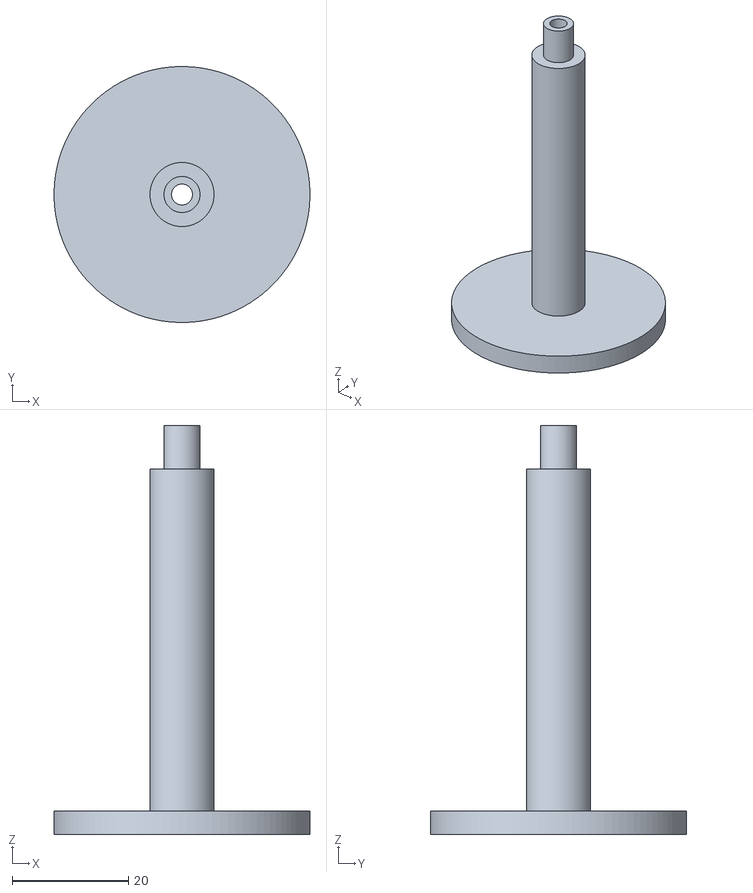
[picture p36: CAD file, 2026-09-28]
designs/rhombic-dodecahedron-v5.1/stl/optional/assembly-stand.stl
44.0 x 44.0 x 70.3

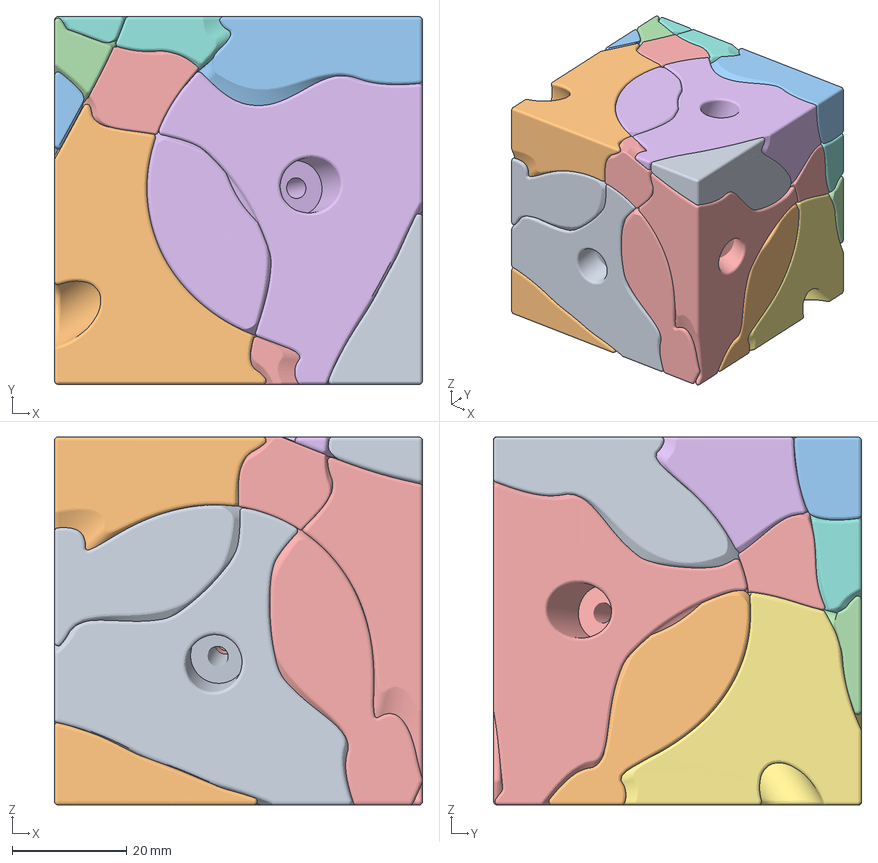
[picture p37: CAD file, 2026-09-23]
designs/wavy-redi-v1.1/reference/DO-NOT-PRINT-assembled-cube.3mf
64.0 x 64.0 x 64.0 mm
C01
C02
C03
C04
C05
C06
C07
C08
E01
E02
E03
E04
E05
E06
E07
E08
E09
E10
E11
E12
core

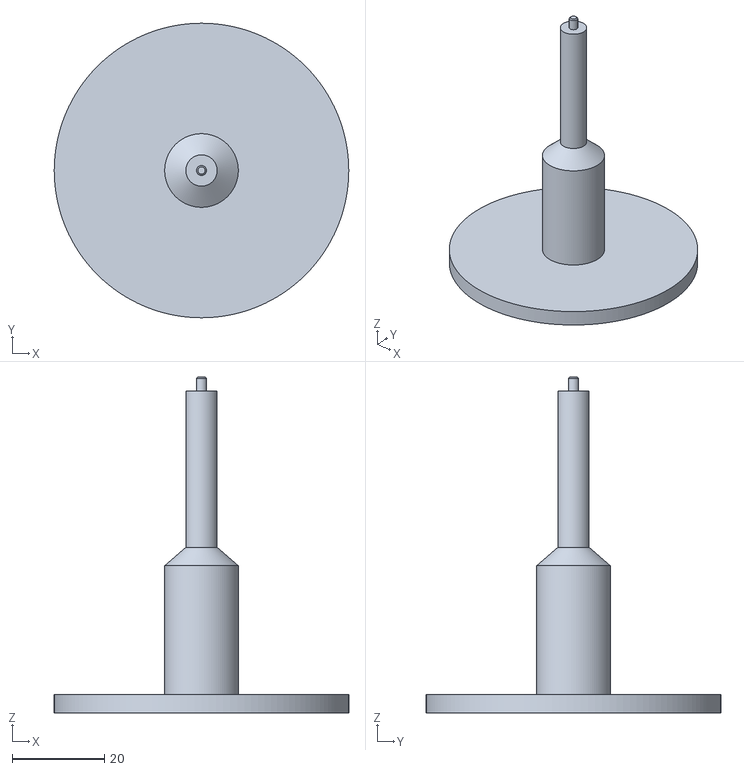
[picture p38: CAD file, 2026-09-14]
models/current/calibration/assembly_stand.stl
64.0 x 64.0 x 73.0

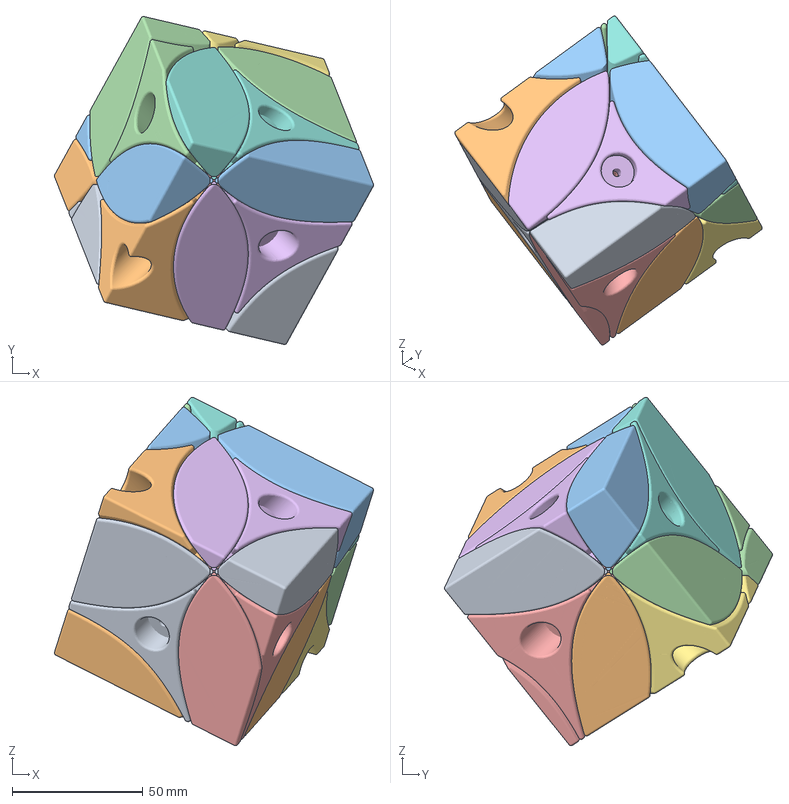
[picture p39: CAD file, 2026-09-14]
models/current/reference/assembled_reference_DO_NOT_PRINT.3mf
121.9 x 125.3 x 133.1 mm
C01
C02
C03
C04
C05
C06
C07
C08
E01
E02
E03
E04
E05
E06
E07
E08
E09
E10
E11
E12
core

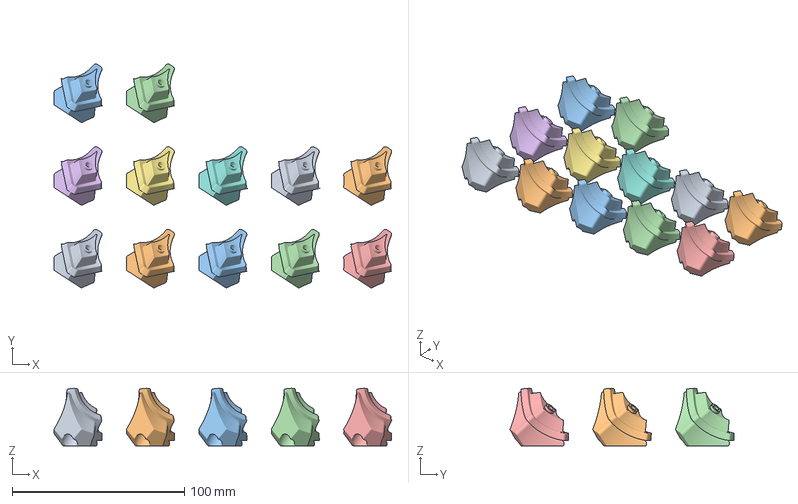
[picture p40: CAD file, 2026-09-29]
designs/curvy-copter-cuboctahedron-v3.2/start-here/centers-only-full-12-pieces.3mf
196.4 x 130.2 x 33.4 mm
C01
C02
C03
C04
C05
C06
C07
C08
C09
C10
C11
C12

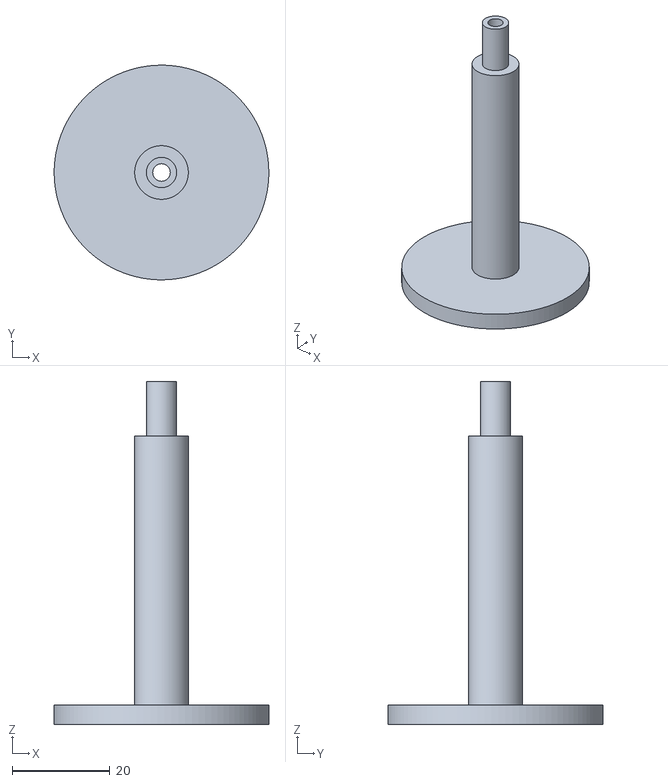
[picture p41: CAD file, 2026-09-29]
designs/curvy-copter-cuboctahedron-v3.2/stl/optional/assembly-stand.stl
44.0 x 44.0 x 70.3

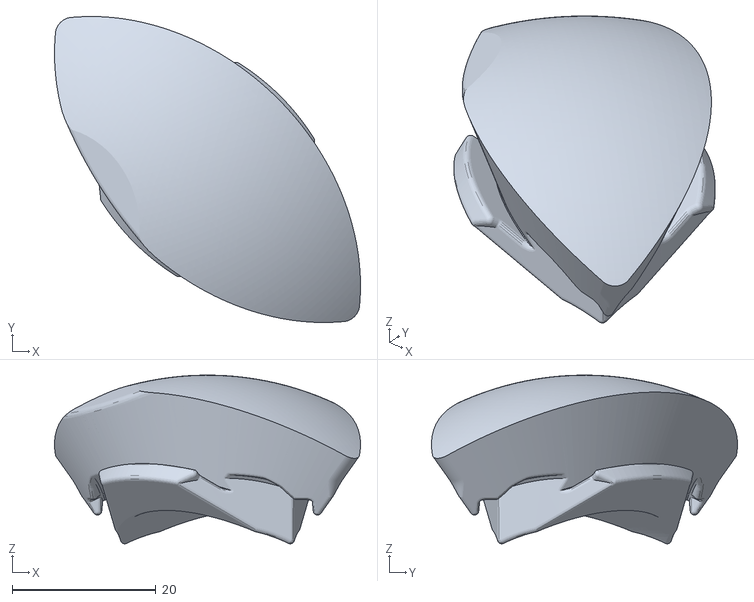
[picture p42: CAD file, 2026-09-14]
cad/baseline/calibration/test_edge_3.stl
42.6 x 42.6 x 23.5

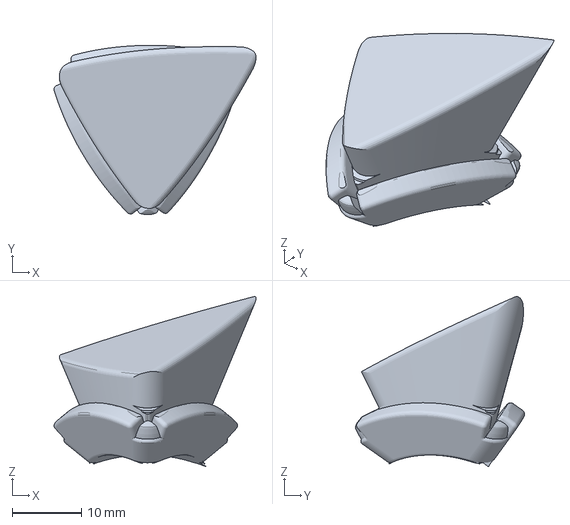
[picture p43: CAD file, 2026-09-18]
designs/conical-3x3-v1.1/print-options/K06-radial-down.3mf
29.2 x 24.4 x 24.5 mm

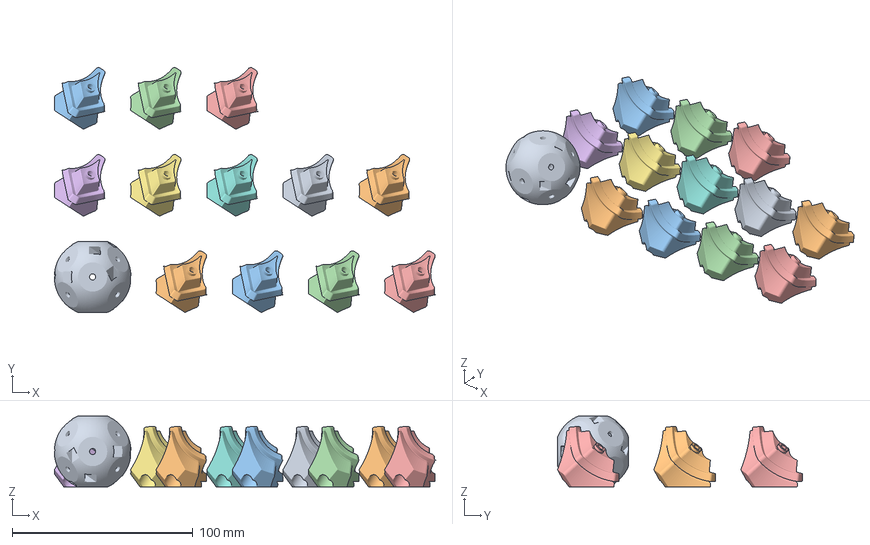
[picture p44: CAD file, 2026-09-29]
designs/curvy-copter-cuboctahedron-v3.2/plates/C-01.3mf
210.5 x 135.3 x 39.2 mm
core
C01
C02
C03
C04
C05
C06
C07
C08
C09
C10
C11
C12

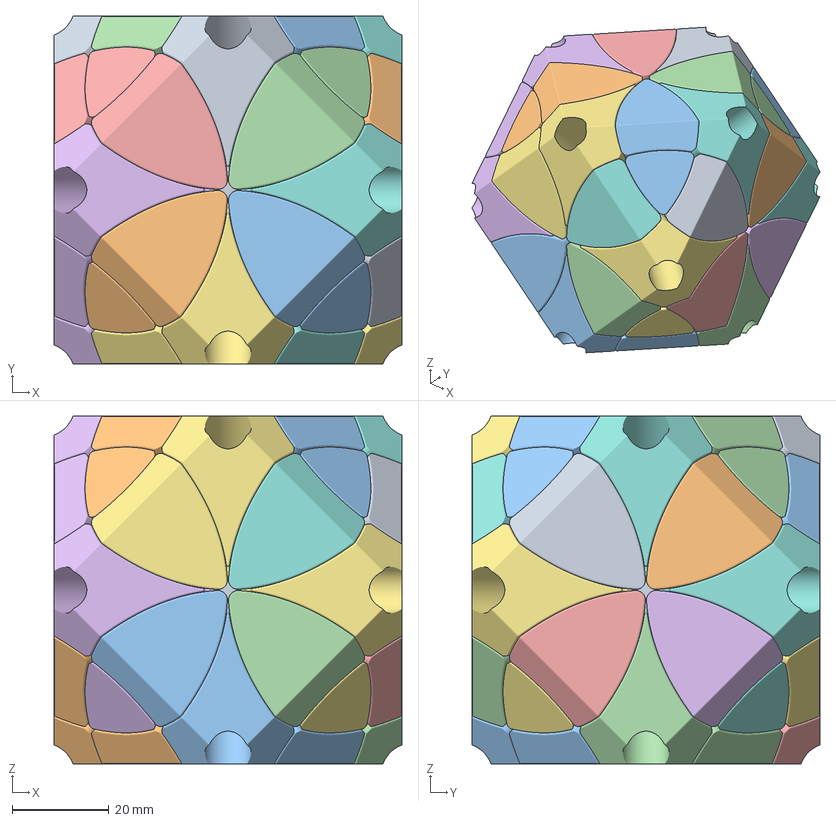
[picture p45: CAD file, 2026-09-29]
designs/curvy-copter-cuboctahedron-v3.2/reference/DO-NOT-PRINT-solved.3mf
72.0 x 72.0 x 72.0 mm
core
P01
P02
P03
P04
C01
C02
C03
C04
K01
K02
K03
K04
P05
P06
P07
P08
P09
P10
P11
P12
C05
C06
C07
C08
P13
P14
P15
P16
P17
P18
P19
P20
C09
C10
C11
C12
K05
K06
K07
K08
P21
P22
P23
P24

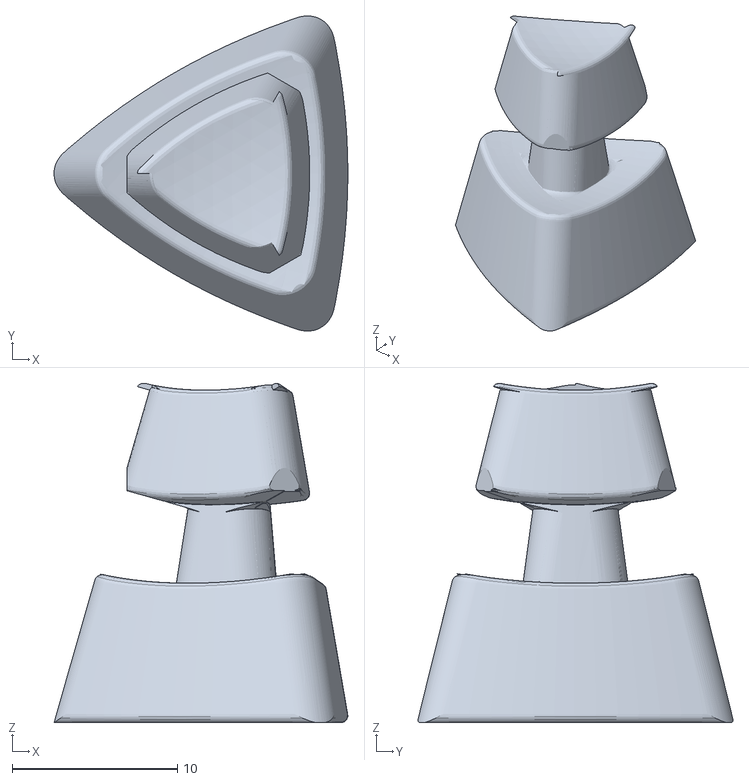
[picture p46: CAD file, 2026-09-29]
designs/curvy-copter-cuboctahedron-v3.2/source/fixed-parts/corner-print-8.stl
17.8 x 19.1 x 20.5

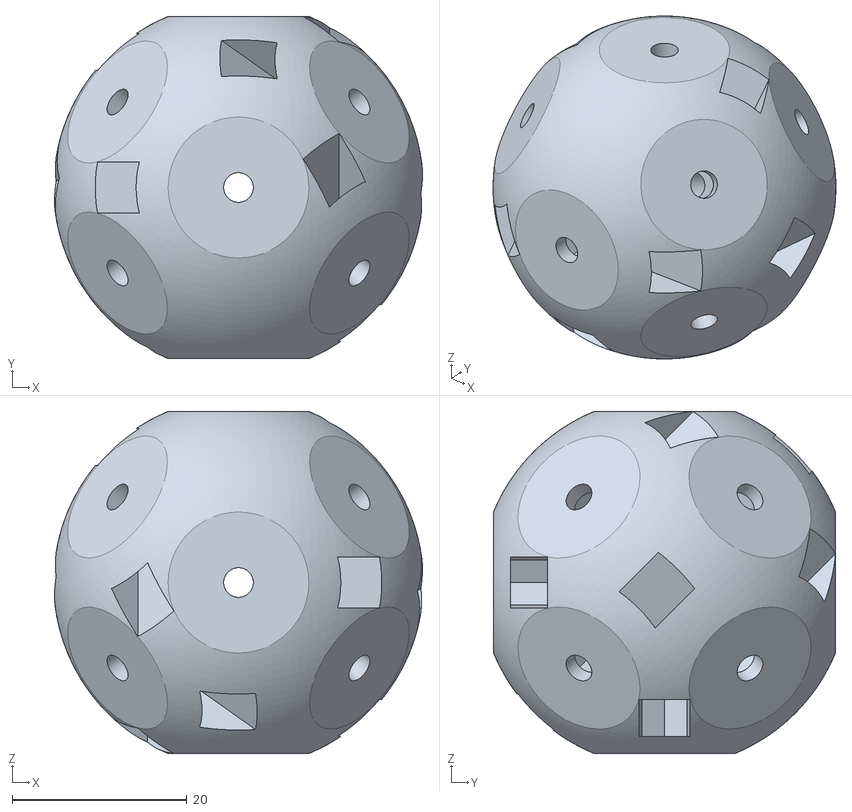
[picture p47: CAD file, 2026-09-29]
designs/curvy-copter-cuboctahedron-v3.2/stl/optional/core-seat-5.20.stl
42.2 x 39.2 x 39.2

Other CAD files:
designs/redi-v4.3/stl/optional/assembly-stand.stl
designs/curvy-copter-cuboctahedron-v3.2/stl/puzzle/core.stl
cad/baseline/calibration/fit_coupon.stl
cad/baseline/calibration/test_edge_1.stl
cad/baseline/calibration/test_edge_2.stl
cad/baseline/calibration/test_fixture.stl
cad/baseline/calibration/test_rotor.stl
cad/baseline/parts/C01.stl
cad/baseline/parts/C02.stl
cad/baseline/parts/C03.stl
cad/baseline/parts/C04.stl
cad/baseline/parts/C05.stl
cad/baseline/parts/C06.stl
cad/baseline/parts/C07.stl
cad/baseline/parts/C08.stl
cad/baseline/parts/core.stl
designs/conical-3x3-v1.1/plates/C-01.3mf
designs/conical-3x3-v1.1/plates/E-01.3mf
designs/conical-3x3-v1.1/plates/E-face-down-01.3mf
designs/conical-3x3-v1.1/plates/K-01.3mf
designs/conical-3x3-v1.1/plates/K-radial-down-01.3mf
designs/conical-3x3-v1.1/plates/alternate-cores-01.3mf
designs/conical-3x3-v1.1/plates/core-01.3mf
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

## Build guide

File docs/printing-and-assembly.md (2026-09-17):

# Printing and assembly — 80 mm v4.2.1

This guide is for the older 80 mm direct-screw version. For the latest 64 mm
locknut version, use [v4.3 assembly](../designs/redi-v4.3/ASSEMBLY.md).
The hardware and pieces are different; do not mix the sets.

Print one core, C01–C08 and E01–E12 from [models/current/parts](../models/current/parts). The [plates](../models/current/plates) arrange those parts for a 256 mm bed. `comparison_E12.3mf` is optional, not an additional required piece.

## Hardware

| Quantity | Item |
|---|---|
| 8 | M3 × 20 machine screws with flat undersides to their heads |
| 8 | Washers: 13 mm outside diameter, 0.55 mm thick; bore must pass the screw |
| 1 | Phillips driver; tubular holder no larger than the checked Ø12 envelope |

The 2.6 mm pilots grip the machine screws directly in printed plastic. There are no inserts. The corner's 3.3 mm bore must clear the screw freely; only the core should grip its thread. Use the [fit coupon](../models/current/calibration/fit_coupon.stl) if your material or hole sizing differs. It includes several pilot and clearance sizes plus a washer-well sample.

The hardware model assumes an approximately Ø6 × 3 mm screw head envelope. Check unusually large heads. The reference seat is designed around the specified washer; changing washer thickness changes axial adjustment and screw engagement. M3 × 20 gives 7.35 mm nominal engagement. Longer screws are not needed for the supplied set.

## Printing

Use **millimetres and 100% scale**. The models contain their clearances already. The 3MF files are geometry-only and carry no verified Bambu Studio settings or G-code.

The original development printer was a Bambu Lab P1S with a 0.4 mm nozzle. Use settings that have given you accurate PLA parts. If starting fresh, 0.16 mm layers, five walls, six top/bottom layers and approximately 20% infill are suggested starting settings for the outer pieces, not a tested preset. Inspect the sliced walls, washer collars and retaining overhangs, and provide removable supports where needed.

Parts are preoriented with a broad exterior face on the bed. The core sits on its C01 axle pad; its curved portions remain spherical. Keep each file's ID associated with the piece after printing. IDs are file/object names, not guaranteed embossed labels.

Remove support residue, raised seams and first-layer lips from sliding surfaces. Preserve flat retaining lands and bearing feet. Inspect the inside of the track mouths, not just the visible exterior.

PLA was the original baseline; the exact material/settings of the latest reported v4.2 print were not separately logged. To compare a geometry change, keep material, orientation and settings fixed. ABS can be evaluated with the same comparison piece and its manufacturer's printing guidance, but there is no controlled friction or turning-force comparison for this puzzle. Material-dependent dimensional change can alter fit; do not assume uniform scaling is a suitable correction.

## Full assembly

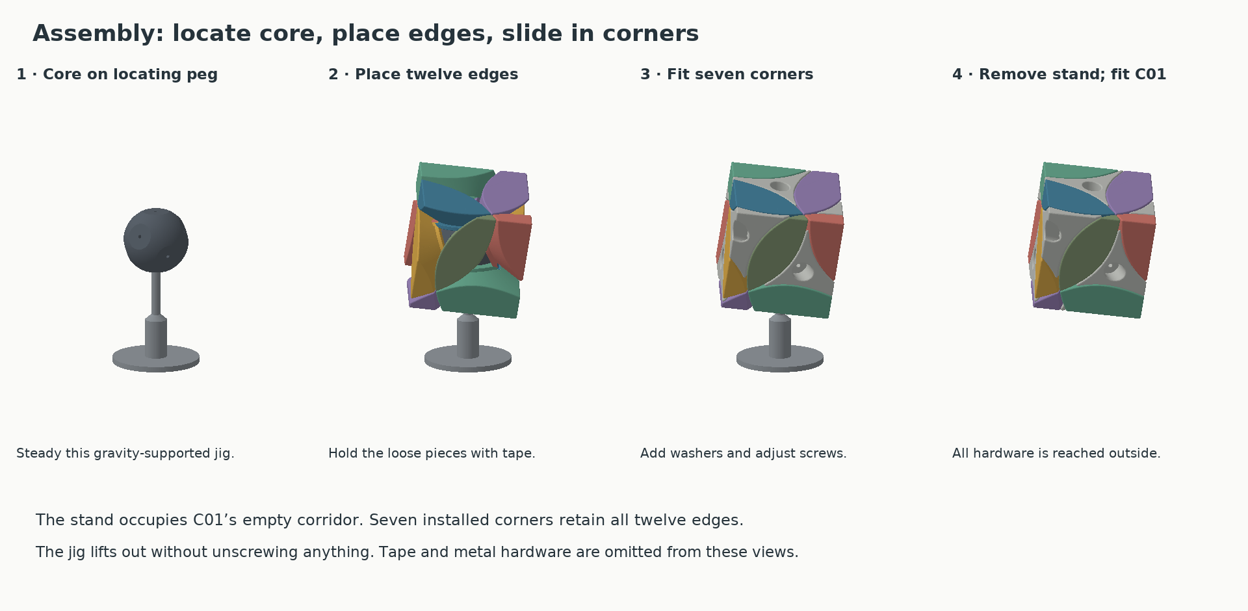
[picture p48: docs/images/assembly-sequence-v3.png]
Assembly route: edges first, corner retainers from outside, stand removed before last corner


1. Print the [assembly stand](../models/current/calibration/assembly_stand.stl). Stand the core on the C01 pad with the stand's peg in that pilot. The stand is held by gravity, not a deeply recessed fastening screw.
2. Place the twelve edges in their solved positions around the core. Use the piece map and the [assembled reference](../models/current/reference/assembled_reference_DO_NOT_PRINT.3mf). Low-tack tape or careful hand support can hold the loose shell together.
3. Slide C02–C08 inward along their individual axes. Put a washer into each access well and screw into the core through the corner. Fit each corner without clamping its rotation.
4. Support the puzzle and withdraw the stand through C01's still-empty corridor.
5. Slide in C01 and install its washer and screw. Adjust all eight corners, then check slow turns before scrambling.

All fasteners are accessible from outside. Edges go in before the retainers close their escape paths; do not force them through installed flanges. The assembled reference is for inspection only—do not print it as a fused object.

## Adjustment

Aim for roughly **0.10 mm axial freedom** at each corner, with 0.08–0.15 mm as a starting range. Gently remove play, then back off enough that the corner rotates freely. With standard 0.5 mm-pitch M3 screws, one fifth of a turn corresponds to 0.10 mm of screw travel; printed thread compliance and washer seating mean the resulting play still needs checking.

If a turn catches, inspect the contacting track/ridge and print residue before loosening all screws. Excessive lift permits wobble and can weaken retention. This design has no springs or detents.

Use a hand driver. On reassembly, let the screw find the existing plastic thread before advancing. Repeated removal can wear the pilot. A rough washer or tight bearing foot can cause drag independently of edge-track clearance.

## Piece map

Axis signs refer to the mechanism frame, not the rotated exterior faces.

| Corner | Axis signs | Adjacent edges |
|---|---|---|
| C01 | − − − | E01, E02, E05 |
| C02 | − − + | E01, E03, E06 |
| C03 | − + − | E02, E04, E07 |
| C04 | − + + | E03, E04, E08 |
| C05 | + − − | E05, E09, E10 |
| C06 | + − + | E06, E09, E11 |
| C07 | + + − | E07, E10, E12 |
| C08 | + + + | E08, E11, E12 |

## Replacing edges on an existing 80 mm puzzle

The publication revision reuses the v4/v4.1/v4.2 core, corners and hardware. Only edges need replacement. Earlier v3/v3.1 outer interfaces have compatible main dimensions, but the new wider v4 corner tracks are part of the intended smooth-turning configuration. Do not mix these parts with the old 100 mm v2 puzzle.

To try E12 first, return to the solved shape, support nearby pieces, remove C07 and C08, and withdraw the old edge outward. Install the new E12 and refit those corners. Do not pry it past their installed shoulders. A single replacement changes only some contacts, so other edges may still catch.

## Optional bench fixture

The [calibration folder](../models/current/calibration) contains seven STLs: the stand, fit coupon, fixed bowl (`test_fixture`), rotor, and three cropped edge segments. Only the last five form the mechanism fixture.

Place the three edge segments 120° apart in the bowl, insert the rotor axially, and fasten it with one washer and M3 × 20 screw. Adjust like a full-puzzle corner. Its fixed bowl is axisymmetric, so this fixture exercises one rotating track but cannot reproduce all crossing-axis interactions of the full puzzle.

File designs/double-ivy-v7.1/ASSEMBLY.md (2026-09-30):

# Assembly — F, then E, then W, then C

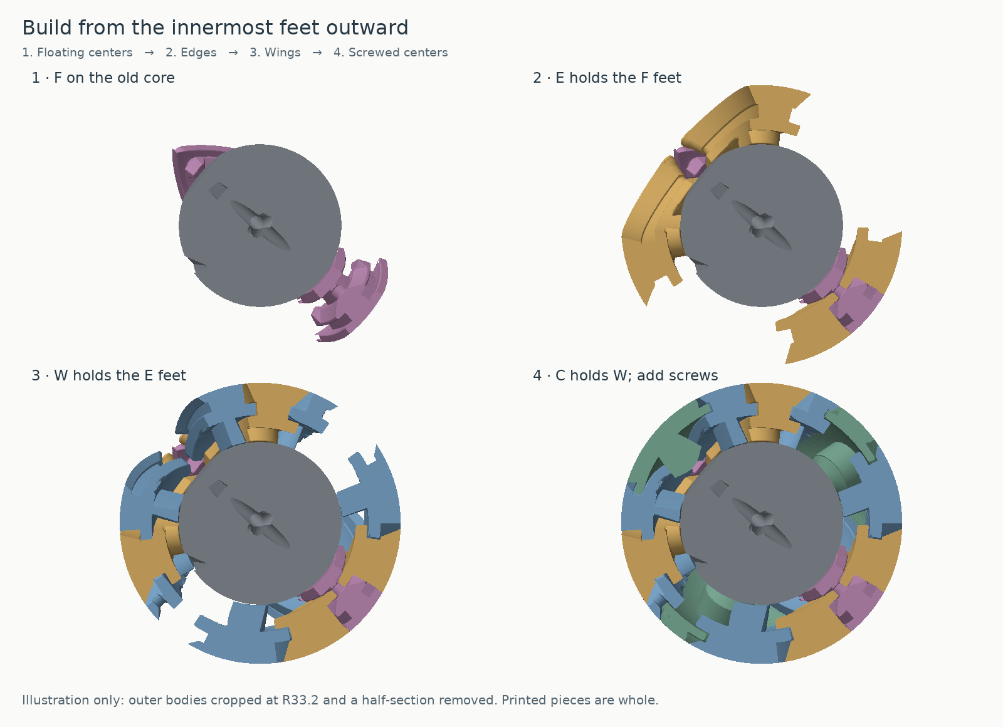
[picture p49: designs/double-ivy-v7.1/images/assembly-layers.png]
Layered mechanism


The drawings show cutaways only; all printable pieces are whole. Install four locknuts in the supplied core, or keep them installed in a compatible existing one-piece core. See [CORE.md](CORE.md) for nut orientation and fit. The partly assembled puzzle needs support from your hands or a temporary holder until the screws close the retaining chain.

1. **Place F01–F04 around the core.** Their inner spherical feet sit closest to the core. If using the original stand, attach it temporarily at the C01 position with that screw and washer.
2. **Add E01–E06.** Each edge's lower spherical shoulders go above the adjacent floating-center feet and hold them down.
3. **Add W01–W12.** Their lower shoulders go above the edge feet. These wings will be held by the higher flanges of the screwed centers. The integral E/W bearing webs nest near the spherical core without hooking into it; no separate insertion or fastening is needed.
4. **Insert and fasten C02–C04, then C01.** The flanges fit over the wing feet. Add the 9×1 mm washers and M3×20 screws, and adjust evenly. If using the stand, remove its temporary screw/washer and withdraw it before installing C01 last.
5. Test both shallow and deep 120° turns while aligned. Start with the smallest center lift that permits free motion; excess screw lift propagates through the nested supports. M3 coarse pitch is 0.5 mm per revolution, so one fifth of a turn changes nominal screw height by 0.1 mm.

The checked paths insert each piece radially while all other pieces of its family and all inner families are in place. **No edge-and-wing preassembly or 180° wing-mating maneuver is required.** The backs of the receiving grooves are opened for these insertion paths; the captured feet remain intact in that operation. Fine hand adjustment for real printed tolerances is still expected.

## Which parts hold which

| Screwed center | Wings under its flange |
|---|---|
| C01 | W01, W02, W03 |
| C02 | W04, W05, W06 |
| C03 | W07, W08, W09 |
| C04 | W10, W11, W12 |

| Edge | Wings above it | Floating centers below it |
|---|---|---|
| E01 | W01, W04 | F03, F04 |
| E02 | W02, W07 | F02, F04 |
| E03 | W03, W10 | F02, F03 |
| E04 | W05, W08 | F01, F04 |
| E05 | W06, W11 | F01, F03 |
| E06 | W09, W12 | F01, F02 |

## Complete solved-neighbor list

These are neighbors across a cut face, excluding incidental point contacts and extra transient internal contacts during a turn. IDs match the earlier double-cut Ivy.

| Piece | Neighbors |
|---|---|
| C01 | W01, W02, W03 |
| C02 | W04, W05, W06 |
| C03 | W07, W08, W09 |
| C04 | W10, W11, W12 |
| W01 | C01, E01 |
| W02 | C01, E02 |
| W03 | C01, E03 |
| W04 | C02, E01 |
| W05 | C02, E04 |
| W06 | C02, E05 |
| W07 | C03, E02 |
| W08 | C03, E04 |
| W09 | C03, E06 |
| W10 | C04, E03 |
| W11 | C04, E05 |
| W12 | C04, E06 |
| E01 | W01, W04, F03, F04 |
| E02 | W02, W07, F02, F04 |
| E03 | W03, W10, F02, F03 |
| E04 | W05, W08, F01, F04 |
| E05 | W06, W11, F01, F03 |
| E06 | W09, W12, F01, F02 |
| F01 | E04, E05, E06 |
| F02 | E02, E03, E06 |
| F03 | E01, E03, E05 |
| F04 | E01, E02, E04 |

## Inspecting the arrangement

`reference/DO-NOT-PRINT-solved.3mf` is the complete solved assembly. Import it as one multi-part object without auto-arranging to inspect placement. It is not a print plate. `reference/parts.json` records signatures and radial directions; `manifest.json` records the reversible transform for each print orientation.

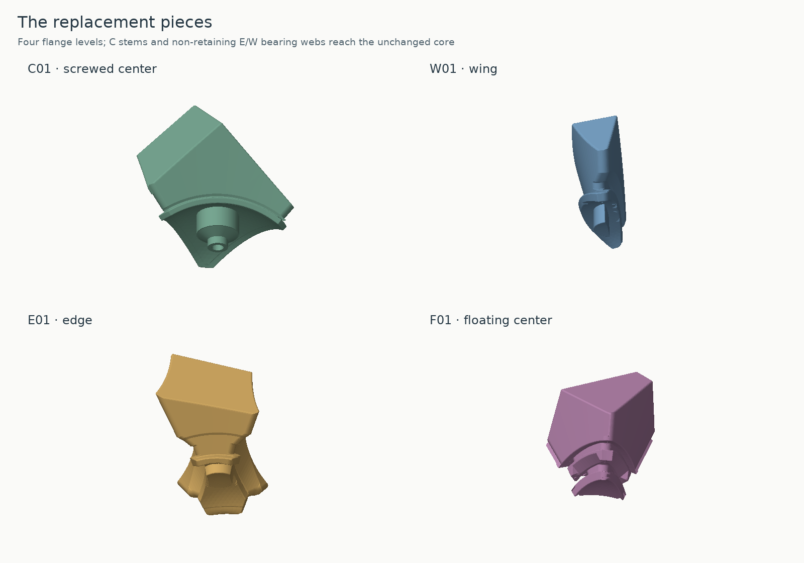
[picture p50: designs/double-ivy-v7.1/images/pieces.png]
Individual pieces


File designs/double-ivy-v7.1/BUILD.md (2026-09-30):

# Rebuild Double Ivy v7.1

The source is self-contained, including the exact original core and stand meshes. The main source scripts reproduce the v7 baseline; the two explicit finishing steps below provide v7.1. Python 3.11.15 was used. No OpenSCAD or proprietary CAD is required. The original core is copied, not regenerated or scaled.

Create a virtual environment, install `source/requirements.txt`, and run these commands from the package root. Shell variables below only control this build. Use a **new, empty build directory** whenever parameters change; the generation scripts cache expensive geometry.

```sh
python3 -m venv .venv
.venv/bin/python -m pip install -r source/requirements.txt
export OPENBLAS_NUM_THREADS=1
export IVY_BUILD_DIR="$PWD/build"
export IVY_RELEASE="$PWD/rebuilt"
export MPLCONFIGDIR="$PWD/build/matplotlib"
.venv/bin/python source/design.py
.venv/bin/python source/prepare_receivers.py
.venv/bin/python source/finish.py
.venv/bin/python source/guide_pads.py
.venv/bin/python source/export.py
.venv/bin/python source/drawings.py
```

Run the geometry and packaging checks:

```sh
.venv/bin/python source/validate.py motion
.venv/bin/python source/validate.py assembly
.venv/bin/python source/validate.py hardware
.venv/bin/python source/validate.py retention
.venv/bin/python source/validate.py midturn
.venv/bin/python source/validate.py feet
.venv/bin/python source/validate.py printability
.venv/bin/python source/guide_validation.py
.venv/bin/python source/neck_check.py
.venv/bin/python source/package_check.py
```

The baseline defaults reproduce the v7 72 mm nominal design at 144 radial segments. `design.py` defines the cut angles, three spherical retaining bands, four family floors and original hardware stack. `prepare_receivers.py` opens inward-accessible receiving grooves without cutting the captured feet. `finish.py` rounds radial ridges and the outside. `guide_pads.py` adds the non-retaining integral E/W core bearings. `export.py` emits print-oriented STLs, geometry-only named 3MF plates, a solved assembly and reversible transforms.

Do not uniformly rescale the STLs: the core and hardware dimensions must remain fixed. Parameter changes need the full set of checks again. The scripts produce geometry and numerical reports; the explanatory Markdown files are maintained separately. Mesh Boolean and simplification choices may cause small tessellation differences across platforms or library versions.

## Apply the published finishing steps

The supplied `source/rounding-correction/` contains the eight archived v7 meshes, fitting records and a deterministic geometric correction (mesh triangle order can differ). To reproduce the published C/F print shapes directly:

```sh
.venv/bin/python source/rounding-correction/regenerate.py rebuilt/stl/puzzle
```

This replaces C01–C04 and F01–F04 only. Its saved transforms match the v7 print poses. It corrects the supplied baseline; for a parametrically changed design, refit the fillets and revalidate rather than using archived parts.

The tighter compatible core and coupons are independently parametric:

```sh
IVY_CORE_RELEASE="$PWD/rebuilt-core" .venv/bin/python source/core-update/build.py
```

Use `rebuilt-core/stl/core-nut-seat-5.25.stl` as the new-build core. The 5.20 alternative and coupons are also generated. The delivered manifest contains the core transform and hashes. Keep the core geometry fixed if changing the outer size.

The baseline exporter produces v7 plate layouts and the original core reference. After the finishing steps, regenerate plates and the solved reference from the final meshes using `source/repack.py`; the supplied v7.1 manifest serves as the inventory and pose template:

```sh
.venv/bin/python source/repack.py . ../double-ivy-repacked
```

The first argument is a complete v7.1-shaped package with its manifest and final STLs. This command copies it and regenerates hashes, plate geometry, solved reference and plate maps. It is a packaging operation, not a replacement for geometry validation. To run the fresh full motion check on the delivered version:

```sh
.venv/bin/python source/validate.py motion .
```

Original v7 reports are archived separately. Physical feedback applies to the printed v7 baseline, not automatically to regenerated or modified geometry.

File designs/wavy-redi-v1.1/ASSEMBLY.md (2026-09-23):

# Assembly and piece map

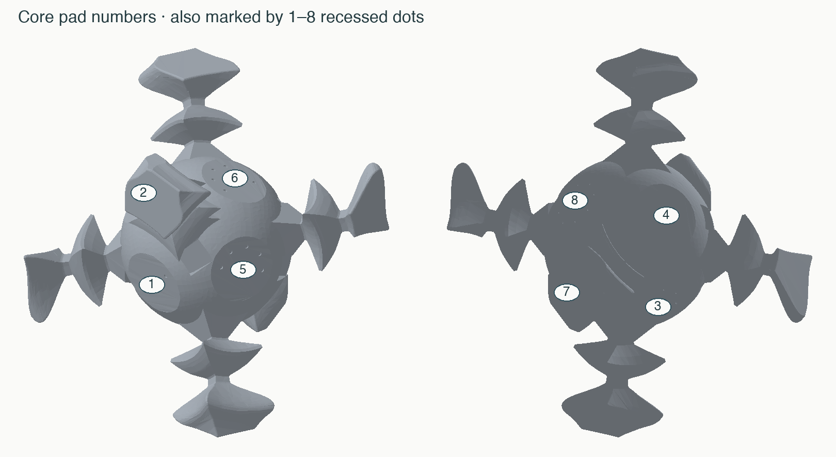
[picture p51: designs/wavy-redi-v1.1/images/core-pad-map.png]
Core identification


Press all eight nuts into the bare core first, nylon ends inward. The
recessed dot count on each flat screw pad gives its C number: one dot is
C01, eight dots is C08. Count before the pieces cover the marks. Test the
screws in the nuts, then remove them for loading the printed pieces.

## Insert these groups in this order

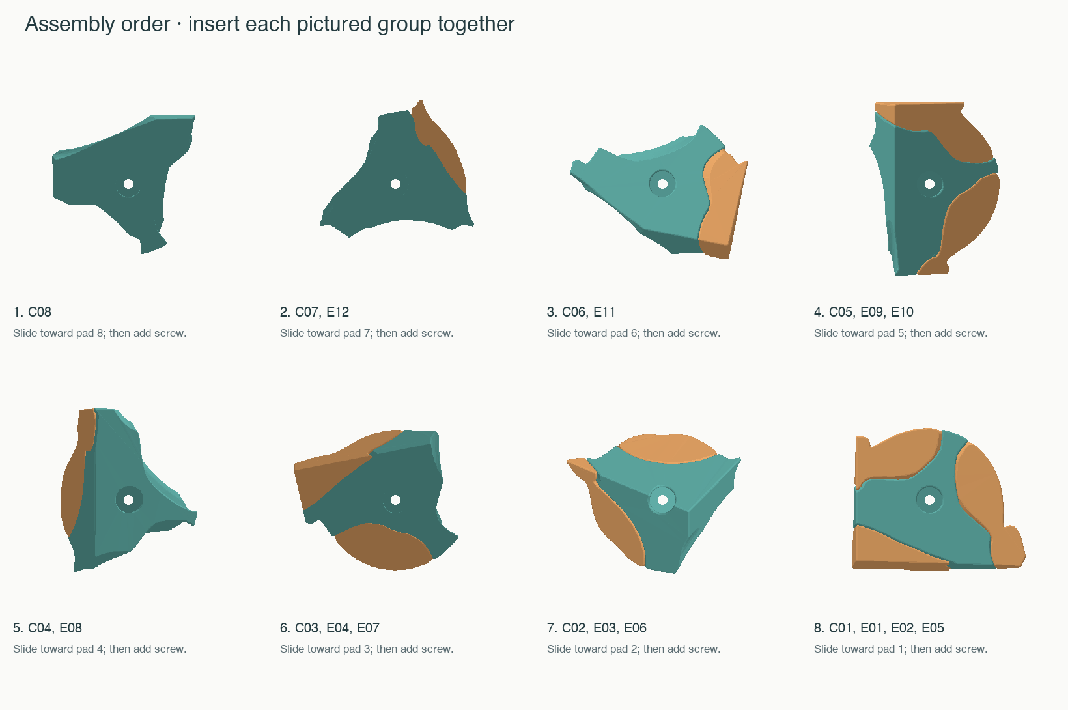
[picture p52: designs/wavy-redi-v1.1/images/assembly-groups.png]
Group sequence


| Step | Group to hold together | Screw into core pad |
|---|---|---|
| 1 | C08 | 8 dots (C08) |
| 2 | C07, E12 | 7 dots (C07) |
| 3 | C06, E11 | 6 dots (C06) |
| 4 | C05, E09, E10 | 5 dots (C05) |
| 5 | C04, E08 | 4 dots (C04) |
| 6 | C03, E04, E07 | 3 dots (C03) |
| 7 | C02, E03, E06 | 2 dots (C02) |
| 8 | C01, E01, E02, E05 | 1 dots (C01) |

For each step, hold the listed petals in their solved positions against the
listed axial piece. Slide **the entire group together** inward along that
piece's screw axis; then install its washer and screw. Use the solved
reference model and piece map to identify each petal's orientation. A little
low-tack tape across matching exterior faces can temporarily hold a group
together. Remove it after the screw is installed.

Keep each completed group in its solved position during the remaining steps.
Do not turn the puzzle before all eight groups are installed. The final
group has three petals and needs the most care. Do not insert those petals
separately and then force C01 between them: the outer wave blocks that path.

Tighten gently to remove play, then adjust each screw in small increments
until turns are comfortable. Do not torque the plastic hard against the
core. With a 0.5 mm thread pitch, one fifth turn changes the head position
by 0.10 mm. Nyloc nuts resist rotation of the screws during play, but the
nut seats must remain fully seated and must not spin.

Disassembly is the exact reverse order: first remove the C01 screw, then
withdraw C01, E01, E02 and E05 **as a group**. Continue up the table backward.

## Neighbors

Each E petal belongs between the two listed screwed pieces. Every C has
three E neighbors. IDs refer to solved locations, not colors.

| Petal | Neighboring axial pieces |
|---|---|
| E01 | C01, C02 |
| E02 | C01, C03 |
| E03 | C02, C04 |
| E04 | C03, C04 |
| E05 | C01, C05 |
| E06 | C02, C06 |
| E07 | C03, C07 |
| E08 | C04, C08 |
| E09 | C05, C06 |
| E10 | C05, C07 |
| E11 | C06, C08 |
| E12 | C07, C08 |

| Axial piece | Neighboring petals |
|---|---|
| C01 | E01, E02, E05 |
| C02 | E01, E03, E06 |
| C03 | E02, E04, E07 |
| C04 | E03, E04, E08 |
| C05 | E05, E09, E10 |
| C06 | E06, E09, E11 |
| C07 | E07, E10, E12 |
| C08 | E08, E11, E12 |

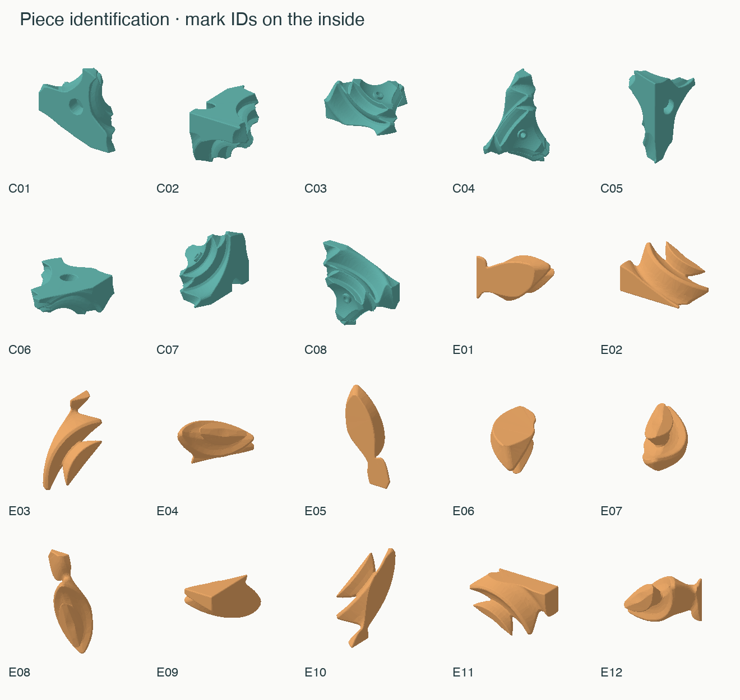
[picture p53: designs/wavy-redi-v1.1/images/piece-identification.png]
Piece identification


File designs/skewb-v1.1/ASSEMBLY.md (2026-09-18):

# Printing, assembly and adjustment

## Fit coupons first

Print the three labeled nut-fit blocks (5.30, 5.40, 5.50 mm) and `rotor-fit`.
The label is in the filename/plate map, not engraved in a bearing surface. Mark
it immediately after removing it from the plate.

1. Slide a nut into a coupon's wide side entrance, metal bearing face toward the
   screw and nylon end toward the puzzle center. Press it fully into the narrowed
   seat with a blunt rod, keeping its bore aligned. Do not use the screw to pull a
   sideways nut into position.
2. Place the rotor coupon over the bore, drop in a 9 × 1 mm washer, and insert an
   M3 × 20 screw. Drive it through the nut's nylon ring and back it out several
   times. The nut must not turn in the pocket.
3. Choose the tightest fit that seats fully without splitting the plastic and
   passes the screw test. Default core: 5.40 mm. Alternatives: 5.30 and 5.50 mm.
   A nominal dimension is not a guarantee of fit for a particular nut or print.

Coupons check the hardware and flat bearing, not the complete puzzle. Their
orientation does not reproduce every tilted slot in the core. Check each of the
four core seats before enclosing the core. Test screws should be removed before
loading the floating pieces.

## P1S, 0.4 mm nozzle, PLA

Use your successful PLA settings as the baseline. A reasonable starting point
is 0.16 mm layers, four walls and 15–20% infill, keeping the small retainers solid
where practical. These are starting settings, not a validated slicer profile.
Keep the scale at 100%; scaling changes both hardware fit and running clearance.

- C01–C04 are placed on a broad exterior face. The core rests on the existing
  C01 bearing flat; no extra spherical portion was flattened for printing.
- The default F/K STLs are inward-radial-down. At 0.16 mm above the model's
  lowest point, an F piece has only about 0.6 mm² of section and a trimmed K piece about
  0.79 mm². **Do not rely on these tips alone for bed adhesion.** Inspect supports
  beneath the feet and a raft/brim strategy in your slicer before printing.
- The face-down 3MF alternatives offer broad bed contact. Use the F-face-down
  and K-face-down plates, or individual files in `print-options`. They preserve
  the same meshes under rigid rotation. Choose either these or the default
  inward-down versions, never two copies of the same ID.
- Inspect supports for undercuts in either orientation. Keep unwanted support
  out of nut slots and screw bores. Remove support scars and elephant foot from
  the rails, flat bearing lands and closely spaced main faces.

Use a clearance drill or careful deburring if a screw rubs inside a rotating
C piece. It must turn around the screw rather than grip its threads. Keep the
washer land flat and free of support debris.

Mark every full piece ID on a sheltered inside patch, away from sliding surfaces.
The [neighbor sheet](NEIGHBORS.md), [identification image](images/piece-identification.png)
and named solved 3MF identify placement. IDs belong to solved positions, not the
outer cube's visible geometric corners. The bed flat of the core is C01; use
[core-identification.png](images/core-identification.png) to match the other axes.

## Put the whole pieces together

The order is **K pieces → F pieces → screwed C pieces**. Each piece has a checked
straight insertion route along its radial direction; no retainer needs to snap
through another part. Loose parts need temporary external support during assembly.

1. Install and torque-test all four nuts in the core, then remove the test screws.
2. Optionally attach the stand at C01 using one washer and one screw. It supports
   the core, not the loose shell. A bare hex key with about 80 mm straight reach
   reaches the stand's screw. Place the stand's base on the table.
3. Position K01–K04 around the core in the solved orientations. Use your hands,
   low-tack tape on the outside, or other temporary external support.
4. Slide F01–F06 radially inward around them. The F feet capture the K feet.
   Check the solved seams against the named 3MF before adding screws.
5. Slide C02–C04 radially inward. Drop one washer into each access well and fit
   its screw into the captive nut. Leave the bearing released for adjustment.
6. Support the shell, remove the stand's screw/washer, and withdraw the stand
   straight outward along C01. Install C01, its washer and screw. Without the
   stand, simply install all four C pieces after the K and F pieces.
7. Remove temporary tape/supports. Check complete 120° turns about each of the
   four C axes while the other seams are aligned, then try mixed turns gently.

This order is intentionally reversible. For disassembly, remove the C pieces,
then F pieces, then K pieces. Hardware is standard; there is no glue, snap-through
assembly step, or permanently trapped extra plastic piece.

## Adjust the four axes

Bring a screw only to gentle bearing contact, judging resistance at the rotating
piece. Nyloc torque begins before the corner is clamped, so screw-driver torque
alone is not an indication of bearing contact. Start by backing off approximately
one fifth of a turn: M3 coarse pitch is 0.5 mm, so 72° corresponds to 0.10 mm of
axial head motion. Then tune in smaller increments.

The nominal bearing foot is 0.10 mm above its core flat in the assembly model.
The 0.03 mm main-face gap reduces slack, while the wider internal tracks retain
running clearance. Tightening the screws does not eliminate all floating-piece
play. The geometry is not a calibrated spring mechanism, and exact frictional
binding/release cannot be guaranteed from screw angle alone.

If a turn catches, first align the seams and look for burrs, support scars or a
rubbing bore. Do not force a jam or overtighten against PLA. The owner reports
successful printing and nice turning of the trimmed v1.1. Check hardware fit on
your own print; neither that report nor the geometry checks establish a measured
holding force, installation-torque rating or wear life.

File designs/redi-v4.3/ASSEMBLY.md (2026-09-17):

# Printing and assembling the compact Redi

## Hardware fit first

1. Print the three nut-fit blocks and the rotor coupon. Choose the tightest
   5.50 / 5.60 / 5.70 mm pocket that seats your nut fully without splitting PLA.
   Use the matching core; the default is 5.60 mm.
2. Insert a nut sideways under the coupon roof. Its metal bearing face points
   toward the screw; the nylon end points inward, toward the puzzle center.
3. Place the rotor over it, add a 9 × 1 mm washer, then fit an M3 × 20 screw.
   Check the washer sits flat and the rotor turns after a small screw backoff.

Drive the screw far enough to engage the nylon ring while watching the nut.
The nut must stay fixed while the screw advances and backs out. A nut that merely
stays in place during handling has not passed this torque check. Try several nuts;
one successful slot does not establish the fit of all eight differently oriented
slots in the core. These coupons check hardware and the bearing, not the whole
flange mechanism, and their print orientation does not reproduce every core slot.

## P1S / 0.4 mm nozzle / PLA

Start with 0.16 mm layers, four walls, and approximately 15–20% infill. These are
starting settings, not a tested Bambu profile. Use enough walls at the small
flanges to fill them solidly where practical. Keep the model at 100% scale.

E01–E12 are oriented with their inward radial vector pointing straight down
(−Z): the retaining feet face the bed and the outside shell is above them. Each
STL already has its lowest point at Z = 0; keep this orientation when importing
it rather than using automatic lay-on-face. C pieces retain their outside-face
print orientation, and the core remains on one axis flat. Use supports and a
brim as needed for your usual edge-printing setup.

Inspect support in the slicer and keep it out of the screw bores and nut slots.
Clean support scars and elephant foot, especially on bearing feet, flange rims,
and the closely spaced main faces. Deburr a tight clearance bore instead of
letting a screw cut threads into the rotating C piece.

Write each full ID, such as **E01**, on a sheltered inside patch with a Sharpie,
away from sliding and bearing surfaces. Use [NEIGHBORS.md](NEIGHBORS.md), the
plate maps, and `images/piece-identification.png`. The named assembled 3MF shows
the solved orientation. IDs are not engraved into the running surfaces.

## Nut loading

Press all eight nuts sideways into the core's open slots until their screw holes
line up with the core bores. The roofs stop outward extraction; the hexagonal
seats are intended to resist rotation and the small ribs aid handling retention.
The nylon ends face the puzzle center. Test each nut with a screw, then remove
those screws before positioning the exterior pieces.

**Known issue:** the owner reports that about half the installed nuts spin under
the screw's locking torque. Check every seat before enclosing the core. Do not
keep driving a screw against a spinning nut: it can wear the pocket further.
The planned core-only revision will keep the entrance easy to load and narrow
the final seat for a press fit using a blunt metal rod. It is **not included** in
this release; see [README.md](README.md#known-core-issue-nuts-can-spin).

Use a bare 2.5 mm hex key long enough to reach the heads. An approximately 80 mm
straight reach also accommodates the optional stand. The narrow access wells
are intended for the hex key, not the large tubular Phillips-bit holder used
on the earliest proof of concept.

## Whole-piece assembly

The order is **edges first, C pieces last**, the same assembly principle as
v4.2. Each C piece slides inward along its screw axis; no flange has to snap
through a closed retainer.

1. Support the core. Optionally screw the supplied stand onto the C01 axis with
   one washer and screw and place its base on the table.
2. Arrange E01–E12 around the core in their solved positions. Use your hands,
   removable low-tack tape on the outside faces, and temporary external support
   as needed. Floating edges will not stand in place unaided.
3. Slide C02–C08 into their positions. Drop one washer into each access well,
   then install its screw into the captive nut. Leave each bearing released.
4. Support the puzzle, remove the stand's screw and washer, and withdraw the
   stand straight outward along C01. Insert C01, then install its washer and
   screw. Without the stand, simply install all eight C pieces last.
5. Remove tape and external supports. Test all eight axes gently before
   scrambling. If a turn catches, inspect alignment and print burrs first.

The stand supports the core, not the loose edges. The provided assembly checks
include stand withdrawal and edge loading around it.

## Tune

Bring each screw to gentle bearing contact. Judge contact by resistance of the
rotating piece, since the nylon nut resists the screw before the bearing clamps.
Back off by approximately one fifth turn, then tune in smaller increments.
Do not crank a screw down against PLA. Track clearance remains even with the
bearing clamped; see [VALIDATION.md](VALIDATION.md) for measured pull travel.

The owner has built this revision and likes its feel apart from the nut seats.
Long-term wear, PLA settling, and measured torque remain uncharacterized.

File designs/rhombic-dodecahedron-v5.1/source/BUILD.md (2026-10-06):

# Regeneration

Python 3.11 with `requirements.txt` is the reference environment. Use a **new build directory** after changing geometry or resolution; fillets and bare solids are cached within a build.

```sh
python3.11 -m venv .venv
.venv/bin/pip install -r source/requirements.txt
export OPENBLAS_NUM_THREADS=1
export FC_BUILD_DIR="$PWD/build-new"
export FC_RELEASE="$PWD/output/rhombic-dodecahedron-76mm-v5.1-exact-inlays"
export ODA_FILE_CONVERTER="/path/to/ODAFileConverter"
export DWG_TOOL_DIR="/path/to/libredwg/programs"
.venv/bin/python source/build.py
```

`ODA_FILE_CONVERTER` names the official converter executable, inside `ODAFileConverter.app/Contents/MacOS/` on macOS. `DWG_TOOL_DIR` contains GNU LibreDWG's `dwg2dxf`. The reference conversion uses ODA 27.9 and independent reading with LibreDWG 0.14. These external tools are not distributed in this MIT package; obtain them under their own licenses. ODA's macOS command-line runtime needs desktop services.

The pipeline generates the mechanism and fillets, closes screw wells above the screw heads, cuts the foam pockets, splits only the central screw region into a main piece and keyed plug, exports STL/3MF and key samples, checks meshes/motion/assembly/foam/plugs, makes cutting sheets, renders, converts and independently verifies DWGs, writes documentation and hashes, and packages the ZIP. Failed checks prevent packaging.

The order matters: `finish.py`, `caps.py --prepare`, `inlays.py`, `caps.py`, `export.py`. Preparation reads the finished mechanical solids once; do not rerun it over already split centers. Pocket generation saves separate `pocketed-*` caches so `caps.py` splitting is repeatable without destroying its input. Export precedes all checks so those checks use delivered meshes.

To work without the converters, run through `cutting.py` and `render.py` individually; that produces printable parts and DXF/SVG files, not the complete DWG-verified release.

## Controls

- `design.py`: 38 mm rhombic face distance from origin (76 mm opposite faces), concentric retaining shell radii 28.5/33.5 mm, hidden necks 6° narrower than the exterior cones, body gap 0.06 mm and track-cutter expansion 0.37 mm, core, hardware and symmetry. Internal dimensions are fixed rather than scaled with the exterior.
- `caps.py`: simple rounded triangle/square plugs, female across flats 8 mm, triangle/square corner radii 2.25/1 mm, male clearance 0.12 mm per side, tapered ribs protruding 0.04 mm beyond socket flats. T/S flat plug bottoms lie at 36.6/40 mm along their axes. The keyed column alone is split from the pocketed center; the outside rim and most of the floor remain part of the main piece. There are no carrier skirts, outer cup sockets, support spokes or rim pry notches. Foam intentionally spans both parts and is removed before extracting the plug.
- `inlays.py`: 2 mm foam, 2.1 mm recess depth, nominal 1 mm rim, 1.2 mm floor envelope before splitting, 1.6 mm between adjacent-face pockets, 0.775 mm verified lateral envelope, standard +0.04 mm foam contour offset. Center patterns repeat with exact turn symmetry. Shared backing is checked after splitting, allowing only the narrow fit joint to interrupt the pocket floor.
- `printable_inlays.py`: 2 mm rigid inserts from the pocket contours at exact nominal pocket size (zero contour offset); twelve eight-piece STL/3MF face layouts, 96 individual STLs, map, and exported-mesh fit/insertion/contour checks. Run after `cutting.py`; the moving puzzle solids and foam cutting files remain unchanged.
- `cutting.py`: R13 closed POLYLINE DXF, R2000 DWG source, 1:1 SVG, three foam fits, face map and DWG read-back comparison.
- `finish.py` / `ridge_rounding.py` / `flange_rounding.py`: mild edge softening, full R2 petal radial fillets fitted against an unclipped reference, and R1.2 center-flange outline fillets swept radially. No straight-in assembly relief cuts remove spherical shoulders.
- `spherical_report.py`: actual STL bearing-face measurements and inner-foot capture against screwed centers alone.
- `checks.py`: collision-free placement into an expanded shell followed by coordinated contraction, with centers unscrewed. Keep the shell loose until all pieces are engaged; do not assume a last center can enter a tightly fastened puzzle.
- `retention_drawing.py`: true mesh sections through both retaining interfaces.
- `validate_rigid_inlays.py`: all fourteen axes with actual rigid inlays at flush height, plus the coordinated assembly path.
- `validate.py`, `validate_inlays.py`, `validate_caps.py`: checks and their explicit limits.
- `cap_coupons.py`: local key-fit samples using the same profiles and ribs.

All lengths are millimetres. Print transforms appear in the manifest. Do not resize STLs to alter the puzzle size: screw bores, nut slots, washers, track gaps, plug fits and foam thickness must retain their absolute dimensions.

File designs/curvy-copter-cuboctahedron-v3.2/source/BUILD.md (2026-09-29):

# Regenerate spherical v3.2

Use Python 3.11 and `requirements.txt`. OpenSCAD is not used. Choose fresh build and release directories after changing geometry or resolution: finishing caches are parameter-specific.

```sh
python3 -m venv .venv
.venv/bin/pip install -r requirements.txt
CUBOCTA_BUILD_DIR="$PWD/build" CUBOCTA_RELEASE="$PWD/release" OPENBLAS_NUM_THREADS=1 .venv/bin/python build.py
```

Default `CUBOCTA_SEG=144` is the delivered resolution. The two spherical steps use 0.25° meridian samples. CAD and numerical reports are generated; README and design notes are authored separately.

- `design.py`: 72 mm body, R28.5/R33.5 spherical collar, 40° hidden neck / 45° exterior cuts. Petal membership cuts have an additional 0.10 mm inward offset at each track wall, blended back to the original exterior gap. No insertion sweep is subtracted.
- `ridge_rounding.py`: R2 radial fillets. Petal fits at radial stations >= 35 mm use an unclipped reference solid so the fillet is not diverted by the outer face.
- `flange_rounding.py`: R1.2 outline fillets swept radially through the four corners of the two center flange ends. Each uses the actual intersection of two hidden 40-degree cones to define its radial direction and an extended conical reference to fit the transverse circle. The v3.1 additional whole-body ball opening is removed; original small-edge rounding remains. Final meshes are simplified to 0.005 mm tolerance.
- `finish.py`, `tip_trim.py`: original small-edge rounding, corner spine and three tiny corner-tip cuts.
- `fixed-parts/corner-print-8.stl`: exact successful spherical-v3 corner master. The exporter checks the independently regenerated corner against it, then copies this STL unchanged. Changing shell radii or size requires regenerating that master; the exporter deliberately rejects such silent mixing.
- `hardware.py`: unchanged core, bearing foot, washer seat and M3×20 / 9×1 washer / DIN985 interfaces.
- `export.py`: watertight STLs, quantities and full-set 3MF plates.
- `validate.py`: final-mesh sweeps, nut loading and layer connectivity. The numerical assembly flag remains unvalidated: a complete insertion path was not computed. The owner subsequently assembled the supplied v3.2 files successfully; see [physical feedback](../physical-feedback.json).
- `retention_v2.py`, `nominal_capture.py`, `rocking.py`: shared test implementation adapted to spherical feet; only material below R28.5 is credited for capture. Supporting petals are moved outward 0.8 mm in the corner sensitivity tests.
- `stress_jumbling.py`: 48-step legal jumbling walk with retention checkpoints.
- `structure.py`, `neck_web.py`, `spherical_report.py`: hardware/neck dimensions and remaining spherical bearing faces.
- `render.py`, `illustrate.py`, `test_patch.py`: drawings, seven-piece full test and six-piece upgrade test.
- `package_audit.py`, `supplements.py`: plate counts and bounds, exact STL reuse, hardware, neighbors and summary.

Optional `revision_check.py` and `revision_render.py` compare the result with the original spherical-v3 package. Set `CUBOCTA_V3_REFERENCE` to that package directory. Also set `CUBOCTA_V31_REFERENCE` to the accepted v3.1 package. They verify byte-identical P/K/core reuse, measure all four radial outline fillets at three depths, and compare restored material with the original v3 center. `compatibility.py` can additionally check the original 64 mm core using `CUBOCTA_V1_REFERENCE`.

A clean rebuild runs all motion/retention checks. Do not reuse the v3.1 retention results through `CUBOCTA_RETENTION_BASELINE`: C has changed.

The original numerical summaries and their generator retain the pre-print status from the CAD-validation stage. The publication adds [VALIDATION.md](../VALIDATION.md) and physical feedback separately; a changed rebuild does not inherit the supplied files’ physical result.

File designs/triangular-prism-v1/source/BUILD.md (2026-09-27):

# Build and validate the 64 mm conical triangular prism

Python 3.11 with the pinned packages in `requirements.txt`. Generated coordinates are millimetres. The saved cube rotation and all hardware dimensions are in `conical_design.py` and `chosen_rotation.json`.

From this source directory, with a fresh build directory:

```sh
export CONICAL_BUILD_DIR=/tmp/wonky-triangular-build
export MPLCONFIGDIR=/tmp/wonky-triangular-matplotlib
python build.py
python export_conical.py ../regenerated
python validate_conical.py hardware ../regenerated
python validate_conical.py assembly ../regenerated
python validate_conical.py motion ../regenerated
python validate_conical.py retention ../regenerated
python validate_conical.py plates ../regenerated
python check_structure.py ../regenerated
python check_ridges.py ../regenerated
python check_export_fidelity.py ../regenerated
python check_midturn_capture.py ../regenerated
python check_corner_capture.py ../regenerated
python check_printability.py ../regenerated
python render_conical.py ../regenerated
python render_mechanism.py ../regenerated
python write_tri_docs.py ../regenerated
python summarize_validation.py ../regenerated
```

Use a fresh build directory after modifying geometry: ridge and final-part caches are reusable checkpoints, not parameter-aware caches. Production uses 240 revolution segments; `CONICAL_SEGMENTS` can lower this for exploratory builds. The shoulder dimensions are designed for 70°, not an arbitrary-angle parameterization.

Exterior finishing defaults to three worker processes. `CONICAL_FINISH_WORKERS=1` limits memory use. Keep generated renderings and reports with the matching export manifest; never transfer physical validation from a different puzzle or STL version.

The documentation generators attach the physical build report only when all puzzle STL hashes match the supplied files associated with that report. Regenerated or modified meshes require their own physical test.

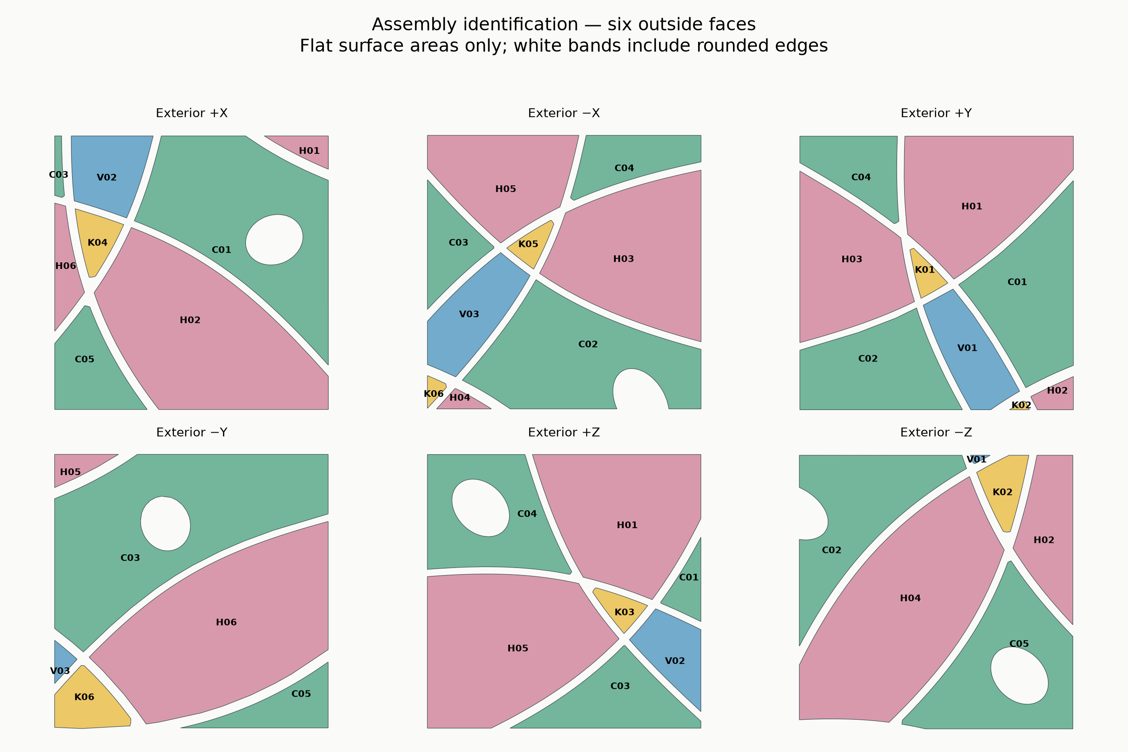
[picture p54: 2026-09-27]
designs/triangular-prism-v1/images/assembly-map.png

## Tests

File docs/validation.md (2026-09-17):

# Validation and provenance — 80 mm v4.2.1

This report describes the older 80 mm set. The compact release has its own
[v4.3 validation and physical feedback](../designs/redi-v4.3/VALIDATION.md).

The **v4.2.1 publication export passes all four geometry reports**, plus an independent repeat-build comparison. These results apply to the files identified by [SHA256SUMS.txt](../models/current/SHA256SUMS.txt).

## Physical evidence and version identity

The owner built and iterated full puzzles on a Bambu Lab P1S with a 0.4 mm nozzle. PLA was the original material baseline. On 2026-09-14 the owner confirmed using the **v4.2 / 3 mm** files and reported that the print worked very well. The exact latest material/profile and the file hashes sent to the printer were not recorded.

During publication, the saved v4.2 folder was found to contain exports from different generation attempts: individual E01–E03 STLs had been updated, while other STLs, arranged plates and the assembly arrays still reflected an earlier attempt. That does not invalidate the owner's physical report, but it prevents attributing that report to one completely identified file set. The available files are preserved in the [historical snapshot](../history/README.md) and historical release assets.

V4.2.1 is a fresh, internally consistent export of the constant-3-mm intent, including the corrected inner track profile. It preserves the same core, corners, hardware, exterior face planes and print transforms. **This exact publication export has not independently been reported printed.** There is no need to replace a satisfactory existing print solely to match this release number.

## Digital checks on the publication set

| Check | Result |
|---|---|
| Saved puzzle and fixture/jig STLs | 28/28 closed, connected, consistently wound, positive-volume meshes |
| Aligned outer parts and hardware | No overlap detected |
| Eight complete 120° turn paths | 25 samples per axis, pass |
| Smallest sampled outer-part gap | 0.1860 mm |
| All corner and edge insertion routes | Clear along the specified sampled paths |
| Washer and driver access | All eight axes pass, including a Ø12 mm holder envelope |
| Stand withdrawal before C01 installation | Pass |
| Bearing annuli, washer seats and collars | Pass |
| Optional one-axis fixture | 360° sampled in 5° steps, pass |
| Arranged plates | All six within the 256 mm build area |
| One new E12 among v4.1 parts | All eight axes at 13 angles each pass |
| Edge radial retention | All twelve encounter both adjacent retainers |
| Detailed E12 extraction probes | 18/18 principal pulls blocked; 0 escapes among 60 specified rocking paths |
| Core and corners | Nine print STLs byte-identical to the supplied baseline |
| Repeat build from public source/baseline | All 28 STL bytes and all six decompressed 3MF payloads match |

The flat bearing foot intentionally touches the core pad. The verifier allows a small numerical coplanarity volume there (less than 0.01 mm³) only if a 0.005 mm lift clears it. Outer-part and hardware intersection checks use a separate 0.00001 mm³ threshold. Thread engagement in the plastic pilot is intentional and is evaluated separately from rotating-part collisions.

The detailed extraction audit includes corner lifts of 0, 0.10 and 0.25 mm and rocking up to ±10°. This is evidence of geometric obstruction along those paths, not a force rating or a search over every six-degree-of-freedom escape route.

## The actual 3 mm radius

The print STLs are transformed back into mechanism coordinates before measurement. Both radial ridges of all twelve edges are checked at 80 stations: every 0.125 mm from 24.5 through 34 mm in the inner track, plus outer stations at 35.5, 37.5 and 40 mm. Each fit uses 41 points across the central 80% of the exposed arc.

Across **1,920 sections**, fitted radii range from **2.99215 to 3.00474 mm**. The maximum sampled departure from the specified 3 mm circle is **0.001416 mm**. Acceptance thresholds are ±0.06 mm in fitted radius and 0.015 mm in circle departure. The construction uses a fixed transverse radius along the ridge; the section samples check the mesh approximation, rather than proving every surface point analytically.

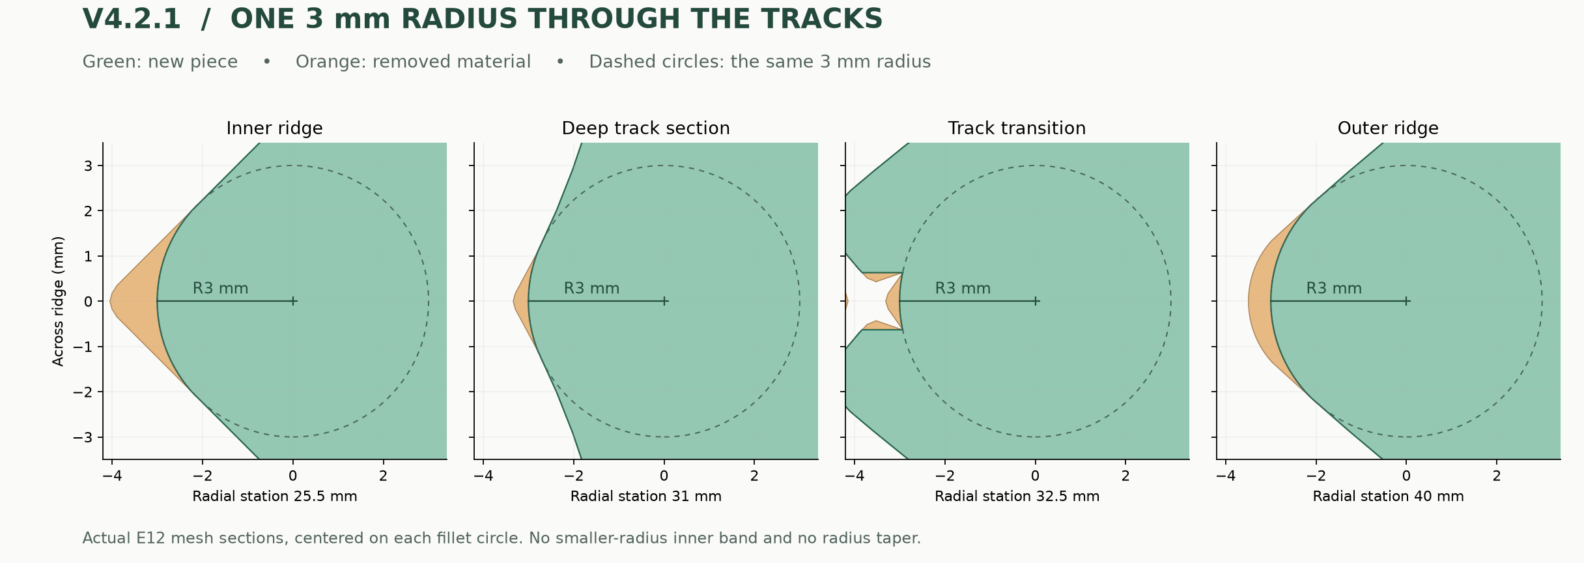
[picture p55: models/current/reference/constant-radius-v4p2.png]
Actual constant-radius sections


Some tiny Boolean arcs collapsed into collinear slits during float32 STL conversion. The exporter collapses only closed boundary loops at most 0.002 mm long and within 0.000001 mm of a line, then requires a closed, consistently wound mesh. It does not fill arbitrary holes. This preserves the transverse profile more accurately than broadly simplifying the steep track region. [v3_io.py](../cad/v3_io.py) contains the bounds and checks.

## Misalignment and shape distinction

A separate probe holds C07 at ±0.5°, ±1° or ±2° and moves C08 through those same six values. Across 36 rigid poses, summed moving/static overlap decreases from **7.856184 to 0.052492 mm³** relative to v4.1. This is a geometric interference comparison. It is not a measured torque reduction or a physical corner-cutting angle: the model does not simulate compliant motion, friction or cam-driven realignment.

All **66 edge pairs** remain distinct across **1877 common radial directions** in the two compatible proper mounting orientations. The smallest pairwise RMS radial difference is **3.7806 mm**. Reflections remain distinct. The exterior rotation was retained, not reoptimized.

## Reports and limitations

- [Mechanism, mesh, hardware and assembly report](../models/current/reference/verification.json)
- [Revision, mixed-version motion and retention report](../models/current/reference/ridge_revision_check.json)
- [Actual STL radius report](../models/current/reference/radius_check.json)
- [Edge-shape comparison](../models/current/reference/edge_shape_check.json)
- [Independent repeat-build comparison](../models/current/reference/reproduction_check.json)

Finite turn samples are not a continuous collision proof. The checks omit layer texture, support scars, friction, creep, wear, thread stripping and elastic deformation. The physical success report is useful evidence of the design family; it does not measure lifetime, load capacity or the effect of every parameter independently. Instructions and settings remain practical starting points rather than a certified printer profile.

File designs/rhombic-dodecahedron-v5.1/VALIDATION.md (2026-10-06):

# Physical build and geometry checks

The owner reports that the complete puzzle **printed and built very well, and turns smoothly**. The published main-piece, petal, plug and core STLs are byte-identical to that supplied build. The [physical-feedback record](physical-feedback.json) distinguishes this direct build report from the CAD checks and lists the associated hashes.

The owner printed the rigid inlays both at the supplied reduced size and with **+0.15 mm contour compensation** cancelling the reduction. The compensated inserts fit **very nicely snugly**; the reduced ones were noticeably less satisfactory. The published inserts therefore use the **exact original pocket contours**, with zero contour offset and 2 mm thickness. Print them with **0.00 mm XY contour compensation**. The exact regenerated toolpaths were not separately reprinted; their nominal fit is supported by that physical comparison.

## What was checked

- The main puzzle has 53 printed parts including the core and fourteen keyed plugs, forming 38 moving units. All delivered individual STLs are closed and connected. Each face-inlay STL deliberately contains eight separate closed inserts.
- All fourteen axes clear at 3° sampling intervals with hardware present. Threefold axes turn 120°, fourfold axes 90°. Destination symmetries, washer-root walls, screw/nut reach and nut loading are checked.
- Retention probes include intermediate turns, outward/tilted extraction and the inner petal feet against screwed centers alone with 0.15 mm center lift. Measured inner spherical bearing area is approximately 161 mm² per threefold center and 232 mm² per fourfold center.
- A constructive assembly check inserts pieces into an expanded loose shell, then contracts it with centers unscrewed. Physical assembly was also reported successful; the numerical sequence is not a measurement of the exact hand sequence used.
- Layer connectivity covers 0.16/0.42 mm and 0.20/0.45 mm layer-height/line-width combinations. These are geometric checks, not recorded Bambu toolpaths.
- Keyed plugs clear the screws, resist unintended rotation and can be removed after the relevant inlays are removed. The inlays bridge the plug/base joint.
- Exact-size printed inlays are reloaded from their STL exports and checked against the original pocket contours. At nominal contact, an inset audit probe excludes a 0.006 mm skin to account for the body's bounded 0.005 mm mesh simplification; this does not reduce the delivered inlays. Installed exact inlays are tested at flush height through all fourteen axes and the assembly path.
- All 38 DWG sheets were encoded with ODA and independently read back with LibreDWG. DXF contours are closed, SVG units are millimetres, and the foam cutting files are unchanged.

The reports describe finite rigid-geometry checks. They do not measure hand torque, print roughness, elasticity, adhesive strength, fatigue or every possible escape path. Physical feedback supplies the separate evidence about assembly and smooth turning. Original numerical reports retain their scope at the time of computation; the build status above records the later user report.

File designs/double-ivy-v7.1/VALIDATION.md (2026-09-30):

# Validation and physical feedback

The v7 build printed and assembled well, remained captive and solid, and **now turns quite well after repeated turning**. Initial severe binding on two deep axes improved with use. Its cause was not established. See [physical-feedback.json](physical-feedback.json) for the scope and supplied v7 hashes.

v7.1 replaces only eight C/F outer fillets and offers the compatible 5.25 mm nut-seat core as the new-build default. **The corrected fillets have not been reprinted.** The eighteen W/E STLs are unchanged. The correction is outside the retaining shells; its protected-inner and added-volume checks have residuals below 0.01 mm³. All eight corrected STLs are closed single solids and have connected 0.20 mm / 0.45 mm layer graphs. They passed 520 nominal poses after export, with no detected interference; these reports are in `reports/rounding`.

The current core's archived checks in `reports/core` cover nut loading, antirotation, hardware, the preserved envelope and clearance to the exported v7 outer pieces. Its R19.2 sphere and 17.6 mm axle pads are unchanged. The final assembled release also receives a fresh movement check including the supplied core, screws and washers: `reports/motion.json`. Publication checks cover hashes, complete plates, closed meshes and the 27-piece inventory.

## Baseline v7 checks

The archived v7 motion, assembly, hardware, retention, foot and layer-connectivity checks read the actual exported v7 STLs and restore their solved positions with the transforms in `manifest.json`. Each report records the manifest hash and asserts the STL hashes. The original core is loaded from its existing print mesh.

| Check | Coverage and result |
|---|---|
| Meshes and plates | All 26 new pieces are closed, consistently oriented, single-component solids. Four 3MF plates contain exactly the corresponding STL meshes, without overlaps, within a 256 mm bed. Core and stand reference meshes are unchanged. |
| Turns | 536 sampled poses: all four axes at both depths every 3° from solved, plus a 16-move mixed-depth sequence sampled every 10°. Maximum measured intersection was about 0.0000036 mm³, below the 0.002 mm³ numerical tolerance. Includes the old core, screws and washers. |
| Assembly | 27 paths, 3,483 sampled poses. Each F, E, W can enter radially after its inner families; C enters last. Also checks withdrawal of the optional stand. Maximum measured intersection was 0.000341 mm³. |
| Intended retaining hierarchy | 572 isolated-foot checks across both turn types, every 10° on one tetrahedrally representative axis. Each foot meets its intended holder family, F→E→W→C, by 0.4 mm outward displacement. Minimum peak obstruction within a 2 mm pull was 20.26 mm³. |
| Holder displacement | All 22 floating feet tested against their intended holder family at 0, 0.15 and 0.30 mm outward holder displacement: 66 traces. Every foot remained obstructed, with first contact no later than 0.7 mm and peak overlap at least 86.96 mm³ within a 3 mm pull. |
| Other withdrawal directions | All 22 individual radial pulls plus 243 finite outward/tangential and rocking trajectories on representative W/E/F parts, with C lifts of 0, 0.10 and 0.25 mm. All encountered obstruction. This holds other pieces fixed; it is not a proof against every collective escape path. |
| Hardware | Four M3×20 screw/washer stacks fit the old core, original bearing foot and unchanged washer seat. Washer insertion and driver access checked; original nut capture checked. C stems retain a nominal 1.6 mm upper wall around the access bore. |
| Layer connectivity | All 26 print orientations checked at 0.16 mm / 0.42 mm extrusion width and 0.20 mm / 0.45 mm width: 52 connected layer graphs. This is a model of connected extrusion paths, not a Bambu Studio slice or an overhang/support guarantee. |

The finite collision tolerance is a numerical Boolean-volume threshold, not an additional mechanical clearance.

## Bearing webs and necks

The E/W bearing webs are non-retaining spherical backstops. Their nominal inner radius is 19.4 mm around the old 19.2 mm core. The guide primitives were tested against the exact old core, including its nut channels, at **1,968 moving-web poses**, every 3° across all four axes and both turn depths. At every sampled pose, an inward shift of 0.25 mm met the core. The smallest intersection at that shift was 0.254 mm³, increasing to 1.217 mm³ at 0.4 mm in that weakest pose. This gives evidence that the webs bridge the old nut openings rather than dropping into them. It is not a contact-pressure or wear analysis.

A 0.6 mm radius morphological erosion of the common internal C/W/E/F geometry leaves each captured foot connected to its outer body. The same probe on complete guided canonical E/W bodies leaves the near-core bearing portion connected to the main attachment. This is an approximate 1.2 mm connected-thickness probe of faceted geometry, not a mechanical strength simulation. Guide additions are unioned with more than 3 mm³ attachment volume; individual values are in `bearing-attachments.json`.

Opening the receiving grooves for assembly removes **zero volume from the protected captured-foot regions** in the preparation step. The following rounding intentionally softens their edges. The footprint study compares assembly-relief openings on 68/70/72/74 mm cube skins; 72 mm keeps the meaningful assembly openings internal. Tiny Boolean/facet slivers remain in that diagnostic, rather than literal zero area.

## Scope of the conclusion

These checks support a printable, geometrically captured mechanism with the requested assembly order and legal sampled turns. They do **not** establish zero play, smooth friction under load, support quality, fatigue strength, or exhaustive motion/escape behavior in every scramble. The physical build now supplies qualitative evidence of capture, assembly and turning after bedding-in. The eight revised exterior fillets have not yet been physically reprinted.

These original reports are preserved in `reports/baseline-v7`, with their original manifest in `reference/baseline-v7-manifest.json`. They must not be mistaken for newly computed v7.1 reports.

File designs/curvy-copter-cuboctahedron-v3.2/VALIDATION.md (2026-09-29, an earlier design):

# Physical build and geometry checks

On **2026-09-29**, the owner reported: **“The cuboctahedron curvy copter shape mod printed and built very well.”** This confirms successful full printing and assembly. Earlier spherical-retainer test pieces were also reported to work well with the old core. The [physical-feedback record](physical-feedback.json) associates the report with the supplied v3.2 files; exact final slicer settings and optional/reused core selection were not independently verified.

The publication preserves every supplied STL, 3MF, manifest, geometry-generating source file and original numerical report byte for byte. `publication.json` records their hashes. Original reports saying “not yet printed” describe the earlier CAD-check stage; the physical report supersedes that status. Their `assembly_validated: false` still correctly means that no complete insertion path was established numerically. Successful physical assembly does not turn that into a computed path proof.

The preserved exported-mesh checks cover all twelve ordinary 180° turns at 3° increments, a five-step jumbling sequence, a 48-step legal jumbling walk, hardware fit, nut loading, layer connectivity, and spherical retaining faces. Retention probes count only the inner feet, excluding outer-body obstruction. Petals were checked against screwed centers displaced outward 0.15 mm, and corners against petals displaced outward 0.8 mm. These checks address the support chain rather than relying only on a pull against perfectly fixed neighboring floating pieces.

The four center-flange outline corners were measured at three radial stations each: measured tessellated radii span 1.177–1.209 mm for nominal R1.2. The center's inner spherical bearing area remains about 169.05 mm² per part. This is a geometry measurement, not a load rating. Layer-connectivity checks include 0.16/0.42 mm and 0.20/0.45 mm layer-height/line-width combinations; they are not actual slicer toolpaths.

The new publication audit checks supplied-file hashes, quantities, unchanged CAD/reports, license, local documentation links and archive checksums. Since the print geometry is unchanged, the full CAD simulation was not rerun for publication.

The successful build report does not separately establish turning torque, friction, endurance, elastic pop resistance or every possible jumbling state. It supplies physical assembly evidence alongside the finite geometric checks, without converting either into an exhaustive guarantee.

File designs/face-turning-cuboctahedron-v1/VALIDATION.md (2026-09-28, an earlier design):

# Build feedback and validation

On **2026-09-28**, the owner reported that the **face-turning cuboctahedron printed and assembled well**, with one usability limitation: **the square faces are not very easy to turn**. [The physical-feedback record](physical-feedback.json) identifies the associated supplied files. Exact print settings and the chosen optional core were not restated.

The publication preserves the supplied geometry, 3MF layouts, geometry-generating CAD, manifest and original numerical reports byte for byte. `publication.json` records their hashes. The numerical summary's “physical print ... untested” wording describes the CAD-validation stage before this build report; the physical-feedback record above supersedes that status for the supplied v1 parts.

The original exported-mesh checks cover all fourteen axes at 3° turn increments, ordinary-turn destinations, assembly and removable-stand paths, nut loading, hardware clearance, washer-root and bore-wall material, petal retention during turns, tilted extraction, and layer connectivity at 0.16/0.42 mm and 0.20/0.45 mm layer-height/line-width pairs. The `reports/` directory contains the results, and `reports/summary.json` records their successful completion.

Finite rigid-geometry checks do not measure hand torque, friction, elastic retention or endurance. Successful assembly and difficult square-face turns can coexist. Grip and leverage are plausible contributors, but their contribution relative to support finish, screw adjustment and friction has not been isolated.

A vertex-turning **rhombic dodecahedron**, the cuboctahedron's dual, is a possible future exterior with a projecting shape to grasp around each of the same fourteen axis directions. Better grip is an expectation to test, not a measured improvement or an existing printable alternative. No such geometry is included in this release.

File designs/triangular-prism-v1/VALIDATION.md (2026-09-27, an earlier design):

# Validation of the delivered print files

**All listed checks completed on the exported and reloaded meshes.** On **2026-09-27**, the owner reported that this **64 mm non-wavy triangular prism printed, assembled and turns well**. The [physical feedback record](physical-feedback.json) identifies the associated supplied STL files. Exact slicer settings and the chosen optional core were not restated; no endurance or holding-force measurement was reported. The reports are tied to the SHA-256 of `manifest.json`; every STL also has its own recorded hash.

| Check | Result |
|---|---|
| Main puzzle STLs | 21 closed, consistently wound, positive-volume single components |
| Alignment | Same cube rotation as the pentagonal prism, with five D3 turn axes |
| Turning | All 5 axes, then 24 mixed moves; 909 sampled configurations |
| Largest measured turn overlap | 2.2e-05 mm³ (acceptance limit 0.001 mm³) |
| Assembly | 21 radial insertion/stand removal paths, 1659 positions, including core and installed hardware |
| Largest measured assembly overlap | 0 mm³ |
| Washer lands and feet | Full annuli present; shaft, washer loading and hex-key access clear |
| Tight nut loading | Easy entrance, deliberate interference at terminal flats, roof support and rotational obstruction checked |
| Center stalks | Continuous cylindrical annulus around screw passage checked |
| Washer-well roots | Minimum sampled web 3.92 mm |
| Screw heads | Minimum nominal clearance to cube faces 0.58 mm |
| Floating part retention | First aligned rigid radial obstruction at 0.35–0.45 mm of displacement |
| Off-axis retention | Angled pulls and combined rocking/extraction, including 0.10/0.25 mm center lift |
| Mid-turn retention | 30 sets of 13 rigid pull directions across both move families and 0/0.10 mm center lift |
| Separated-neighbor corner capture | All six corners, 13 directions, 0.10 mm screwed-center lift and 0/0.20 mm outward shift of every other floating piece; obstruction curves to 6 mm |
| Radial rounding | R2 exposed arcs checked at 3196 transverse sections, including tracks; worst measured radius error 0.025 mm |
| Layer connectivity | Every main print orientation at 0.16/0.42 mm and 0.20/0.45 mm layer-height/line-width pairs; no secondary printable component above 0.03 mm³ |
| Print plates | Bounds, non-overlap, units and alternate-orientation mesh equivalence checked |

The tip-trimming report records tiny components already detached after rounding. The terminal-trimming report separately records the deliberate removal of about 11.57 mm³ per corner at the three flange tips, eliminating nonprinting webs while retaining broad capture lobes. All checks here use the trimmed exports. Root-web and annulus checks are geometric measurements, not finite-element strength calculations.

The radius check follows the matching circular-arc boundary when a cross-section has multiple intersections. Near-tangent sections can gain or lose a foreground intersection under tiny mesh regularization; comparing only the first intersection can incorrectly compare unrelated surfaces. Independent bidirectional surface samples constrain export fidelity as well.

Motion is sampled every 3° from solved positions and every 6° in the mixed-move sequence. The cuts are surfaces of revolution and the move endpoints respect the D3 axis symmetry; the numerical checks additionally cover the actual clipped, rounded, exported parts and hardware. These checks are not an exhaustive search of every puzzle state or every possible elastic escape path.

Track gaps, nut press fits, friction, screw preload, layer adhesion and support removal still depend on the real print. Fixed-width layer connectivity is not a Bambu Studio toolpath simulation and does not eliminate the need for supports. Print the nut and rotor fit coupons before the complete puzzle. Use gentle initial turns and adjustment; no physical load or lifetime rating is claimed.

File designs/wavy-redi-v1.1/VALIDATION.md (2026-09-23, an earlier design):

# Validation of the delivered print files

All eight validation jobs completed successfully. Each job reloaded the
delivered STLs, checked their hashes and restored their assembly coordinates.
These results apply to the files listed in `manifest.json`.

| Check | Result |
|---|---|
| Printed puzzle solids | 21 closed, consistently wound, single-component meshes |
| Turns | 944 sampled positions over all 8 axes and a 12-move scramble |
| Worst measured turning intersection | 7.16567e-06 mm³; acceptance threshold 0.003 mm³ |
| Assembly | 760 sampled group-loading positions; all passed |
| Capture | All 12 petals blocked under radial pull; inner shoulder checked with up to 0.10 mm axial-piece lift and ±10° rocking |
| Core-root minimum inscribed diameter | 3.38 mm |
| Area at that section | 11.59 mm² |
| Radial-edge fillet | R2 mm across 1023 fitted sections, including the inner track region |
| Extrusion-width connectivity | 0.42 mm line, 0.16 mm layers; total small disconnected estimate 0 mm³ |
| Hardware | Screw, washer and driver paths, complete washer lands and bearing feet, nut-entry gauge and screw engagement checked |
| Cube tips | All eight checked; maximum distance to an intentionally rounded tip 0.627 mm |
| Plates | Within 256 × 256 mm bounds, with nonoverlapping part bounding boxes |

## Why the assembly path works

The hidden profile has nondecreasing distance from the turn axis: the
cutting body is open outward along that axis. Translating a group of all
remaining pieces belonging to that cut keeps the group inside the same
cutting body. The other printed pieces are outside it. Rounding and track
relief remove material and preserve this property. The specific loading
checks additionally include the hub, bearing feet, fitted screws and STL
tessellation. Reverse the recorded removal order to obtain the illustrated
assembly sequence. This does not rely on snapping parts through one another.

## What the checks do not establish

The original v1 was printed and reported to build and turn very well. The
v1.1 nut-seat and exterior-tip changes have not yet been physically tested.
Collision sampling is not a continuous
physical simulation, and capture tests cover the listed pull/rock paths,
not every possible forced extraction. The section-width test is a geometric
approximation, not Bambu Studio toolpaths; supports are still required.
The core-root measurement is a geometric thickness check, not a load or
fatigue rating. Friction, PLA surface finish, support removal and screw
tension need feedback from the actual print.

The 5.25 mm nut seat intentionally interferes with a nominal 5.5 mm nut.
This reduces the slight over-tightness reported for the v1 wavy print. A 5.15 mm
gauge checks the entry path; a rigid collision test cannot predict the
force needed to press the real nut into the plastic.

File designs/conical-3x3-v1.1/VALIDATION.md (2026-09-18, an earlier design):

# Conical 3×3 validation and physical feedback

**Owner-printed:** the owner reported that the reinforced v1.1 printed very well. These STL hashes match the supplied set associated with that report.

The owner report is limited to successful printing. It does not supply a separate
turning assessment, instrumented strength or fatigue result, or an inspection of
the printer's input files. Exact settings and the chosen nut-seat variant were
not restated. [Report and supplied STL hashes](physical-feedback.json).

The numerical reports describe the delivered meshes and their explicit assembly
transforms. Each required report is linked to the manifest by SHA-256.

| Check | Result |
|---|---|
| Required report groups | 10 passed |
| Sampled intended turn and scramble poses | 570 |
| R3 transverse ridge sections | 5234 |
| Largest checked circle error | 0.0247 mm |
| Printable layer-graph cases | 54 |
| Smallest measured screwed-piece root web | 2.04 mm |
| Screw projection beyond locknut | 1.85 mm |

Additional checks cover radial insertion, hardware and driver access, stand
withdrawal, exported mesh fidelity, print-plate placement, and sampled extraction
and rocking paths, including intermediate turn positions and modest center lift.

The web measurement tests 720 angular positions per screwed piece. The six
reinforced centers preserve bearing and retaining dimensions; the other 21
puzzle STLs are byte-for-byte unchanged from v1. See
[the revision report](reports/revision.json) and [root measurements](reports/root-web.json).

Connectivity establishes a continuous solid or a modeled printable path; it does
not establish sufficient mechanical strength. Finite pose samples also do not
prove clearance or retention at every possible configuration. Physical loads,
friction, elastic popping, wear and fatigue need separate testing.

[Aggregate report](reports/validation-summary.json) · [Design](DESIGN.md) ·
[Assembly and printing](README.md) · [Regeneration source](source/README.md)

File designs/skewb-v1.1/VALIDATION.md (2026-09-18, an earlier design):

# Validation and physical feedback — Skewb v1.1

These checks use the exported, reloaded delivery meshes, in millimeters. They
establish sampled geometric fit and explicit assembly routes.

**Owner-tested v1.1:** on 2026-09-18 the owner reported that the trimmed Skewb printed very well and turns very nicely. The STL hashes match the delivered revision associated with that report.

The owner feedback adds a successful physical build and a qualitative assessment
of turning. It is distinct from the computational results below. Exact slicer
settings and nut-seat variant were not restated; holding force, turn torque,
wear life and a corner-cutting angle have not been measured. The report and
original export hashes are in [physical-feedback.json](physical-feedback.json).

| Check | Result |
|---|---|
| STL integrity | 22 closed, consistently wound, positive-volume, single-component meshes |
| Print plates | 9 named 3MF plates within 256 × 256 mm, without bounding-box overlap |
| Alternative orientations | 10 face-down 3MFs preserve the default meshes by rigid transformation |
| Aligned turns | 4 axes × 41 samples over 0–120°, with core, screws and washers |
| Scrambled turns | 16 mixed-axis moves × 21 intermediate samples; signatures updated after each move |
| Largest sampled turn intersection | 6.23e-06 mm³, below the 0.001 mm³ numerical acceptance threshold |
| Whole-piece insertion | All 14 pieces, 79 offsets each, plus stand withdrawal |
| Largest sampled insertion intersection | 2.33e-08 mm³, below the 0.001 mm³ threshold |
| Retention | All 10 floating pieces have positive internal obstruction under outward pull |
| Further retention paths | 114 directional pulls and 72 ramped rocking paths, all obstructed |
| Lifted screwed corners | Retention paths repeated at nominal, +0.10 and +0.25 mm C lift |
| Radial fillets | 2854 exposed transverse arc sections checked; no radius taper in the cutter |
| Largest sampled R3 circle deviation | 0.0209 mm |
| Largest sampled original-CAD vs STL ridge-profile difference | 0.0122 mm |
| Sampled export surface distance after regularization | At most 0.000453 mm bidirectionally |

The first detected nominal radial obstruction is about 0.55 mm for F pieces and
0.50 mm for K pieces. These are sampled pull travel against fixed rigid neighbors,
not looseness measured in an assembled hand-held puzzle. The retention tests use
only inner geometry within radius 30 mm, so the decorative exterior is not credited
as a retainer. The two canonical floating families are probed along 19 directions
and 12 rocking paths at each of three C lifts. This is not an exhaustive search
of every possible combined six-degree-of-freedom escape or flexing of printed feet.

## Floating-corner revision

Only K01–K04 differ from the previous release. The CAD edit is subtraction within
radius 22.262 mm; the exterior shape is unaffected. At 0.16 mm layers and 0.42 mm
fixed extrusion width, the old K01 has six small detached layer-graph components
around its three tips. The revised K pieces have a single connected printable
layer graph in all 40 tested combinations: four pieces, two orientations and five
layer-height/line-width pairs (0.12/0.42, 0.16/0.40, 0.16/0.42, 0.16/0.48, 0.20/0.42).

All tested pull and rocking paths remain obstructed, including lifted C pieces.
The first-contact distances match v1 in these sampled checks. That establishes
geometric retention after trimming, not equal breaking strength or measured force.

Bambu Studio 02.05.00.66's CLI test failed while loading the stock printer/filament
configuration (exit 139). No completed automated Bambu slice or toolpath check
was obtained during that validation run. The later owner report confirms an
actual successful print; its G-code was not inspected here. The layer checks are geometric simulations using a fixed line width;
they do not model Arachne's variable width, bridges, supports or slicer heuristics.
The revised parts still need appropriate support for their normal overhangs.

## Hardware

All four screw envelopes clear the core and each other. Washer insertion and
hex-key access are checked through each C well. The washer land and flat bearing
annulus are present. Each nut has a free outer loading route, intended interference
at its final seat, an axial retaining roof and a clear Ø3 mm press-rod route.
Rotating the nominal hex nut into the pocket walls produces additional geometric
interference; this does not predict the pocket's torque capacity. The alternate
core sizes clear the same mechanism envelope.

## Shape distinction

The minimum sampled exterior RMS difference between pairs, after trying proper
mounting rotations, is 2.685 mm for C,
4.196 mm for F and
2.480 mm for K. Reflections are not identified
with rotations. These are sampled comparisons, not an optimality proof.

## Mesh and sampling limits

The cutter circles are checked in planes transverse to radial ridges, through the
inner track region and toward the exterior. The middle 80% of each exposed arc is
sampled; other fillets, the core cavity and the cube can terminate an arc. Exposure
is selected from pre-export CAD rather than from the mesh being tested. A fillet's
intersection with another surface need not itself be circular.

Export uses 0.001 mm normal-error mesh regularization before float32 STL conversion.
That tolerance is not a bound on the motion of every vertex: nearly zero-thickness
CSG whiskers can disappear. Regularization's added/removed volumes are reported
separately. Bidirectional surface samples compare the regularized export input with
the reloaded STL; the circle/profile checks also compare against original CAD.
Any extra cleanup is recorded per part in the manifest. Finite holes are not filled
as a mesh-repair shortcut. Face-down alternatives use indexed, double-precision
3MF to avoid a second STL quantization.

Turn samples are 3° apart for single-axis tests and 6° for the mixed sequence.
The analytic axisymmetric interfaces motivate intermediate motion, but the numerical
reports are sampled checks, not a formal continuous-motion proof. Small residual
intersection volumes at coincident mesh boundaries are treated as numerical noise.
First-layer section areas are also recorded; they do not predict support performance.

Machine-readable results are in `reports/`. `manifest.json` records dimensions,
orientations and STL hashes. `SHA256SUMS` covers the delivered package contents.

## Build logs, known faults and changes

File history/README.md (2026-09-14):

# V4.2 workspace snapshot (historical)

The owner reported a successful print using v4.2 / 3 mm files on 2026-09-14.
The saved folder was subsequently found to contain exports from different
generation attempts: E01–E03 individual STLs differ from the earlier arrays
and arranged plates. The exact files sent to the printer were not hashed.
This snapshot preserves the available evidence without asserting that all
files formed one consistent printed or verified release. The failed radius
and revision reports are retained as diagnostic evidence.

Use the v4.2.1 publication release for a consistent, digitally verified set.
The later export has not independently been reported printed. Same core,
corners, hardware, exterior face planes and constant-3-mm rounding intent.

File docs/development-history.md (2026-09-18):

# Development history

This project was developed through printed prototypes and feedback. “Printed” below means an owner report, not an instrumented laboratory test.

| Revision | Change | What was learned |
|---|---|---|
| Initial design | 100 mm rotated exterior, conical/flared interfaces, sleeves and inserts proposed | Exterior asymmetry can be designed independently of the basic turn axes. Hardware/access choices still control the interior. |
| v2 | Direct plastic screw pilots, external washer wells, matching flat corner feet | The full cube printed and assembled on the first attempt. Edges nevertheless pulled out easily even while aligned; pieces were sharp and caught. |
| v3 | 80 mm exterior, stepped retaining shoulders, 0.20 mm nominal gap, nonconvex insertion relief, 1 mm exposed-edge rounding | Positive retention and a more compact shell addressed major weaknesses. The assembled mechanism was still very catchy. |
| v3.1 | Removed the extra print flat from the core; retained eight axle pads | A core can print on an intentional axle pad while keeping its other curved areas spherical. |
| v4 | 0.60 mm internal edge rounding, 0.45 mm corner lead-ins, widened tracks swept from unrounded flanges | The owner described the result as very good and requested more alignment relief at the radial ridges. Track clearance and corner adjustment are different controls. |
| v4.1 | 2 mm outer radial-ridge rounding, blended above the protected inner region | The inner track region retained a visibly smaller radius. Protecting too much geometry can preserve the exact snag being addressed. |
| v4.2 | Intended constant 3 mm radial-ridge rounding through the tracks | The owner confirmed a v4.2 / 3 mm print and reported that it printed very well. Saved exports were later found to span different generation attempts; exact printer input hashes were not recorded. |
| v4.2.1 | Consistent publication export, radius checks across the track transitions, closed STL export, MIT project and reusable documentation | Preserves the printed prototype's design intent and unchanged core/corners while making the current export internally consistent and auditable. This exact export has digital checks, not a separate physical print report. |
| v4.3 compact | 64 mm cube and smaller mechanism; DIN985 M3 nuts, DIN912 M3 × 20 screws, 9 × 1 mm washers; main-face gap reduced to 0.03 mm; 0.40 mm track expansion and R3 ridges retained | The owner built it and reports that everything except nut retention feels very nice. About half of the nut seats allow rotation under locknut installation torque. Axial capture and handling ribs do not establish antirotation capacity. |
| v4.3 print orientation | Edge STLs and plates supplied with their inward radial vectors pointing down | This is the owner's preferred print orientation. Publication preserves the delivered geometry and adds the physical feedback; the proposed tighter terminal nut seat is documented as a pending core-only change. |
| Skewb v1 | 64 mm exterior; four screwed C corners, six floating F faces and four floating K corners; integral stepped rails, K → F → C assembly, narrower final nut seats | The Redi's hardware, close main-face gap, wider tracks and R3 ridge construction transfer to another topology, but its rail and insertion geometry require new checks. The K flanges had three thin perforated tips that sliced into isolated, wastefully supported fragments despite connected CAD meshes. |
| Skewb v1.1 | Subtract the three perforated tips from each K corner, retaining the broad capture lobes; all 18 other STLs unchanged | Layer-connectivity checks eliminate the isolated scraps in 40 tested cases. Sampled motion, insertion and retention still pass. On **2026-09-18**, the owner reported that the trimmed Skewb printed very well and turns very nicely. Publication preserves those delivered STL/3MF bytes and records the qualitative result; detailed print settings and measured strength/wear were not supplied. |

Older complete download bundles and the v4.2 workspace snapshot are preserved as historical release assets. The snapshot is not presented as a verified current print set. Its [manifest](../history/v4.2-workspace-snapshot-sha256.json) records the files as found.

One historical metadata error deserves explicit correction: the original v3/v3.1 `design.json` reported a 100 mm side and 0.50 mm gap because a wildcard import overwrote the labels in the builder. Their actual geometry was 80 mm with 0.20 mm nominal gap. Current metadata and source imports are corrected. Historical archives remain identifiable as historical rather than silently rewritten.

OpenSCAD was tried during early development and crashed. The maintained CAD pipeline uses Python, Manifold and Trimesh; OpenSCAD is not required.

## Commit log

2026-09-14 Publish Wonkycube CAD, printable v4.2.1 and mechanism design guide
    [C01.stl, C02.stl, C03.stl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]
2026-09-17 Publish compact v4.3 and document captive-nut fit lessons
    [C-01.3mf, C01.stl, C02.stl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]
2026-09-18 Publish tested Skewb v1.1 and document printable flange tips
    [C-01.3mf, C01.stl, C02.stl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]
2026-09-18 Publish reinforced conical 3x3 and showcase three Wonkycube designs
    [C-01.3mf, C01.stl, C02.stl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]
2026-09-23 Publish tested pentagonal prism and document tuned nut seats
    [C-01.3mf, C01.stl, C02.stl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]
2026-09-23 Publish Wavy Redi with relaxed nut seats and restored cube tips
    [C01.stl, C02.stl, C03.stl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]
2026-09-27 Publish tested 64 mm triangular prism and showcase six cubes
    [C01.stl, C02.stl, C03.stl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]
2026-09-28 Publish tested face-turning cuboctahedron and document square-face grip
    [DO-NOT-PRINT-solved.3mf, P-01.3mf, assembly-stand.stl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]
2026-09-29 Publish tested Curvy Copter cuboctahedron with spherical retainers
    [C-01.3mf, DO-NOT-PRINT-solved.3mf, DO-NOT-PRINT-test-assembly.3mf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]
2026-09-30 Publish Double Ivy with corrected outer fillets and build feedback
    [C-01.3mf, C01.stl, C02.stl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]
2026-10-02 Document reusable 5.25 mm captive M3 nut pocket
2026-10-06 Publish tested rhombic dodecahedron with exact-size 2 mm inlays
    [DO-NOT-PRINT-solved.3mf, DO-NOT-PRINT-with-inlays.3mf, F01-P02.stl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]
2026-10-15 Publish Curvy Copter v4.2 with 1 mm pockets and A4 inlay sheets
